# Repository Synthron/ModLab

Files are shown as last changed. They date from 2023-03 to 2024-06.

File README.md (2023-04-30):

# ModLab

## A modular station for your electronic workbench

The ModLab is designed to be housed in a 19" Rack with 3U.  
It is the improved version of the (failed) Arduino Workstation I built a long time ago.

But now It will be bigger, better and way too complicated.

---

[GitHub](https://github.com/Synthron/ModLab)
[Gitlab](https://gitlab.synthron.de/Synthron/ModLab)

---

**Work in Progress**

---

# To-Dos

## Repo

- [X] Rewrite documentation in english
  - [ ] Write better introduction
  - [ ] explain what exactly the ModLab is
  - [X] update changes for TFT
  - [X] Explain TFT Protocol
  - [ ] Attach Schematics
- [X] Cleanup Repo

---

## Hardware

- [X] Redesign modules with STM32
  - [x] Master Bus Controller with F767
    - [X] V1
      - [X] Review
      - [X] Ordered
      - [X] Assembled
    - [ ] V2
      - [ ] Change LCD connector
      - [ ] omit external SRAM
      - [ ] include header for Reset
  - [x] Diode/LED-Tester
    - [X] V1
    - [X] V2
  - [X] Variable Power Supply
    - [X] V1
    - [ ] V2
      - [X] Fix Relais Footprint
      - [X] Feedback Dividers for correct level
      - [ ] Review
      - [ ] Ordered
      - [ ] Assembled
  - [x] Symmetric Power Supply
    - [X] V1
    - [ ] V2
      - [X] fix negative channel
      - [X] fix CC LEDs
      - [ ] Review
      - [ ] Ordered
      - [ ] Assembled
  - [x] Waveform generator
  - [ ] DSO-138 clone?
  - [X] Electronic Load
  - [ ] Logic Tester
  - [ ] Continuity tester
  - [ ] Speaker Module
  - [x] Termination boards and Bus Extenders

---

## Software

- General
  - [X] Define CAN Protocol
    - [X] Define Command Structure
    - [X] Define Data Structure
- Master Bus Controller
  - [ ] STM32 code
    - [X] USB for Debug
    - [X] LCD
      - [X] Get Nextion Display working
        - [X] UI
        - [X] µC Interface
    - [ ] Busses
      - [X] CAN
      - [ ] SPI - No Usecase so far
      - [ ] I2C
      - [ ] DAC - No Usecase so far
      - [ ] RS485 - No Usecase so far
  - [ ] ESP32 code
    - [ ] comm with STM
    - [X] OTA
    - [ ] basic web interface
- Diode Tester code
  - [X] CAN
  - [X] Testing Sequence
  - [X] ADC
- SymPSU
  - [X] PWM Signals
  - [X] ADC
  - [X] CAN-Interface
- Power SMPS
  - [X] PWM Signals
  - [X] ADC
  - [X] CAN-Interface
- Waveform Generator
  - [X] PWM Signals
  - [X] AD9833
  - [X] CAN-Interface
- Power Monitor
  - [ ] Voltage Measurement
  - [ ] Current Measurement
  - [ ] I2C communication

---

ModLab Lib Tracker:

1. SymPSU
2. Diode-Tester
3. SMPS
4. Load
5. F-Gen

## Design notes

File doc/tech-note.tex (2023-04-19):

% --------------------------------------------------------------------
% Technical Documentation
% Marco Müller
% --------------------------------------------------------------------

\documentclass[11pt, a4paper, listof=numbered, captions=tableheading, headinclude, table, xcdraw]{scrreprt}
\usepackage[utf8]{inputenc}
\usepackage{babel}
\usepackage{tikz}
\usepackage{epigraph}
%\usepackage[T1]{fontenc}
\usepackage{xcolor}
\usepackage{amsmath}
\usepackage{textgreek}
\usepackage[LGRgreek]{mathastext}
\usepackage{array}
\usepackage{color}
\usepackage{graphicx}
\usepackage{float}
\usepackage{helvet}
\usepackage{scrhack}
\usepackage{makecell}
\renewcommand{\familydefault}{\sfdefault}

\setcounter{secnumdepth}{4} % give subsubsection numbers

\setlength{\emergencystretch}{\hsize}
\tolerance=9999

\newcounter{divide}

% für referenziertes Inhaltsverzeichnis
\usepackage[hidelinks, hypertexnames=false]{hyperref}

\usepackage{chngcntr}
\counterwithin*{chapter}{divide}

\renewcommand\epigraphflush{flushright}
\renewcommand\epigraphsize{\normalsize}
\setlength\epigraphwidth{0.7\textwidth}

\definecolor{titlepagecolor1}{cmyk}{.82,.24,0,.11}
\definecolor{titlepagecolor}{cmyk}{0,.33,.98,.2}

\DeclareFixedFont{\titlefont}{T1}{ppl}{b}{it}{0.5in}

\setlength{\parindent}{0pt}

% Seitenränder festlegen
\usepackage[top=1.5cm,bottom=1.5cm,right=2.5cm,left=2.5cm,includeheadfoot]{geometry}

% ---------------------------------------
% Titeldefinition
\newcommand{\Titel}{Documentation\\\vspace{.5mm}ModLab V3.0}
\newcommand{\Caption}{A modular electronics workstation}
\newcommand{\SignateAuthor}{\textit{Made with \LaTeX}}
\newcommand{\Stand}{\textit{Compiled: \today}}
% Sonstiges in titel.ltx und titel-meta.ltx
% ---------------------------------------

% Kopf- und Fußzeile
\usepackage[automark]{scrlayer-scrpage}

% --------------------------------------------------------------------
% Titelblatt
% --------------------------------------------------------------------

\input{titel/titel-meta.tex}
\begin{document}
\input{titel/titel.tex}

\KOMAoptions{parskip=half}
% --------------------------------------------------------------------
% Verzeichnisse
% --------------------------------------------------------------------

\pagenumbering{Roman}
\renewcommand{\thechapter}{\Roman{chapter}}

\setcounter{tocdepth}{1} %Ausblenden von Subsections etc..
\cohead[I Table Of Contents]{I Table Of Contents}
\pagestyle{scrheadings}
\tableofcontents 	\newpage
\cohead[II List of Tables]{II List of Tables}
\pagestyle{scrheadings}
\listoftables 		\newpage
\cohead[III List of Figures]{III List of Figures}
\pagestyle{scrheadings}
\listoffigures 		\newpage
\pagenumbering{arabic}

\stepcounter{divide}

\renewcommand{\thechapter}{\arabic{chapter}}

% Kopfzeilen erst nach den Verzeichnissen

\lohead[\today]{\today}
\cohead[ModLab V3.0]{ModLab V3.0}
\rohead[Synthron]{Synthron}
\pagestyle{scrheadings}

% --------------------------------------------------------------------
% Ab hier der Inhalt
% --------------------------------------------------------------------

\input{chapters/00-vorwort.tex} 			\newpage 	% Vorwort über die Entstehungsgeschichte
\input{chapters/01-rack.tex}				\newpage 	% Der Rackaufbau und Erläuterung
\input{chapters/02-fmas.tex}				\newpage 	% Kurze Ausführung zum FMAS
\input{chapters/03-modlab.tex}				\newpage 	% Systemüberblick und Einführung ModLab, 
\input{chapters/04-der_bus.tex} 			\newpage 	% Backplanebus
\input{chapters/10-modules.tex}				\newpage 	% Modules
\input{chapters/20-protocols.tex}			\newpage	% Protocol
\input{chapters/21-CAN.tex}\newpage
\input{chapters/22-TFT.tex}\newpage
\section{ESP SPI}
\textbf{\textcolor[HTML]{FF0000}{TBD}}

\section{Backplane SPI}
\textbf{\textcolor[HTML]{FF0000}{TBD}}
\subsection{5V SPI}
\textbf{\textcolor[HTML]{FF0000}{TBD}}
\subsection{3V3 SPI}
\textbf{\textcolor[HTML]{FF0000}{TBD}}

\section{I2C}
\textbf{\textcolor[HTML]{FF0000}{TBD}}
\subsection{Standard Mode}
\textbf{\textcolor[HTML]{FF0000}{TBD}}
\subsection{Fast Mode}
\textbf{\textcolor[HTML]{FF0000}{TBD}}

% --------------------------------------------------------------------
% abschließende Verzeichnisse
% --------------------------------------------------------------------
\newpage
\appendix
\pagestyle{empty}
\vspace*{\fill}
\begin{center}
\hrulefill\\
\vspace{4mm}
	\begin{HUGE}
		\textbf{Addenda}
	\end{HUGE}\\
\hrulefill\\
\end{center}
\vspace*{\fill}

\pagestyle{plain}

\chapter{Mainboard Schematic}
\newpage
\newpage
\newpage


\chapter{Bustermination Schematic}


\chapter{Diode Tester Schematic}
\newpage

\chapter{Symmetric Power Supply Schematic}
\newpage
\newpage
\newpage
\newpage
\newpage


\chapter{Switching Mode Power Supply Schematic}
\newpage
\newpage
\newpage


\chapter{Electronic Load Schematic}
\newpage
\newpage
\newpage
\newpage


\chapter{Waveform Generator Schematic}
\newpage
\newpage
\newpage


% --------------------------------------------------------------------
\end{document}

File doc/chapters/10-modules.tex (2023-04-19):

\chapter{ModLab Modules}
This chapter is \textbf{Work in Progress} and thus subject to change at any time!

Here I wanna give you a brief overview over the modules (no particular order). Each one will be discussed in more detail, so no worries. 

I will also mark everything that is currently just a concept or idea with a (c) behind its name. 

\begin{itemize}
	\item Bus Adapter
	\begin{itemize}
		\item 1:1 Extension of the backplane bus with connector at the front
		\item Termination resistors for differential pairs
		\item LED indicators for supply voltages
	\end{itemize}
%-------------------------
	\item Host-Bus-Controller / HBC
	\begin{itemize}
		\item Brain of the ModLab
		\item Master for all backplane interfaces
		\item 5'' TFT LCD with touch
		\item ESP32 Co-Processor
		\item SD card slot for logging and more
		\item USB interface
	\end{itemize}
%-------------------------
	\item Symmetric Linear Power Supply
	\begin{itemize}
		\item Symmetric regulated Voltage
		\item Both CC and CV modes
		\item Controlled via PWM
	\end{itemize}
%-------------------------
	\item Symmetric Switching Mode Power Supply (c)
	\begin{itemize}
		\item Single regilated Voltage
		\item Both CC and CV modes
		\item Controlled via PWM
	\end{itemize}
%-------------------------
%	\item Linear Power Supply (c)
%\begin{itemize}
%	\item Stromversorgung mit größerer Leistung
%	\item Spannungs- und Stromgeregelt
%	\item Co-Prozessor übernimmt Regelung
%\end{itemize}
%-------------------------
	\item Switching Mode Power Supply
	\begin{itemize}
		\item High-current power supply
		\item Both CC and CV modes
		\item Controlled via PWM
	\end{itemize}
%-------------------------
	\item Waveform Generator Analog (c)
	%\begin{itemize}
	%	\item MAX038 als Generatorbaustein
	%	\item Sinus, Rechteck und Dreieck
	%	\item Ansteuerung eventuell über Co-Prozessor
	%\end{itemize}
%-------------------------
	\item Waveform Generator DDS
	\begin{itemize}
		\item AD9833 Waveform Generator
		\item 0.1Hz to 12.5MHz
		\item Sine wave, triangle and square wave
		\item VCA and Output Driver
	\end{itemize}
%-------------------------
	\item Logic Probe Tester (c)
	%\begin{itemize}
	%	\item Kann Pegel registrieren und gibt Pegelhöhe an
	%	\item Kann Low-Power Rechteck generieren um Signalbahnen zu verfolgen
	%	\item Test-Probes mit Pogo-Pins
	%	\item Tastköpfe aus 3D-Drucker
	%\end{itemize}
%-------------------------
	\item Diode Tester
	\begin{itemize}
		\item 4 different constant current sources
		\item capable of creativ characteristic curves
		\item Co-Prozessor übernimmt Regelung
	\end{itemize}
%-------------------------
	\item Electronic Load
	\begin{itemize}
		\item Resistive Load for up to 15A
		\item Two Channels
		\item Load Limiter with thermocouple on Heatsink
	\end{itemize}
%-------------------------
	\item Speaker Module (c)
	%\begin{itemize}
	%	\item Signaltöne für verschiedene Angelegenheiten
	%	\item Hochgefahren, Störung, Durchgang etc...
	%	\item zwei Lautsprecher, einer für Melodie, einer für Signal
	%\end{itemize}
%-------------------------
	\item Oscilloscope
	%\begin{itemize}
	%	\item China Einkanal-Oszi auf Eurokarte portiert
	%	\item Für schnelle Tests von langsamen Signalen
	%\end{itemize}
%-------------------------
\end{itemize}

%------------------------------------------------------------------------------------------------------------------------

\section{Bus Adapter}
The Bus Adapter is one of the first modules. It's main function is to terminate the differential bus lanes. For this reason the Bus Adapter is made twice to terminate each end of the backplane. 

Also it serves as an extension to the backplane, since each module has a connector on its front panel serving as a 1:1 connection to the backplane. This way the slot doesn't get wasted for nearly no function.

In addition to that, each supply voltage has a dedicated LED to show if the voltage is available or if a fuse has blown. 

And that is all there is to it. 

%------------------------------------------------------------------------------------------------------------------------

\section{Host Bus Controller}
The Host Bus Controller (HBC) is the heart of the ModLab. It acts as master for the backplane busses as well as user interface. Since it is quite a busy module, I'll try my best to explain each function seperately

\begin{figure}[H]
	\centering
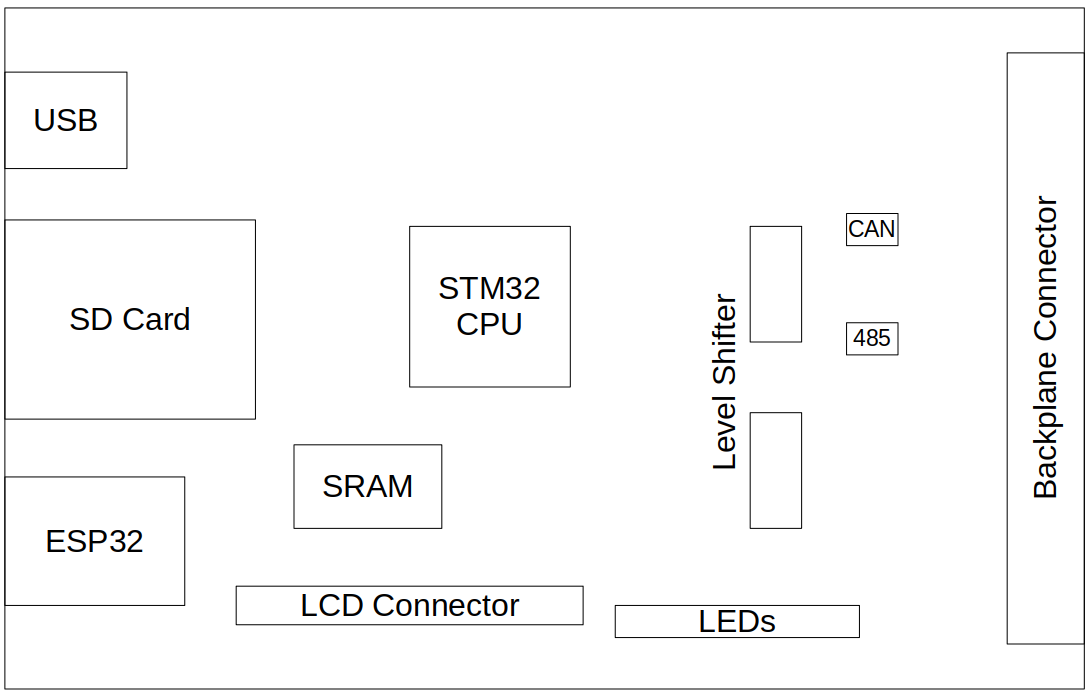
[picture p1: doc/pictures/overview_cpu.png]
		
	\caption{PCB Overview HBC}
	\label{img:HBC}
\end{figure}

\subsection{CPU}

The core of the HBC is the STM32F767 microcontroller. It controls everything in the entire system and provides the user interfaces. 

With 2MB of Flash and 512kB RAM it has more than plenty of storage both for the program code as well as process data and variables. Also at 216MHz max clock rate it is really fast and can process everything in a timely manner. At least that was the thought behind choosing this chip. 

\subsection{Additional Hardware}

Also it has a lot of interfaces which are used on the PCB. Additionally to the interfaces mentioned in chapter 5.4, internally the module has two SPI busses, one for the touch controller and one for the ESP32 coprocessor. A USB interface for debugging and monitoring is inlcuded as well. 

For logging and config storage I included an SD card slot. 

The FSMC (Flexible SRAM Memory Controller) interface of the microcontroller is connected to an external 512k x 16 SRAM chip. I thought about including an external flash memory for application software, but decided against it, since the internal flash seemed more than enough. The external SRAM might come in handy tho if I decide to build modules like logic analyzers which have a ton of data coming in at once. 

The ESP32 module will provide a webinterface for monitoring and diagnosis, but not for controlling the system. This decision was made from a security stand point. 

For Interfacing with the whole system, a 5" Nextion TFT LCD is connected via UART. 

How the protocols on the interfaces will look like, will be discussed in another chapter. 

%------------------------------------------------------------------------------------------------------------------------

\section{Diode Tester}
The Diode Tester is actually quite simple in design. It consists of 4 constant current sources which are tuned to about 2.2mA, 5mA, 10mA and 20mA respectively. Due to this I can enable up to 16 different currents through the Device Under Test (DUT) and even make a crude characteristic curve out of it. 
Following is a simplified schematic of the current sources.

\begin{figure}[H]
	\centering
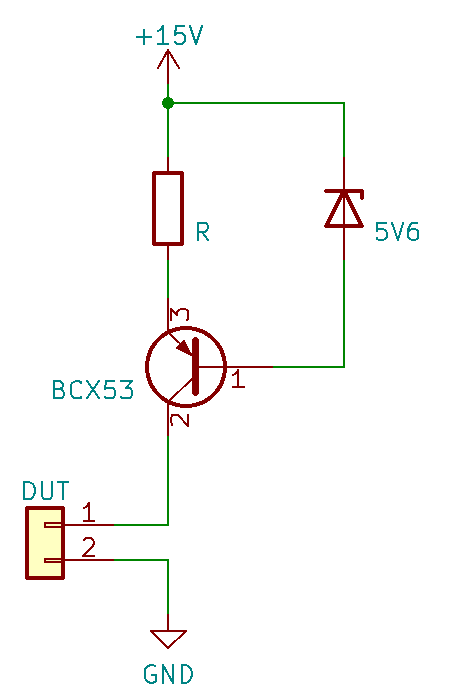
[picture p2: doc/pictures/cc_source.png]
		
	\caption{Current Source Schematic}
	\label{img:CC_Diode}
\end{figure}

The current is configured via the resistor according to Kirchhoff's loop rule. $U_{be}$ of the transistor is typically 0.7V, which means the voltage across the resistor is fixed at $5.6V - 0.7V = 4.9V$. With the values of 2.2k, 1k, 499 and two 499 in parallel respectively, the following currents are available:

\begin{align*}
	\frac{4.9V}{2.2 k\Omega} & = 2.22 mA\\
	\frac{4.9V}{1 k\Omega}  & = 4.9  mA\\
	\frac{4.9V}{499 \Omega} & = 9.81 mA\\
	\frac{4.9V}{249.5 \Omega} & = 19.63 mA\\
\end{align*}

In V1 I tried to enable the sources via a P-channel MOSFET, which for some strange reason didn't work. So I decided for V2 to use small reed relais I had in storage. 

\vspace{1cm}

The module also has an STM32F103 controller on board which is connected to the backplane via CAN and I2C. I did both since I hadn't yet decided which interface I am going to use for the module. 

\subsection{Parameters}
\begin{table}[H]
    \centering
    \begin{tabular}{|c|c|l|}
        \hline
        \textbf{No.}   &   \textbf{Size} & \multicolumn{1}{|c|}{\textbf{Description}}\\ \hline \hline
        10h   &  2 Byte & DUT Voltage at 2 mA \\ \hline
		11h   &  2 Byte & DUT Voltage at 5 mA \\ \hline
		12h   &  2 Byte & DUT Voltage at 7 mA \\ \hline
		13h   &  2 Byte & DUT Voltage at 10 mA \\ \hline
		14h   &  2 Byte & DUT Voltage at 12 mA \\ \hline
		15h   &  2 Byte & DUT Voltage at 15 mA \\ \hline
		16h   &  2 Byte & DUT Voltage at 17 mA \\ \hline
		17h   &  2 Byte & DUT Voltage at 20 mA \\ \hline
		18h   &  2 Byte & DUT Voltage at 22 mA \\ \hline
		19h   &  2 Byte & DUT Voltage at 25 mA \\ \hline
		1Ah   &  2 Byte & DUT Voltage at 27 mA \\ \hline
		1Bh   &  2 Byte & DUT Voltage at 30 mA \\ \hline
		1Ch   &  2 Byte & DUT Voltage at 32 mA \\ \hline
		1Dh   &  2 Byte & DUT Voltage at 35 mA \\ \hline
		1Eh   &  2 Byte & DUT Voltage at 37 mA \\ \hline
		20h   &  1 Byte & Starting Current	\\ \hline
		21h   &  1 Byte & Ending Current \\ \hline
    \end{tabular}
	\caption{Diode Tester Parameter List}
\label{tab:Par-Diode}
\end{table}
\subsection{Operation Modes}
Start Measurement with ``Enable Output'' Command.

\begin{table}[H]
    \centering
    \begin{tabular}{|c|c|l|}
        \hline
        \textbf{Mode}   &  \multicolumn{1}{|c|}{\textbf{Description}}\\ \hline \hline
        0   &  \makecell[l]{Single Value Measurement \\ Starting Current only}\\ \hline
		1   &  \makecell[l]{Coarse Characteristic Curve \\ Starting Current to Ending Current \\ Only Hardware Sources enabled}\\ \hline
		2   &  \makecell[l]{Medium Characteristic Curve \\ Starting Current to Ending Current \\ Every other possible current}\\ \hline
		3   &  \makecell[l]{Fine Characteristic Curve \\ Starting Current to Ending Current \\ Every possible current}\\ \hline
    \end{tabular}
	\caption{Diode Tester Parameter List}
\label{tab:Modes-Diode}
\end{table}
\section{Waveform Generator DDS}
For most of the design I have to thank ``Daumemo'' from \textcolor{blue}{\href{https://daumemo.com}{daumemo.com}}. I wanted to use the AD9833 waveform generator IC and his guide helped me design the circuit around it. 

The board mainly consists of the STM32F103 controller, the AD9833 signal generator, a VCA (voltage controlled amplifier) and an output amplifier. Gain and Offset are controlled via PWM, the Interface to the AD9833 is SPI. 

The Signal Generator is capable of generating Sine, Triangle and Square waves from 1Hz up to 12.5MHz with a 1Hz resolution. 

\subsection{Parameters}
\begin{table}[H]
    \centering
    \begin{tabular}{|c|c|l|}
        \hline
        \textbf{No.}   &   \textbf{Size} & \multicolumn{1}{|c|}{\textbf{Description}}\\ \hline \hline
        10h   &  4 Byte &  Set Frequency [1Hz]\\ \hline
		20h   &  2 Byte &  Set Vout Peak-Peak [0.1V]\\ \hline
		30h	  &  2 Byte &  Offset Voltage [0.1V] \\ \hline
    \end{tabular}
	\caption{AD9833 Parameter List}
\label{tab:Par-Waveform9833}
\end{table}
\subsection{Operation Modes}
\begin{table}[H]
    \centering
    \begin{tabular}{|c|c|l|}
        \hline
        \textbf{No.}   & \multicolumn{1}{|c|}{\textbf{Description}}\\ \hline \hline
        0h   &  Square Wave\\ \hline
		1h   &  Sine Wave\\ \hline
		2h	 &  Triangular Wave \\ \hline
    \end{tabular}
	\caption{AD9833 Waveforms List}
\label{tab:mode-Waveform9833}
\end{table}

\section{Symmetric Linear Power Supply (SymPSU)}
The design for the symmetric power supply is derived from the user ``The Big One'' over on \textcolor{blue}{\href{https://hackaday.io/project/4154-bench-power-supply}{Hackaday}}. I adopted it to my STM32 controller and to 3V3 supply voltage. Also I switched the control voltage generation from a dedicated DAC to the PWM-channels of the STM32. I am using the internal ADC on the STM32 as well. 

With these design changes, the SymPSU can provide the following voltages:
\begin{itemize}
	\item Positive voltage
	\begin{itemize}
		\item 0 to 12V @ 0 to 1.2A
	\end{itemize}
	\item Negative voltage
	\begin{itemize}
		\item 0 to -12V @ 0 to 1.2A
	\end{itemize}
\end{itemize}

After tweaking the code, I programmed the following resolutions:

\begin{itemize}
	\item Voltages
	\begin{itemize}
		\item 10 mV / step
	\end{itemize}
	\item Currents
	\begin{itemize}
		\item 10 mA / step
	\end{itemize}
\end{itemize}

I am quite happy with these specs, but will likely tweak the design in the future a bit. I still have some issues that are currently fixed in software, rather than in hardware. 

\subsection{Parameters}
\begin{table}[H]
    \centering
    \begin{tabular}{|c|c|l|}
        \hline
        \textbf{No.}   &   \textbf{Size} & \multicolumn{1}{|c|}{\textbf{Description}}\\ \hline \hline
        10h   &  2 Byte &  Set Positive Voltage [mV]\\ \hline
		11h   &  2 Byte &  Set Positive Current [mA]\\ \hline
		12h   &  2 Byte &  Set Negative Voltage [mV]\\ \hline
		13h   &  2 Byte &  Set Negative Current [mA]\\ \hline
		20h   &  2 Byte &  Measured Positive Voltage [mV]\\ \hline
		21h   &  2 Byte &  Measured Positive Current [mA]\\ \hline
		22h   &  2 Byte &  Measured Negative Voltage [mV]\\ \hline
		23h   &  2 Byte &  Measured Negative Current [mA]\\ \hline
    \end{tabular}
	\caption{SymPSU Parameter List}
\label{tab:Par-SymPSU}
\end{table}

\section{Switching Mode Power Supply}
This Power Supply is based on a TL494 PWM Control Circuit. The PWM Controller is getting the reference voltages for Output Voltage and Current from the STM32 via filtered PWM signals. This way a complicated and possibly slow and inaccurate software PID regulator is avoided while the circuit complexity is held at a minimum. A voltage divider is generating the feedback voltage, while a high-current shunt and differential amplifier is generating the feedback voltage for the current. 

The following specs were set for Rev 1. This module will need a redesign in order to fix some mistakes.

\begin{itemize}
	\item Voltage
	\begin{itemize}
		\item 2 .. 22 V Output
		\item 10 mV resolution
	\end{itemize}
	\item Current
	\begin{itemize}
		\item 0 .. 5 A Output
		\item 10 mA resolution
	\end{itemize}
\end{itemize}

\subsection{Parameters}
\begin{table}[H]
    \centering
    \begin{tabular}{|c|c|l|}
        \hline
        \textbf{No.}   &   \textbf{Size} & \multicolumn{1}{|c|}{\textbf{Description}}\\ \hline \hline
        10h   &  2 Byte &  Set Voltage [10mV]\\ \hline
		11h   &  2 Byte &  Set Current [10mA]\\ \hline
		20h   &  2 Byte &  Measured Voltage [10mV]\\ \hline
		21h   &  2 Byte &  Measured Current [10mA]\\ \hline
    \end{tabular}
	\caption{SMPS Parameter List}
\label{tab:Par-SMPS}
\end{table}

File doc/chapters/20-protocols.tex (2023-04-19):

\chapter{Interface Protocols}
As the system is quite big and has a lot of interfaces, here will be the place to discuss all these. 

Mainly the USB-Interface, SPI-Interface for the ESP32-Communication and CAN-Interface are of interest. But also the secondary I2C and general SPI interfaces will be defined here. 

\section{USB Monitor}
\textbf{\textcolor[HTML]{FF0000}{TBD}}

USB is currently only used to log the CAN traffic of the system, if the debug-option on the display is set. This will be expanded in the future by a complete USB monitor which will have many different capabilities such as sending CAN frames, setting variables inside the Mainboard and basically letting the ModLab be controlled via USB. 

More on this will be a subject for the future tho.

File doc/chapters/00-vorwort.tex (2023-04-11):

\chapter{Introduction}

This documentation is descibing the origins, design choices and inner workings of the ModLab. The ModLab is a modular electronics workstation designed from scratch and built with mostly readily available parts. 

It is the successor of my Arduino Workstation which was meant to be a better version of the FMAS (\textit{\textbf{F}lexibles \textbf{M}odulares \textbf{A}usbildungs-\textbf{S}ystem}, Flexible Modular Training System) I made during my apprenticeship at the Karlsruhe Institute of Technology. The backplane on the FMAS consisted entirely of AC voltages and one 9V DC voltage which is not really ideal. Also it was all pure logic with no programmable parts. This made it quite functional but stupid (not dumb, but no programmable parts), so I decided to improve on it. 

With the ModLab I wanted to finally build my dream system. With the motto ``absolutely over-engineered'' it is supposed to be powerful, better planned and more intelligent. Also the 19``-Rack houses the FMAS as well, to show the roots of it (and also I didn't want to scrap it because of nostalgia). 

The Arduino Workstation was my first attempt and (from my current perspective) served only as a proof of concept. My skills were quite low at that time and all I knew was Arduino, so I went with that. It kinda worked, but was not really useful and since I made some bad design choices, I had to scrap it. But it was a start and laid out a foundation. 

V2 isn't really documented, because a) it was utter crap and b) it didn't work. I used an Arduino DUE board as main controller which did the job, but not really well\dots

The current version is V3 and is under development. It uses primarily STM32 controllers, but still has the capability of using other controllers as well. 

Before I start talking about all the modules, I want to talk a bit about the FMAS and the Rack itself, so bear with my ramblings and enjoy reading.

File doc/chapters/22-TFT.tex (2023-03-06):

\section{TFT Display}
The Communication Interface with the TFT display is a 5V TTL UART with 250.000 baud of standard 8N1 protocol.

\subsection{HBC to TFT}
For sending commands or instructions to the TFT display, everything needs to be in ASCII followed by 3 Bytes of 0xFF. 

Nearly all commands directly set properties of the elements placed on screen. For example setting the value of a floating point number (here: Element name x1) with two decimal places to the value ``3.30'' would be as follows:

``\textcolor{orange}{x1.val=330}''

Note, that no decimal point is set. The display can only handle integer numbers. Decimal points are handled by the corresponding number box element on screen. 

Here is an overview of the most important commands for Interfacing. All examples are made with textbox t1 and float number x1.

\begin{table}[H]
    \centering
    \begin{tabular}{|c|l|}
        \hline
        \textbf{Command}  & \multicolumn{1}{|c|}{\textbf{Description}}\\ \hline \hline
        t1.txt=``foo'' & set text \\ \hline
        t1.aph=127 & set opacity to fully visible \\ \hline
        x1.val=330 & set numeric value \\ \hline
        vis t1,0 & set textbox invisible. a 1 at the end makes it visible again \\ \hline
    \end{tabular}
\label{tab:tft_overview}
\end{table}

\subsection{Change Device Page}
So far, every module class has its own page on the display. So only these modules need to be actively monitored. 

If the user changes the page, the following command will be sentby the TFT: 

``\textcolor{orange}{0x55 0x\#\#}''where \#\# is the following number:

\begin{table}[H]
    \centering
    \begin{tabular}{|c|l|}
        \hline
        \textbf{Number}  & \multicolumn{1}{|c|}{\textbf{Description}}\\ \hline \hline
        00h & Home Screen / General Settings\\ \hline
        01h & Diode Tester \\ \hline
        02h & Function Generator \\ \hline
        03h & Symmetrical Power Supply \\ \hline
        04h & Switching Mode Power Supply \\ \hline
    \end{tabular}
\label{tab:tft_pagecmd}
\end{table}

\subsection{Set Input Process Data}
Depending on the module, this command can have a variable length of data trailing it. The general instruction across all modules begins with ``\textcolor{orange}{0x5C}''.

\begin{table}[H]
    \centering
    \begin{tabular}{|c|l|}
        \hline
        \textbf{length}  & \multicolumn{1}{|c|}{\textbf{Description}}\\ \hline \hline
        1 byte & Module ID\\ \hline
        1 byte & Operation mode \\ \hline
        1 byte & Start Current Index \\ \hline
        1 Byte & Stop Current Index \\ \hline
    \end{tabular}
\caption[Data Structure Diode Tester]{Data Structure Diode Tester}
\label{tab:tft_diode_5C}

\end{table}
\begin{table}[H]
    \centering
    \begin{tabular}{|c|l|}
        \hline
        \textbf{length}  & \multicolumn{1}{|c|}{\textbf{Description}}\\ \hline \hline
        1 byte & Module ID\\ \hline
        4 byte & Frequency - LSB first \\ \hline
        2 byte & Amplitude - LSB first \\ \hline
        2 byte & Offset - LSB first \\ \hline
    \end{tabular}
\caption[Data Structure Function Generator]{Data Structure Function Generator}
\label{tab:tft_fgen_5C}
\end{table}

\begin{table}[H]
    \centering
    \begin{tabular}{|c|l|}
        \hline
        \textbf{length}  & \multicolumn{1}{|c|}{\textbf{Description}}\\ \hline \hline
        1 byte & Module ID\\ \hline
        2 byte & Positive Voltage - LSB first \\ \hline
        2 byte & Positive Current - LSB first \\ \hline
        2 byte & Negative Voltage - LSB first \\ \hline
        2 byte & Negative Current - LSB first \\ \hline
    \end{tabular}
\caption[Data Structure Symmetric Power Supply]{Data Structure Symmetric Power Supply}
\label{tab:tft_sympsu_5C}
\end{table}

\subsection{Set Output}
The Set Output instruction only exists for modules that actually have a disconnectable output. The command generally follows the format ``\textcolor{orange}{0x50 0xIS}'', where I is the module sub-ID (numbered 1-4) and S is the state of the output (0 = off, 1 = on). 

\subsection{General Settings (Home Screen)}
General settings are mostly for debug purposes, but can be activated and deactivated on the home screen. The instruction begins with ``\textcolor{orange}{0x5A}'' and is followed by the data below:

\begin{table}[H]
    \centering
    \begin{tabular}{|c|l|}
        \hline
        \textbf{Data}  & \multicolumn{1}{|c|}{\textbf{Description}}\\ \hline \hline
        10h & Disable CAN-Log over USB \\ \hline
        11h & Enable CAN-Log over USB \\ \hline
        20h & Disable TFT-Log over USB \\ \hline
        21h & Enable TFT-Log over USB \\ \hline
        30h & Don't simulate missing modules \\ \hline
        31h & Simulate all missing modules \\ \hline
    \end{tabular}
\label{tab:tft_5A}
\end{table}

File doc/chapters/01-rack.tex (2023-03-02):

\chapter{The Rack}
As I said in the introduction, the ModLab actually consists of two parts. To keep it simple, I will do the following: If I speak about the ModLab, I mean the ModLab itself in the upper 6U. The rack itself (which will be explained here) and the FMAS are talked about seperately. 

So now let's talk about the rack.

\section{The Idea}
When I sat down at the drawing board (ok, I admit, it was Excel...) and the first thoughts in mind had, I quickly decided to make everything just bigger. The reason was, that just one 3U rack was a bit too small (e.g. the FMAS rack only had 6 slots, but 12 available modules). Coincidentally I got my hands on a 20U 19``-rack which should be plenty for my use. But now there was a new issue: next to being big and heavy, I needed to include an electric installation for the subsystems. But this will be tackled a bit later.

\section{Planning it out}
Planning out the sections of the rack was done in Excel, so no big calculations for you here, but oh well\dots

So I had 20U to spend and I had a lot to put in there. Thankfully, the rack has a front and a back side. For convenience I decided the ``user side'' would be only on the front, the installation and support systems would be on the back. The first thought was that the whole front would consist of 3U subracks, but that would be a bit much and I still needed the control circuits as well as cable channels, power supplies etc. 

I decided to dedicate two 3U subracks to the ModLab and the FMAS respectively, this would reserve 5U for the control panel and cable management. This way, I can save up space on my workbench by storing the FMAS as well as having plenty of space for the ModLab modules.

After a bit of time, I came up with the following. I am quite happy how it turned out, so this will hopefully last until the end of it.

\begin{table}[H]
\centering
\begin{tabular}{|r|c|c|}
\hline
\textbf{U}	&	\textbf{Front}	&	\textbf{back}		\\ \hline \hline
20	&			&	Cover Plate		    \\ \cline{1-1}
19	&	ModLab	&	Power Supplies		    \\ \cline{1-1}
18	&			&	24V \& 5V		    \\ \hline
17	&			&	Cover Plate		    \\ \cline{1-1}
16	&	ModLab	&	Power Supplies	    \\ \cline{1-1}
15	&			&	15V \& -15V	        \\ \hline
14	&			&	Cover Plate         \\ \cline{1-1}
13	&	Control Panel	&	Filter		\\ \cline{1-1}
12	&			&	Fuses			        \\ \hline
11	&	    	&	            		\\ \cline{1-1}
10	&	DIN-Rail	&	DIN-Rail		\\ \cline{1-1}
9	&	        &                   	\\ \cline{1-1}
8   &           &                       \\ \cline{1-1}
7	&	Cable Channel	&	Cable Channel		\\ \hline
6	&			&	Cover Plate		    \\ \cline{1-1}
5	&	FMAS	&	Voltage Regulator   \\ \cline{1-1}
4	&			&	Fuses	        \\ \hline
3	&			&	Cover Plate		    \\ \cline{1-1}
2	&	FMAS	&	Mains Connector	    \\ \cline{1-1}
1	&			&	Transformer			    \\ \hline

\end{tabular}
\caption{Rack Overview}
\label{tab:Rack Overview}
\end{table}

\section{Construction}
So I ordered everything I needed and took some time to draw schematics, drill out the cover plates, assemble everything and soon I was done.

Well, if only it was that easy\dots

I took my time for every step just to avoid big errors. I made the electric schematic with the software ``QElectroTech'' and even of this schematic, there are many revisions. 

With the plan done, I finally knew what devices and how many terminal blocks I needed. With this in mind I was able to prepare the cover plates and assemble them. In the meantime I designed the backplane for the ModLab, so I could already order them and assemble the subracks. 

The control panel is used to enable power to the different parts of the rack as well as being home to the most important big red ``OH SHIT''-button. This way, only the parts that will be used are powered. The main control voltage is enabled by a seperate switch for a bit more extra safety. 

The switched power supplies for the ModLab made me some headaches. According to their datasheets they can use up to 40A at 230V in the moment of power-up. Since I got four of them in parallel, I was worried about the 160A current spike in the mains blowing the fuses in my fusebox. So I got a current limiter which is actively limiting the current during the first 70ms of power-up and then switching over to unlimited. This will definitely save my fusebox as well as the cables in the wall (and not to forget the contacts in the relais making the connections). 

The transformer for the FMAS is the original one used for it, so the old rack for it got completely disassembled. 

\vspace{1cm}

While the power lines for the FMAS are soldered directly to the backplanes of the subracks, I decided to use high-current DIN 41612 H15-connectors for the ModLab. This way I can partially disassemble the rack for transportation or make it easier to make changes or upgrades to the rack or subracks. Also the connectors are made for use in 3U subracks, so easy to implement and with the use of cable slugs really modular.

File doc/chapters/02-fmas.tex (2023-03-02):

\chapter{FMAS}
Now let's talk about the FMAS, what it is and why I keep in in my inventory.

\section{Background}
The FMAS, or \textit{\textbf{F}lexibles \textbf{M}odulares \textbf{A}usbildungs-\textbf{S}ystem} (Flexible Modular Training System), was part of my apprenticeship at the Karlsruhe Institute of Technology (KIT). It was used to teach how to design schematics, how to draw layouts and how to make PCBs (yes, we etched our own PCBs). Furthermore we were taught how to use measurement equipment, since once a PCB didn't work, the trainer basically just told us ``here are multimeter and oscilloscope, find your error''. As rude as that sounds, it made us think about the circuit, trace the signals around and see where we made the error. 

The FMAS itself was built in a 3U rack with full enclosure, including the transformer, fuses and a regulator. We trainees built them ourselves from the provided kits.

The further along we were with training, the more modules we had for it. During vacation when vocational school was closed or when we had nothing better to do (which happened to me a lot. I was a big nerd and quite fast compared to my fellow trainees) we made the modules for the FMAS, the documentation for it (after 4 or 5 modules, we had quite a good template for it, so that wasn't too much work) and then asked for the next project. 

\section{The System}
The FMAS itself was not up-to-date or highly integrated. The backplane bus consisted of 9V DC as well as 12V, 24V and 20V-0-20V AC voltages. All the other available lanes were unconnected and unused. So it got me thinking. 

The modules themselves were completely discrete, so no programmable ICs or microcontrollers. A big advantage in case of there were no software bugs and to be honest, the circuits just \textit{worked}. Also it was not necessary to contemplate life choices over forgotten semikolons in the code while debugging for days with not much knowledge about programming. It just made life to our trainers and for us way easier. 

The disadvantage I see on the concept itself. Nearly only AC voltages on the backplane means that we had to rectify, filter regulate the voltage on nearly every module. Also there was lots of space on the backplane to make something interesting. With relatively low effort one could connect the modules over serial interfaces with one another and make something interesting and a little bit more intelligent and up-to-date. 

But as the motto goes: ``never change a running system'', so my trainers were not willing to change it.

\section{Modules}
The modules themselves are nothing special, but I will give you a list of them here. 

\begin{itemize}
\item Power Supplies: simple power supplies with LM317 and LM337 as well as one with LM723
\item LED-Tester: Current Source and Voltmeter
\item Waveform Generators: Discrete (fixed frequency) in different designs as well as a X2206CP-function generator
\item Signal Tracer: a square wave generator with integrated speaker
\item Logic Probe Tester: shows the logic level on a trace, simple discrete circuit
\item LED-dice: your standard 1-6 dice...
\item Continuity Tester: basically the same as the Signal Tracer
\item other useless stuff like thermometers etc...
\end{itemize}

As you can see, some are useful, others are just for fun. 

In the end I decided to discard the more useless modules because they really are just your basic ``My First Electronics Project'' kind of type\dots

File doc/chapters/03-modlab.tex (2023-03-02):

\chapter{ModLab}
Okay. As I already said, I didn't like the idea of a completely discrete system. During my second year of training (it was 3 years total) I was already done with all the FMAS modules and my instructors didn't really know what to do with me. So I proposed to develop my own system and thus the ``Arduino Workstation'' was born. I made a LOT of bad design choices back then which resulted in it being labeled a proof of concept. After that I wanted to make a better one with the though of ``overengineered and thought out as much as possible'' in mind. Obviously I don't plan \textit{everything} in advance for years and then build everything at once in the end, but I definitely put more thought into designing it and keeping it as modular as possible. Also I try to avoid bottlenecks and major design errors by thinking not only about the module itself, but the I always have the whole system in mind. 

And because of this, I decided to make it bigger. Not only in dimensions, but also in effort. The ModLab is my long-term project which will grow and improve over time with no fixed deadlines and goals. 

And that is how this project came to be.

\section{Lessons Learned from the Arduino Workstation}
\subsection{No virtual Grounds!}
A huge error was my thought, that +12V and -12V can be used as 24V. With some effort this surely is possible, but it includes a whole lot of difficulties and things to consider. 

So why bothering with that? Just use a fixed 24V rail on the backplane and boom, done.

\subsection{No hand-wired backplanes!}
I don't think I have to talk a lot about that\dots

The backplane of the Arduino Workstation was handwired with all 32 pins across several connectors. Suffice to say that I had some connection issues and it was a work I don't want to do again. Making a PCB is definitely easier and well designed way more modular. 

\subsection{Planning, Planning, Planning}
The old system was just made up as I went. Nothing was considered, I just wanted to play around. 

Now everything is planned through, difficult circuits are simulated first and every design will get a review. This will help avoiding major errors and hopefully ensures the success.

\section{What will be different?}
First of all, the planning. This part will be a more elaborate and thorough, which is why this project will take some time. 
Also I want to digitalize a lot more. In the Arduino Workstation, I still used potentiometers and buttons as interfaces and regulators, so a lot of hands on manipulation. This will be changed with digi-pots as well as DACs or PWM. 

Also I went away form Arduino. Actually I scrapped AVRs as a whole. Most things will use a more powerful STM32 controller to help with timing and speed. 

\vspace{1cm}

Nonetheless maybe some AVRs or PIC microcontrollers will find there way into the system. Not for things that need a lot of processing power, but nostalgia can go a long way and if they fit the function, why not.

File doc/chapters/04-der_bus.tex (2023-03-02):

\chapter{The Bus}
The Bus, or more specifically the backplane bus, is connecting all the modules together. It has all necessary supply voltages as well as all traces for the IO. For this reason, this part took a while.

\section{Voltages}
In order to keep things simple but functional, I decided to plate 4 voltages on the bus. What they are and there uses are outlined below.

\subsection{5V}
I don't think this needs a lot of explanation. Even tho most modules will run on 3V3, I might want to use other controllers or peripherals which run on 5V. For the most part, I will use Low-Dropout regulators to go to 3V3, even tho there will be quite a few of them. 

The Power Supply for the 5V can provide up to 15A, but I will put a 10A fuse in line. I think this will be more than enough for my uses.

\subsection{24V}
What would be a big project without decent power? Correct: BORING. So, especially for bigger power supplies, I included 24V. This will have a 10A fuse as well, I don't think I will need much more for most projects. And if I will have some really power-hungry ideas in the future, they should have an integrated power supply anyways. 

\subsection{Symmetric 30V (-15V..+15V)}
Ok, some of you might ask ``what the hell is that even used for???''

Hear me out. Even tho I am way more comfortable with digital circuits, there exists something called analog circuits. And especially for these I might need these voltages a lot. Examples would be amplifier circuits, waveform generators as well as different IO interfaces. 

Also I want to explore more power supply designs for negative voltages, this can come in handy. 

\section{Interfaces}
The modules need to talk to each other, therefore there have to be some interfaces on the bus. To keep it modular, I decided to include several different ones. These are explained in a bit more detail here.

\subsection{I2C}
I2C (or $I^2C$, IIC, \textit{Inter Integrated Circuit} etc..) is one of my favourite interfaces, because it is simple, easy to implement and I worked with it a lot. It supports up to 128 different nodes which is more than plenty and doesn't need a whole lot of chip-select signals. 

Actually I implemented two I2C interfaces, one at 100kHz standard frequency and one at 400kHz. 

Even tho it is a widely used interface for tons of peripherals, it will be mainly used as backup or for small periodical data packets. This will keep the main interface more free for other uses. 

\subsection{RS485}
RS485 is included, because I want to explore a protocoll called ModBUS. This might come in handy for other projects. Maybe this will be used more later, for now it is just there to have it. 

\subsection{SPI}
SPI (Serial Peripheral Interface) is a really common bus for a lot of things. It can go to quite high data rates, but also needs a chip-select for every node. For this reason, some dedicated IO lines are used as Chip Selects. If they are used as-is or if I decode them is still subject to debate. 

Also I actually have two SPI interfaces on the bus. one at 5V and one at 3V3. This will help integrating different controllers or peripherals to the system without a lot of level-shifting and thus introducing delays and synchronization issues. 

\subsection{CAN}
The CAN (Controller Area Network) interface will be the main workhorse interface of the system. It can support a lot of nodes and due to it being a differential interface should work pretty reliably. 

The downside is, that it needs a transceiver for every node but oh well. 

My current plan is to use the ISO-TP protocol for it. This way I can send more than a maximum of 8 bytes per data transfer, but this might slow down the interface a bit. Because of this, I will operate the interface at 1Mbit/s datarate. 

\section{I/Os}
Of course I will need some general IOs on the bus to control different things. Here a small summary. 

\subsection{Digital}
There are 6 general IOs on the backplane. These can be used as status signals (error, interrupt) or to do some fun things I still have to come up with. 

Also there are 6 dedicated Chip-Selects for the SPI interfaces. This way I can selectively address them. 

All IOs are 5V compatible.

At first I wanted to include some form of slot address encoding, but yeah... that idea was scrapped pretty early because I would need quite a few pins for that. 

\subsection{DACs}
Two DAC-channels from the Host Bus Controller (more on that later) are also on the bus. My plan is to use them with a speaker module to make really annoying system notification, like startup-melodies, error-notifications, acoustic signals for different events from submodules etc. 

Let's see what will come out of that.

\section{Layout}
Ok, now that we have talked about what signals will be on the backplane, let's see how it is layed out. 

I settled with the DIN 41612 64pin A-C connectors. These will fit well with the Rack-design as well as provide enough pins for everything. 

I decided to give the supply voltages 4 pins each to maximize possible current draw. Also I placed some GND-pins in the middle as well. This left only a few pins for all the signals. 

here is what I came up with.

\begin{table}[H]
\centering
\begin{tabular}{|r|c|c|l|}
                              	& 	a  	& 	c 	&   										\\ \hline \hline
\cellcolor[HTML]{FE0000}5V    	& 	1  	& 	1  	& 	\cellcolor[HTML]{FE0000}5V       		\\ \hline
\cellcolor[HTML]{FE0000}5V    	& 	2  	& 	2  	& 	\cellcolor[HTML]{FE0000}5V       		\\ \hline
\cellcolor[HTML]{0066ff}GND   	& 	3  	& 	3  	& 	\cellcolor[HTML]{0066ff}GND     		\\ \hline
\cellcolor[HTML]{0066ff}GND   	& 	4  	& 	4  	& 	\cellcolor[HTML]{0066ff}GND     		\\ \hline
\cellcolor[HTML]{FE0000}24V   	& 	5  	& 	5  	& 	\cellcolor[HTML]{FE0000}24V     		\\ \hline
\cellcolor[HTML]{FE0000}24V   	& 	6  	& 	6  	& 	\cellcolor[HTML]{FE0000}24V     		\\ \hline
\cellcolor[HTML]{0066ff}GND   	& 	7  	& 	7  	& 	\cellcolor[HTML]{0066ff}GND     		\\ \hline
\cellcolor[HTML]{0066ff}GND   	& 	8  	& 	8  	& 	\cellcolor[HTML]{0066ff}GND     		\\ \hline
\cellcolor[HTML]{9B9B9B}CAN+   	& 	9  	& 	9  	& 	\cellcolor[HTML]{9B9B9B}CAN-       		\\ \hline
\cellcolor[HTML]{F8FF00}IO0   	& 	10 	& 	10 	& 	\cellcolor[HTML]{F8FF00}IO1          	\\ \hline
\cellcolor[HTML]{9B9B9B}SDA\_FM  	& 	11 	& 	11 	& 	\cellcolor[HTML]{9B9B9B}SCL\_FM            	\\ \hline
\cellcolor[HTML]{F8FF00}IO2  	& 	12 	& 	12 	& 	\cellcolor[HTML]{F8FF00}IO2            	\\ \hline
\cellcolor[HTML]{9B9B9B}SDA    	& 	13 	& 	13 	& 	\cellcolor[HTML]{9B9B9B}SCL             	\\ \hline
\cellcolor[HTML]{F8FF00}IO4    	& 	14 	& 	14 	& 	\cellcolor[HTML]{F8FF00}IO5            	\\ \hline
\cellcolor[HTML]{9B9B9B}RS485+    	& 	15 	& 	15 	& 	\cellcolor[HTML]{9B9B9B}RS485-           	\\ \hline
\cellcolor[HTML]{0066ff}GND   	& 	16 	& 	16 	& 	\cellcolor[HTML]{0066ff}GND            	\\ \hline
\cellcolor[HTML]{0066ff}GND   	& 	17 	& 	17 	& 	\cellcolor[HTML]{0066ff}GND         	\\ \hline
\cellcolor[HTML]{996633}DAC0  	& 	18 	& 	18 	& 	\cellcolor[HTML]{996633}DAC1         	\\ \hline
\cellcolor[HTML]{32CB00}CS0    	& 	19 	& 	19 	& 	\cellcolor[HTML]{32CB00}CS1             	\\ \hline
\cellcolor[HTML]{FFC702}MOSI1    	& 	20 	& 	20 	& 	\cellcolor[HTML]{FFC702}MISO1             	\\ \hline
\cellcolor[HTML]{32CB00}CS2    	& 	21 	& 	21 	& 	\cellcolor[HTML]{32CB00}CS3             	\\ \hline
\cellcolor[HTML]{FFC702}SCK1    	& 	22 	& 	22 	& 	\cellcolor[HTML]{FFC702}SCK2           	\\ \hline
\cellcolor[HTML]{32CB00}CS4 	& 	23 	& 	23 	& 	\cellcolor[HTML]{32CB00}CS5      		\\ \hline
\cellcolor[HTML]{FFC702}MOSI2 	& 	24 	& 	24 	& 	\cellcolor[HTML]{FFC702}MISO2           	\\ \hline
\cellcolor[HTML]{FE0000}+15V  	& 	25 	& 	25 	& 	\cellcolor[HTML]{FE0000}+15V           	\\ \hline
\cellcolor[HTML]{FE0000}+15V  	& 	26 	& 	26 	& 	\cellcolor[HTML]{FE0000}+15V       		\\ \hline
\cellcolor[HTML]{0066ff}GND   	& 	27 	& 	27 	& 	\cellcolor[HTML]{0066ff}GND         	\\ \hline
\cellcolor[HTML]{0066ff}GND   	& 	28 	& 	28 	& 	\cellcolor[HTML]{0066ff}GND          	\\ \hline
\cellcolor[HTML]{FE0000}-15V  	& 	29 	& 	29 	& 	\cellcolor[HTML]{FE0000}-15V         	\\ \hline
\cellcolor[HTML]{FE0000}-15V  	& 	30 	& 	30 	& 	\cellcolor[HTML]{FE0000}-15V          	\\ \hline
\cellcolor[HTML]{0066ff}GND   	& 	31 	& 	31 	& 	\cellcolor[HTML]{0066ff}GND         	\\ \hline
\cellcolor[HTML]{0066ff}GND   	& 	32 	& 	32 	& 	\cellcolor[HTML]{0066ff}GND 			\\ \hline
\end{tabular}
\caption{Bus-Layout}
\label{tab:Bus-Layout}
\end{table}

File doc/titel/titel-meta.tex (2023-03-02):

\makeatletter                       
\def\printauthor{         
    {\large \@author}}              
\makeatother
\author{
    Synthron \\ 
    \vspace*{12pt}
    \texttt{admin@synthron.de}
    }

\renewcommand\epigraphflush{flushright}
\renewcommand\epigraphsize{\normalsize}
\setlength\epigraphwidth{0.7\textwidth}

\definecolor{Green}{gray}{0.55}

\newcommand\anglei{-45}
\newcommand\angleii{-45}
\newcommand\angleiii{-225}
\newcommand\angleiv{135}

\newcommand\titlepagedecoration{%
\begin{tikzpicture}[remember picture,overlay,shorten >= -10pt]

\coordinate (aux1) at ([yshift=-15pt]current page.north east);
\coordinate (aux2) at ([yshift=-410pt]current page.north east);
\coordinate (aux3) at ([xshift=-4.5cm]current page.north east);
\coordinate (aux4) at ([yshift=-150pt]current page.north east);

\begin{scope}[titlepagecolor!40,line width=12pt,rounded corners=12pt]
\draw
  (aux1) -- coordinate (a)
  ++(225:5) --
  ++(-45:5.1) coordinate (b);
\draw[shorten <= -10pt]
  (aux3) --
  (a) --
  (aux1);
\draw[opacity=0.6,titlepagecolor,shorten <= -10pt]
  (b) --
  ++(225:2.2) --
  ++(-45:2.2);
\end{scope}
\draw[titlepagecolor,line width=8pt,rounded corners=8pt,shorten <= -10pt]
  (aux4) --
  ++(225:0.8) --
  ++(-45:0.8);
\begin{scope}[titlepagecolor!70,line width=6pt,rounded corners=8pt]
\draw[shorten <= -10pt]
  (aux2) --
  ++(225:3) coordinate[pos=0.45] (c) --
  ++(-45:3.1);
\draw
  (aux2) --
  (c) --
  ++(135:2.5) --
  ++(45:2.5) --
  ++(-45:2.5) coordinate[pos=0.3] (d);   
\draw 
  (d) -- +(45:1);
\end{scope}
\end{tikzpicture}%
}
\newcommand\chapterdecoration{%
\begin{tikzpicture}[remember picture,overlay,shorten >= -10pt]
\coordinate (aux1) at ([yshift=-15pt]current page.north west);
\coordinate (aux2) at ([yshift=-310pt]current page.north west);
\coordinate (aux3) at ([xshift=4.5cm]current page.north west);
\coordinate (aux4) at ([yshift=-150pt]current page.north west);
\coordinate (aux5) at ([yshift=-535pt]current page.north west);
\coordinate (aux6) at ([yshift=-660pt]current page.north west);
\coordinate (aux7) at ([yshift=-630pt]current page.north west);
\coordinate (aux8) at ([xshift=-16.5cm]current page.south east);
\renewcommand\anglei{-135}
\renewcommand\angleii{135}
\renewcommand\angleiii{-45}
\renewcommand\angleiv{45}

\begin{scope}[titlepagecolor1!70,line width=6pt,rounded corners=8pt]
\draw[shorten <= -10pt]
  (aux2) --
  ++(\angleiii:3) coordinate[pos=0.4] (d) --
  ++(\anglei:3.1);

\draw
  (d) --
  ++(\angleiii:.1) --
 ++(\angleiii:1.7) --
  ++(\anglei:1.5) --
++(\angleiii:2.5) --
++(\anglei:2.5) --
++(\angleii:2) --
++(\angleiii:1.3) --
++(\anglei:1.3) 
 
coordinate[pos=0.3] (c); 
\begin{scope}[titlepagecolor1!40,line width=12pt,rounded corners=12pt]
\draw
  (aux7) -- coordinate (a)
  ++(\angleiii:5) --
  ++(\anglei:5.1) coordinate (b);
\draw[shorten <= -10pt]
  
  (b) -- 
++(\angleiv:2.5) --
++(\angleiii:5) 
  (aux8);
\draw[opacity=0.6,titlepagecolor1,shorten <= -10pt]
  (aux5) --
  ++(\angleiii:2.2) --
  ++(\anglei:2.2);
\draw[titlepagecolor1,line width=8pt,rounded corners=8pt,shorten <= -10pt]
  (aux6) --
  ++(\angleiii:0.8) --
  ++(\anglei:0.8);
\end{scope}
  
\end{scope}
\end{tikzpicture}%
}

% Old Code for reference
%
%
%
%\newcommand\titlepagedecoration{
%\begin{tikzpicture}[remember picture,overlay,shorten >= -10pt]
%
%\coordinate (aux1) at ([yshift=-15pt]current page.north east);
%\coordinate (aux2) at ([yshift=-410pt]current page.north east);
%\coordinate (aux3) at ([xshift=-4.5cm]current page.north east);
%\coordinate (aux4) at ([yshift=-150pt]current page.north east);
%
%\begin{scope}[titlepagecolor!40,line width=12pt,rounded corners=12pt]
%\draw
%  (aux1) -- coordinate (a)
%  ++(225:5) --
%  ++(-45:5.1) coordinate (b);
%\draw[shorten <= -10pt]
%  (aux3) --
%  (a) --
%  (aux1);
%\draw[opacity=0.6,titlepagecolor,shorten <= -10pt]
%  (b) --
%  ++(225:2.2) --
%  ++(-45:2.2);
%\end{scope}
%\draw[titlepagecolor,line width=8pt,rounded corners=8pt,shorten <= -10pt]
%  (aux4) --
%  ++(225:0.8) --
%  ++(-45:0.8);
%\begin{scope}[titlepagecolor!70,line width=6pt,rounded corners=8pt]
%\draw[shorten <= -10pt]
%  (aux2) --
%  ++(225:3) coordinate[pos=0.45] (c) --
%  ++(-45:3.1);
%\draw
%  (aux2) --
%  (c) --
%  ++(135:2.5) --
%  ++(45:2.5) --
%  ++(-45:2.5) coordinate[pos=0.3] (d);   
%\draw 
%  (d) -- +(45:1);
%\end{scope}
%\end{tikzpicture}
%}

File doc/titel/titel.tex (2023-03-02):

\begin{titlepage}

\vspace*{2cm}
\noindent
\titlefont \Titel\par
\epigraph{\Caption}
{\SignateAuthor\\ \Stand}
\vspace*{2cm}
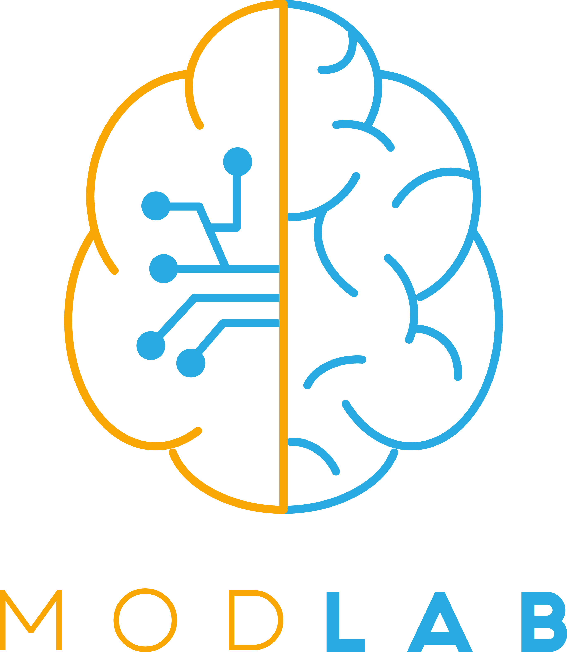
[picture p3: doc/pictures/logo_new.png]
\centering{}
\null\vfill
\vspace*{1cm}
\noindent
\hfill
\begin{minipage}{0.4\linewidth}
    \begin{flushright}
        \printauthor
    \end{flushright}
\end{minipage}
%
\begin{minipage}{0.02\linewidth}
    \rule{1pt}{80pt}
\end{minipage}
\titlepagedecoration
\chapterdecoration
\end{titlepage}

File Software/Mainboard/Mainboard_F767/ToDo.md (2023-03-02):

# ToDo

---

## Funktioniert

- USB
- I2C2
- RS485

---

## Funktioniert nicht

- CAN1
- I2C1

---

## Versuchen

- Cs an RTC kleiner
- ESP deaktivieren (RES auf Low)

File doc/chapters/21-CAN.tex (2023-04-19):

\section{CAN}
\subsection{Overview}
The CAN bus is the main communication bus for the ModLab. The HBC is sequentially talking to all the connected modules and sending commands to them if needed. This includes regular status updates as well as configurations. The CAN bus itself is divided into seperate layers, which will be discussed now. 

\begin{enumerate}
    \item \textbf{Physical Layer}\\
    The physical layer of the CAN interface consists of the CAN module on the STM32 controllers as well as a SN65VHD232 CAN Transceiver. CAN Rx and TX are sent on the same differential interface, making the bus half-duplex. 

    In order to get enough data around in a feasable time, the Interface will be clocked at 1MHz speed. 
    \item \textbf{Transport Layer}\\
    The transport layer descibes the way the data will be sent. Since standard CAN frames can only handle 8 bytes at once, I thought about implementing something here, to increase the data transfer. 
    
    After careful thinking tho, I decided agains a special transport protocol like ISO-TP, because the overhead creates more delays than I am comfortable with. I just have to be careful designing the command structure to not include commands with too many arguments.

    \item \textbf{Application Layer}\\
    Here is, where it gets interesting. After we can now send plenty of data, I need to define the actual transmission protocol of the payload for the modules. Since CAN is designed as such that every node reads the data at the same time, I have to implement a procedure to let the modules decide if the received message is of interest for them or not. 

    This can be achieved with two different methods. One is by encoding the module address in the ID section of the module, the other is sending the module in question as first byte in the payload. 

    I decided to implement the first option to save on transmission time. The ID field in the datagrams will be used both for encoding the module address, as well as indicaton for special cases like warnings and errors in my protocol. Also with this method I can selectively talk to each module without blocking processing time for checking if the message is really meant for them. 

    To clarify: if I talk about address, I mean the module address. I will refer to the ID as a whole (address + Message Type) as ID.
\end{enumerate}

\newpage

\subsection{General Structure}
The general structure of the protocol uses a ping---pong approach. The command value sent to the module will always be returned to the sender as well to clarify that this is the reply tho this command. Even tho I might sacrifice some bandwidth with this method, I think it will be worthwhile in future implementations. 

Because of this, the structure is always ``Command --- Value'' in both directions.

\subsection{ID Endcoding}
The ID structure will be used as specified in the following table. The ``xx'' in the ID will be placeholders for the module address. 

\begin{table}[H]
    \centering
    \begin{tabular}{|c|l|}
        \hline
        \textbf{ID}   &   \multicolumn{1}{|c|}{\textbf{Type}}\\ \hline \hline
        7xxh   &   Auto Message (informational) \\ \hline
        6xxh   &   Reply to Command (ACK)  \\  \hline
        5xxh   &   Standard Command    \\ \hline
        4xxh   &   Warnings / State Changes\\ \hline
        3xxh   &   Reply to Command (NACK) \\  \hline
        2xxh   &   Processing Error    \\ \hline
        1xxh   &   Critical Error      \\ \hline
        0xxh   &   reserved \\ \hline
    \end{tabular}
    \caption{CAN-Messages}
    \label{tab:CAN-Messages}
\end{table}

\subsection{Auto-Messages}
\textbf{\textcolor[HTML]{FF0000}{TBD}}
\begin{table}[H]
    \centering
    \begin{tabular}{|c|l|}
        \hline
        \textbf{Value Byte 1}   &   \multicolumn{1}{|c|}{\textbf{Description}}\\ \hline \hline
        10h    &   Conversion Done    \\ \hline
    \end{tabular}
    \caption{CAN Auto Messages}
    \label{tab:CAN-Auto}
\end{table}

\subsection{Base-Addresses}
\begin{table}[H]
    \centering
    \begin{tabular}{|c|l|}
        \hline
        \textbf{Base Address}   &   \multicolumn{1}{|c|}{\textbf{Module}}\\ \hline \hline
        10h    &   HBC    \\ \hline
        20h    &   Diode Tester \\ \hline
        30h    &   Symmetrical Linear Power supply \\ \hline
        34h    &   reserved \\ \hline
        38h    &   reserved \\ \hline
        3Ch    &   24V Switching Mode Power Supply \\\hline
        40h    &   DDS Waveform Generator \\ \hline
        50h    &   Electronic Load \\ \hline
    \end{tabular}
    \caption{CAN Addresses}
    \label{tab:CAN-ADD}
\end{table}

\subsection{Commands}
Overview:
\begin{table}[H]
    \centering
    \begin{tabular}{|c|l|}
        \hline
        \textbf{Value}   &   \multicolumn{1}{|c|}{\textbf{Command}}\\ \hline \hline \hline
        01h    &   Reset Module \\ \hline
        05h    &   Ping / Discovery \\ \hline
        \hline
        10h    &   Set 8bit Parameter    \\ \hline
        11h    &   Get 8bit Parameter     \\ \hline
        14h    &   Set 16bit Parameter   \\ \hline
        15h    &   Get 16bit Parameter    \\ \hline 
        18h    &   Set 32bit Parameter  \\ \hline
        19h    &   Get 32bit Parameter  \\ \hline
        \hline
        20h    &   Get Status Information \\ \hline 
        \hline
        40h    &   Enable Output       \\ \hline
        41h    &   Disable Output      \\ \hline 
        \hline
        60h    &   Set Operation Mode  \\ \hline
        61h    &   Get Operation Mode  \\ \hline 
    \end{tabular}
    \caption{CAN-Commands}
\label{tab:CAN-Commands}
\end{table}

%-------------------------------
\subsubsection{01h --- Reset Module}
Force Reset of Module. 

Command:
\begin{table}[H]
    \centering
    \begin{tabular}{|c|c|l|}
        \hline
        \textbf{Value}   &   \textbf{Length} & \multicolumn{1}{|c|}{\textbf{Description}}\\ \hline \hline
        01h   &  1 Byte & Reset Module Command \\ \hline
    \end{tabular}
\label{tab:CAN-01-C}
\end{table}
Reply:
\begin{table}[H]
    \centering
    \begin{tabular}{|c|c|l|}
        \hline
        \textbf{Value}   &   \textbf{Length} & \multicolumn{1}{|c|}{\textbf{Description}}\\ \hline \hline
        01h   &  1 Byte & Reset Module Command \\ \hline
        Status & 1 Byte & \makecell[l]{Error-Status in case of NACK \\ Otherwise set to 0\\see Error Descriptions}\\ \hline
    \end{tabular}
\label{tab:CAN-01-R}
\end{table}

%-------------------------------
\subsubsection{05h --- Ping / Discovery}
Ping Module to just get an answer. 

Command:
\begin{table}[H]
    \centering
    \begin{tabular}{|c|c|l|}
        \hline
        \textbf{Value}   &   \textbf{Length} & \multicolumn{1}{|c|}{\textbf{Description}}\\ \hline \hline
        05h   &  1 Byte & Ping Command \\ \hline
    \end{tabular}
\label{tab:CAN-05-C}
\end{table}
Reply:
\begin{table}[H]
    \centering
    \begin{tabular}{|c|c|l|}
        \hline
        \textbf{Value}   &   \textbf{Length} & \multicolumn{1}{|c|}{\textbf{Description}}\\ \hline \hline
        05h   &  1 Byte & Ping Command \\ \hline
        Status & 1 Byte & \makecell[l]{Error-Status in case of NACK \\ Otherwise set to 0\\see Error Descriptions}\\ \hline
    \end{tabular}
\label{tab:CAN-05-R}
\end{table}

%-------------------------------
\subsubsection{10h --- Set 8bit Parameter}
Write 8bit value to module parameter. 

Command:
\begin{table}[H]
    \centering
    \begin{tabular}{|c|c|l|}
        \hline
        \textbf{Value}   &   \textbf{Length} & \multicolumn{1}{|c|}{\textbf{Description}}\\ \hline \hline
        10h   &  1 Byte & Set 8bit Parameter Command \\ \hline
        Index & 1 Byte  & Parameter Index, see Module Description \\ \hline
        Value & 1 Byte & Value to be written\\ \hline
    \end{tabular}
\label{tab:CAN-10-C}
\end{table}
Reply:
\begin{table}[H]
    \centering
    \begin{tabular}{|c|c|l|}
        \hline
        \textbf{Value}   &   \textbf{Length} & \multicolumn{1}{|c|}{\textbf{Description}}\\ \hline \hline
        10h   &  1 Byte & Set 8bit Parameter Command \\ \hline
        Status & 1 Byte & \makecell[l]{Error-Status in case of NACK \\ Otherwise set to 0\\see Error Descriptions}\\ \hline
    \end{tabular}
\label{tab:CAN-10-R}
\end{table}

%-------------------------------
\subsubsection{11h --- Get 8bit Parameter}
Read 8bit value from module parameter.

Command:
\begin{table}[H]
    \centering
    \begin{tabular}{|c|c|l|}
        \hline
        \textbf{Value}   &   \textbf{Length} & \multicolumn{1}{|c|}{\textbf{Description}}\\ \hline \hline
        11h   &  1 Byte & Get 8bit Parameter Command \\ \hline
        Index & 1 Byte  & Parameter Index, see Module Description \\ \hline
    \end{tabular}
\label{tab:CAN-11-C}
\end{table}
Reply:
\begin{table}[H]
    \centering
    \begin{tabular}{|c|c|l|}
        \hline
        \textbf{Value}   &   \textbf{Length} & \multicolumn{1}{|c|}{\textbf{Description}}\\ \hline \hline
        11h   &  1 Byte & Get 8bit Parameter Command \\ \hline
        Status & 1 Byte & \makecell[l]{Error-Status in case of NACK \\ Otherwise set to 0\\see Error Descriptions}\\ \hline
        Value & 1 Byte & Value to be read; 0 if NACK \\ \hline
    \end{tabular}
\label{tab:CAN-11-R}
\end{table}

%-------------------------------
\subsubsection{14h --- Set 16bit Parameter}
Write 16bit value to module parameter.

Command:
\begin{table}[H]
    \centering
    \begin{tabular}{|c|c|l|}
        \hline
        \textbf{Value}   &   \textbf{Length} & \multicolumn{1}{|c|}{\textbf{Description}}\\ \hline \hline
        14h   &  1 Byte & Set 16bit Parameter Command \\ \hline
        Index & 1 Byte  & Parameter Index, see Module Description \\ \hline
        Value & 2 Byte & Value to be written\\ \hline
    \end{tabular}
\label{tab:CAN-14-C}
\end{table}
Reply:
\begin{table}[H]
    \centering
    \begin{tabular}{|c|c|l|}
        \hline
        \textbf{Value}   &   \textbf{Length} & \multicolumn{1}{|c|}{\textbf{Description}}\\ \hline \hline
        14h   &  1 Byte & Set 16bit Parameter Command \\ \hline
        Status & 1 Byte & \makecell[l]{Error-Status in case of NACK \\ Otherwise set to 0\\see Error Descriptions}\\ \hline
    \end{tabular}
\label{tab:CAN-14-R}
\end{table}
\subsubsection{15h --- Get 16bit Parameter}
Read 16bit value from module parameter.

Command:
\begin{table}[H]
    \centering
    \begin{tabular}{|c|c|l|}
        \hline
        \textbf{Value}   &   \textbf{Length} & \multicolumn{1}{|c|}{\textbf{Description}}\\ \hline \hline
        15h   &  1 Byte & Get 16bit Parameter Command \\ \hline
        Index & 1 Byte  & Parameter Index, see Module Description \\ \hline
    \end{tabular}
\label{tab:CAN-15-C}
\end{table}
Reply:
\begin{table}[H]
    \centering
    \begin{tabular}{|c|c|l|}
        \hline
        \textbf{Value}   &   \textbf{Length} & \multicolumn{1}{|c|}{\textbf{Description}}\\ \hline \hline
        15h   &  1 Byte & Get 16bit Parameter Command \\ \hline
        Status & 1 Byte & \makecell[l]{Error-Status in case of NACK \\ Otherwise set to 0\\see Error Descriptions}\\ \hline
        Value & 2 Byte & Value to be read; 0 if NACK \\ \hline
    \end{tabular}
\label{tab:CAN-15-R}
\end{table}

%-------------------------------
\subsubsection{14h --- Set 32bit Parameter}
Write 32bit value to module parameter.

Command:
\begin{table}[H]
    \centering
    \begin{tabular}{|c|c|l|}
        \hline
        \textbf{Value}   &   \textbf{Length} & \multicolumn{1}{|c|}{\textbf{Description}}\\ \hline \hline
        18h   &  1 Byte & Set 32bit Parameter Command \\ \hline
        Index & 1 Byte  & Parameter Index, see Module Description \\ \hline
        Value & 4 Byte & Value to be written\\ \hline
    \end{tabular}
\label{tab:CAN-18-C}
\end{table}
Reply:
\begin{table}[H]
    \centering
    \begin{tabular}{|c|c|l|}
        \hline
        \textbf{Value}   &   \textbf{Length} & \multicolumn{1}{|c|}{\textbf{Description}}\\ \hline \hline
        18h   &  1 Byte & Set 32bit Parameter Command \\ \hline
        Status & 1 Byte & \makecell[l]{Error-Status in case of NACK \\ Otherwise set to 0\\see Error Descriptions}\\ \hline
    \end{tabular}
\label{tab:CAN-18-R}
\end{table}
\subsubsection{19h --- Get 32bit Parameter}
Read 32bit value from module parameter.

Command:
\begin{table}[H]
    \centering
    \begin{tabular}{|c|c|l|}
        \hline
        \textbf{Value}   &   \textbf{Length} & \multicolumn{1}{|c|}{\textbf{Description}}\\ \hline \hline
        18h   &  1 Byte & Get 32bit Parameter Command \\ \hline
        Index & 1 Byte  & Parameter Index, see Module Description \\ \hline
    \end{tabular}
\label{tab:CAN-19-C}
\end{table}
Reply:
\begin{table}[H]
    \centering
    \begin{tabular}{|c|c|l|}
        \hline
        \textbf{Value}   &   \textbf{Length} & \multicolumn{1}{|c|}{\textbf{Description}}\\ \hline \hline
        19h   &  1 Byte & Get 32bit Parameter Command \\ \hline
        Status & 1 Byte & \makecell[l]{Error-Status in case of NACK \\ Otherwise set to 0\\see Error Descriptions}\\ \hline
        Value & 4 Byte & Value to be read; 0 if NACK \\ \hline
    \end{tabular}
\label{tab:CAN-19-R}
\end{table}

%-------------------------------
\subsubsection{20h --- Get Status Information}
Get status information from module.

Command:
\begin{table}[H]
    \centering
    \begin{tabular}{|c|c|l|}
        \hline
        \textbf{Value}   &   \textbf{Length} & \multicolumn{1}{|c|}{\textbf{Description}}\\ \hline \hline
        20h   &  1 Byte & Get Status Information Command \\ \hline
    \end{tabular}
\label{tab:CAN-20-C}
\end{table}
Reply:
\begin{table}[H]
    \centering
    \begin{tabular}{|c|c|l|}
        \hline
        \textbf{Value}   &   \textbf{Length} & \multicolumn{1}{|c|}{\textbf{Description}}\\ \hline \hline
        20h   &  1 Byte & Get 16bit Parameter Command \\ \hline
        Status & 1 Byte & \makecell[l]{Error-Status\\see Error Descriptions}\\ \hline
        Channel Info & 1 Byte & \makecell[l]{bit 0..3: PWM-Channel 0..3\\bit 4..5: ADC-Channel 0..3\\bits are 0 if channel not implemented} \\ \hline
    \end{tabular}
\label{tab:CAN-20-R}
\end{table}
%-------------------------------
\subsubsection{40h --- Enable Output}
Enable the Module Output.

Command:
\begin{table}[H]
    \centering
    \begin{tabular}{|c|c|l|}
        \hline
        \textbf{Value}   &   \textbf{Length} & \multicolumn{1}{|c|}{\textbf{Description}}\\ \hline \hline
        40h   &  1 Byte & Enable Output Command \\ \hline
    \end{tabular}
\label{tab:CAN-40-C}
\end{table}
Reply:
\begin{table}[H]
    \centering
    \begin{tabular}{|c|c|l|}
        \hline
        \textbf{Value}   &   \textbf{Length} & \multicolumn{1}{|c|}{\textbf{Description}}\\ \hline \hline
        40h   &  1 Byte & Enable Output Command \\ \hline
        Status & 1 Byte & \makecell[l]{Error-Status\\see Error Descriptions}\\ \hline
    \end{tabular}
\label{tab:CAN-40-R}
\end{table}
%-------------------------------
\subsubsection{41h --- Disable Output}
Disable the Module Output.

Command:
\begin{table}[H]
    \centering
    \begin{tabular}{|c|c|l|}
        \hline
        \textbf{Value}   &   \textbf{Length} & \multicolumn{1}{|c|}{\textbf{Description}}\\ \hline \hline
        41h   &  1 Byte & Disable Output Command \\ \hline
    \end{tabular}
\label{tab:CAN-41-C}
\end{table}
Reply:
\begin{table}[H]
    \centering
    \begin{tabular}{|c|c|l|}
        \hline
        \textbf{Value}   &   \textbf{Length} & \multicolumn{1}{|c|}{\textbf{Description}}\\ \hline \hline
        41h   &  1 Byte & Disable Output Command \\ \hline
        Status & 1 Byte & \makecell[l]{Error-Status\\see Error Descriptions}\\ \hline
    \end{tabular}
\label{tab:CAN-41-R}
\end{table}
%-------------------------------
\subsubsection{60h --- Set Operation Mode}
Set Module into Operation Mode x. 

Command:
\begin{table}[H]
    \centering
    \begin{tabular}{|c|c|l|}
        \hline
        \textbf{Value}   &   \textbf{Length} & \multicolumn{1}{|c|}{\textbf{Description}}\\ \hline \hline
        60h   &  1 Byte & Set Operation Mode Command \\ \hline
        Mode & 1 Byte & Operation Mode, see Module Description\\ \hline
    \end{tabular}
\label{tab:CAN-60-C}
\end{table}
Reply:
\begin{table}[H]
    \centering
    \begin{tabular}{|c|c|l|}
        \hline
        \textbf{Value}   &   \textbf{Length} & \multicolumn{1}{|c|}{\textbf{Description}}\\ \hline \hline
        60h   &  1 Byte & Set Operation Mode Command \\ \hline
        Status & 1 Byte & \makecell[l]{Error-Status in case of NACK \\ Otherwise set to 0\\see Error Descriptions}\\ \hline
    \end{tabular}
\label{tab:CAN-60-R}
\end{table}

\subsubsection{61h --- Get Operation Mode}
Get Module Operation Mode. 

Command:
\begin{table}[H]
    \centering
    \begin{tabular}{|c|c|l|}
        \hline
        \textbf{Value}   &   \textbf{Length} & \multicolumn{1}{|c|}{\textbf{Description}}\\ \hline \hline
        61h   &  1 Byte & Get Operation Mode Command \\ \hline
    \end{tabular}
\label{tab:CAN-61-C}
\end{table}
Reply:
\begin{table}[H]
    \centering
    \begin{tabular}{|c|c|l|}
        \hline
        \textbf{Value}   &   \textbf{Length} & \multicolumn{1}{|c|}{\textbf{Description}}\\ \hline \hline
        61h   &  1 Byte & Get Operation Mode Command \\ \hline
        Mode & 1 Byte & Operation Mode, see Module Description\\ \hline
        Status & 1 Byte & \makecell[l]{Error-Status in case of NACK \\ Otherwise set to 0\\see Error Descriptions}\\ \hline
    \end{tabular}
\label{tab:CAN-61-R}
\end{table}

%-------------------------------

\subsection{Error Descriptions}
\subsubsection{Status Byte}
Description of the Status Byte in Reply Messages. If a Bit is set to 0, it is inactive. A 1 indicates an active error.

The lower Nibble indicates protocol errors, a mismatch condition can mean both ``not available'' and ``wrong length''. 

The upper Nibble indicates internal errors of the module. 

\begin{table}[H]
    \centering
    \begin{tabular}{|c|l|}
        \hline
        \textbf{Bit}   & \multicolumn{1}{|c|}{\textbf{Description}}\\ \hline \hline
        0   &    Index Mismatch   \\ \hline
        1   &    Data Mismatch   \\ \hline
        2   &    Channel Mismatch   \\ \hline
        3   &    Operation Mode Mismatch  \\ \hline
        4   &    Processing Error   \\ \hline
        5   &    I/O Error   \\ \hline
        6   &    Unknown Command   \\ \hline
        7   &    reserved   \\ \hline
    \end{tabular}
\label{tab:CAN-status}
\end{table}

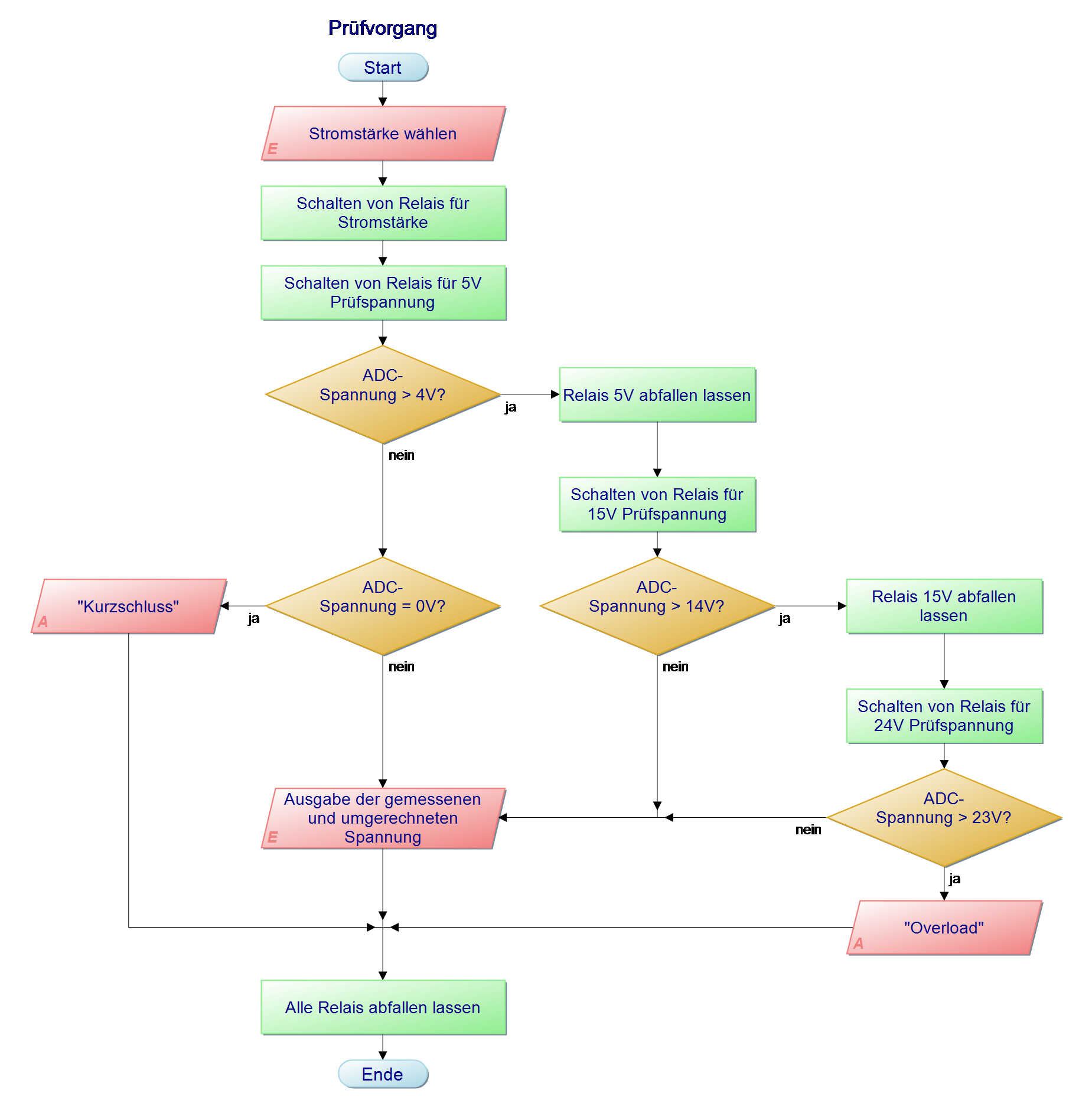
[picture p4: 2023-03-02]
doc/pictures/Pruefvorgang.png

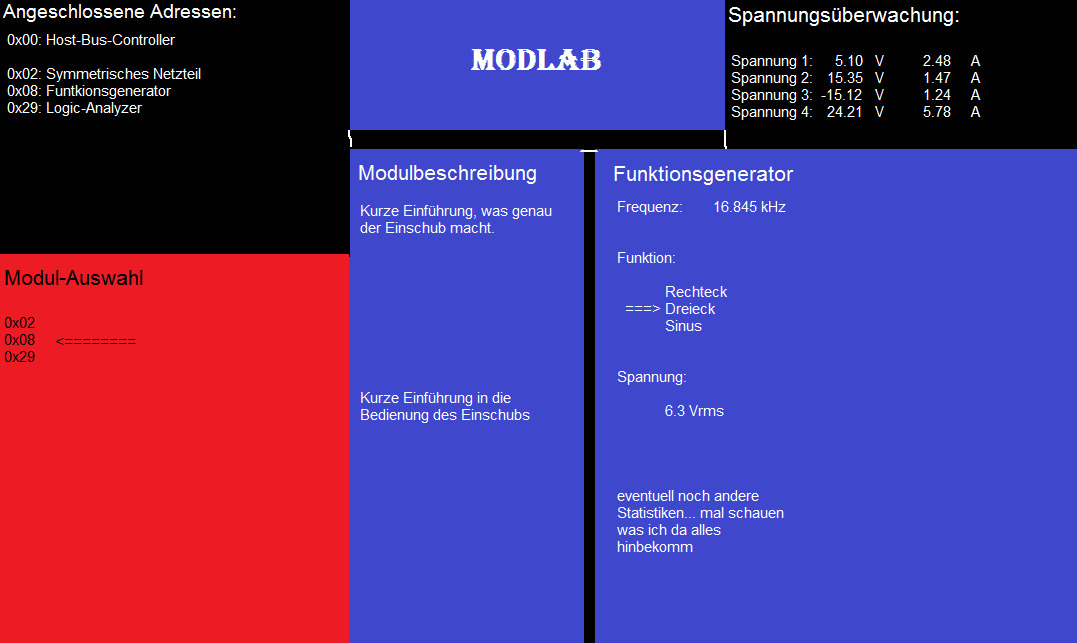
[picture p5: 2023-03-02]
doc/pictures/gui.jpg

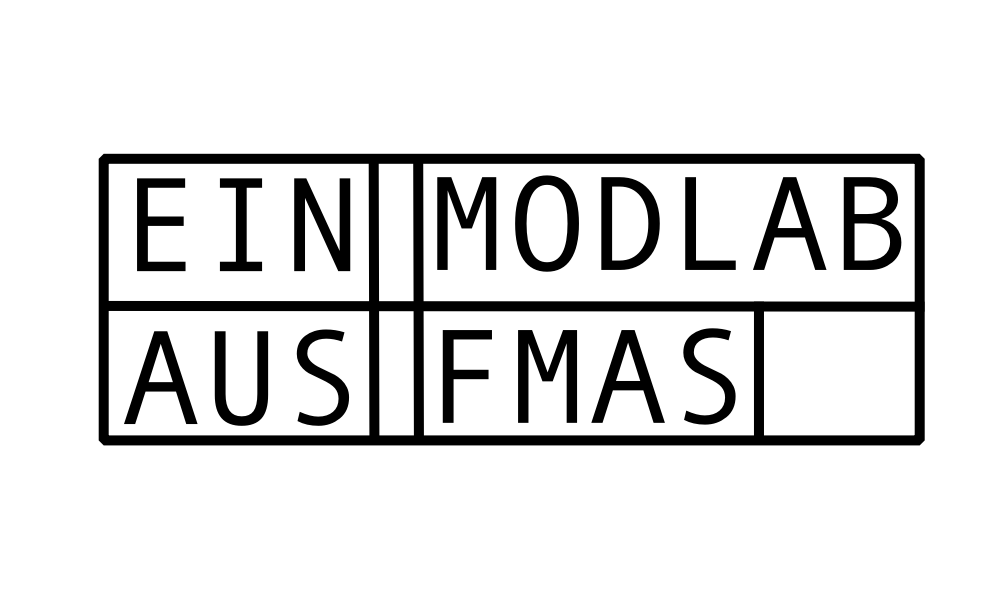
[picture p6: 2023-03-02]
Engravings/MODLAB_FRONT_ENGRAVE.bmp

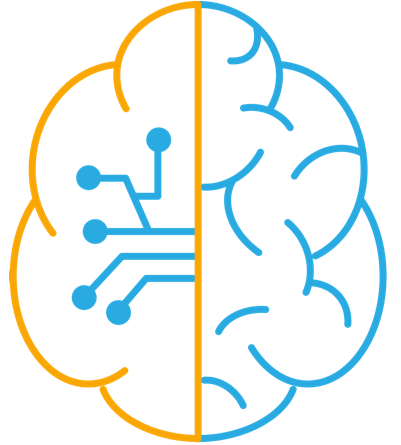
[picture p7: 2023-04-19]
Software/Mainboard/Nexion_TFT/MODLAB_TRANSPARENT.png

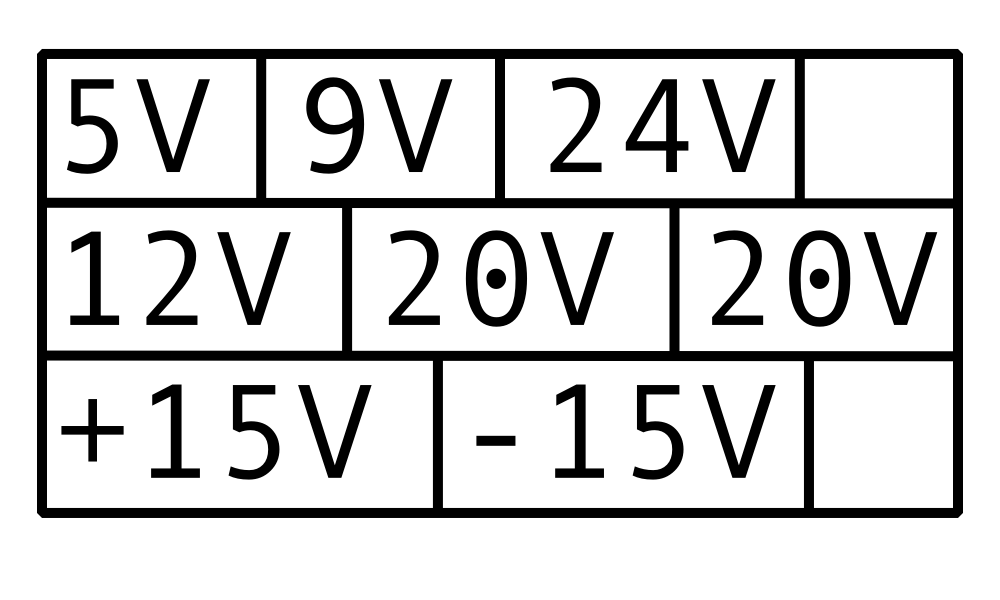
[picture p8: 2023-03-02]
Engravings/MODLAB_Fuse_ENGRAVE.bmp

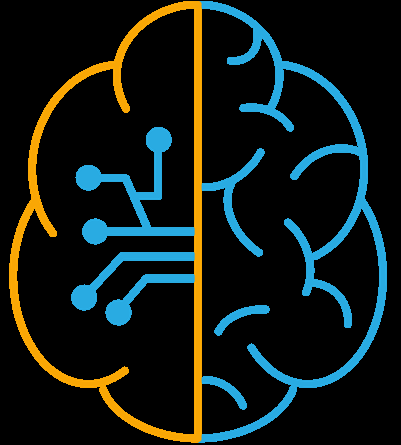
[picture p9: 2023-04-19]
Software/Mainboard/Nexion_TFT/MODLAB_TRANSPARENT.bmp

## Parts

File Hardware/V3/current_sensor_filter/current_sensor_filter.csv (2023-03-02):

Source: | /media/marco/Daten/Repositories/modlab/Hardware/V3/current_sensor_filter/current_sensor_filter.kicad_sch
Date: | Mi 30 Nov 2022 21:52:55 CET
Tool: | Eeschema 6.0.9-8da3e8f707~116~ubuntu20.04.1
Generator: | /usr/share/kicad/plugins/bom_csv_grouped_by_value_with_fp.py
Component Count: | 91
Ref | Qnty | Value | Cmp name | Footprint | Description | Vendor
C1, C2, C3, C8, C13, C14, C15, C20, C21, C23, C25, C30, C35, | 13 | 100n | C | Capacitor_SMD:C_0805_2012Metric | Unpolarized capacitor
C4, C5, C6, C7, | 4 | 2200µ | C_Polarized | Capacitor_THT:CP_Radial_D12.5mm_P5.00mm | Polarized capacitor
C9, C10, C11, C12, C16, C17, C18, C19, C24, C27, C31, C33, | 12 | 1n | C | Capacitor_SMD:C_0805_2012Metric | Unpolarized capacitor
C22, C32, C34, C36, C37, | 5 | 1µ | C | Capacitor_SMD:C_0805_2012Metric | Unpolarized capacitor
C26, | 1 | 4µ7 | C | Capacitor_SMD:C_0805_2012Metric | Unpolarized capacitor
C28, C29, | 2 | 20p | C | Capacitor_SMD:C_0805_2012Metric | Unpolarized capacitor
FB1, | 1 | SMB-001 | FerriteBead_Small | eigene:SMB-001 | Ferrite bead, small symbol
J1, | 1 | 5V IN | Screw_Terminal_01x02 | TerminalBlock:TerminalBlock_bornier-2_P5.08mm | Generic screw terminal, single row, 01x02, script generated (kicad-library-utils/schlib/autogen/connector/)
J2, | 1 | 24V IN | Screw_Terminal_01x02 | TerminalBlock:TerminalBlock_bornier-2_P5.08mm | Generic screw terminal, single row, 01x02, script generated (kicad-library-utils/schlib/autogen/connector/)
J3, | 1 | 15V IN | Screw_Terminal_01x02 | TerminalBlock:TerminalBlock_bornier-2_P5.08mm | Generic screw terminal, single row, 01x02, script generated (kicad-library-utils/schlib/autogen/connector/)
J4, | 1 | -15V IN | Screw_Terminal_01x02 | TerminalBlock:TerminalBlock_bornier-2_P5.08mm | Generic screw terminal, single row, 01x02, script generated (kicad-library-utils/schlib/autogen/connector/)
J5, | 1 | 5V OUT | Screw_Terminal_01x02 | TerminalBlock:TerminalBlock_bornier-2_P5.08mm | Generic screw terminal, single row, 01x02, script generated (kicad-library-utils/schlib/autogen/connector/)
J6, | 1 | 24V OUT | Screw_Terminal_01x02 | TerminalBlock:TerminalBlock_bornier-2_P5.08mm | Generic screw terminal, single row, 01x02, script generated (kicad-library-utils/schlib/autogen/connector/)
J7, | 1 | 15V OUT | Screw_Terminal_01x02 | TerminalBlock:TerminalBlock_bornier-2_P5.08mm | Generic screw terminal, single row, 01x02, script generated (kicad-library-utils/schlib/autogen/connector/)
J8, | 1 | -15V OUT | Screw_Terminal_01x02 | TerminalBlock:TerminalBlock_bornier-2_P5.08mm | Generic screw terminal, single row, 01x02, script generated (kicad-library-utils/schlib/autogen/connector/)
J9, | 1 | SWD | Conn_01x04 | Connector_JST:JST_XH_B4B-XH-A_1x04_P2.50mm_Vertical | Generic connector, single row, 01x04, script generated (kicad-library-utils/schlib/autogen/connector/)
J10, | 1 | I2C | Conn_01x04 | Connector_JST:JST_XH_B4B-XH-A_1x04_P2.50mm_Vertical | Generic connector, single row, 01x04, script generated (kicad-library-utils/schlib/autogen/connector/)
L1, L2, L3, L4, | 4 | 150µH | L | Inductor_THT:L_Toroid_Vertical_L25.4mm_W14.7mm_P12.20mm_Vishay_TJ5_BigPads | Inductor
Q1, Q2, | 2 | BSS138 | BSS138 | Package_TO_SOT_SMD:SOT-23 | 50V Vds, 0.22A Id, N-Channel MOSFET, SOT-23
R1, R2, R3, R4, R20, R24, | 6 | 100 | R | Resistor_SMD:R_0805_2012Metric | Resistor
R5, R6, R7, R8, R21, | 5 | 3k9 | R | Resistor_SMD:R_0805_2012Metric | Resistor
R9, R10, R11, R12, R22, R26, R27, R28, R29, | 9 | 12k | R | Resistor_SMD:R_0805_2012Metric | Resistor
R13, R14, R18, R25, | 4 | 10k | R | Resistor_SMD:R_0805_2012Metric | Resistor
R15, | 1 | 20k | R | Resistor_SMD:R_0805_2012Metric | Resistor
R16, | 1 | 100k | R | Resistor_SMD:R_0805_2012Metric | Resistor
R17, | 1 | 68k | R | Resistor_SMD:R_0805_2012Metric | Resistor
R19, | 1 | 18k | R | Resistor_SMD:R_0805_2012Metric | Resistor
R23, | 1 | 1M | R | Resistor_SMD:R_0805_2012Metric | Resistor
U1, U2, U3, U4, | 4 | ACS723xLCTR-05AB | ACS723xLCTR-05AB | Package_SO:SOIC-8_3.9x4.9mm_P1.27mm | ±5A Bidirectional Hall-Effect Current Sensor, +5.0V supply, 400mV/A, SOIC-8
U5, | 1 | LM2904 | LM2904 | Package_SO:SOIC-8_3.9x4.9mm_P1.27mm | Dual Operational Amplifiers, DIP-8/SOIC-8/TSSOP-8/VSSOP-8
U6, | 1 | AP1117-33 | AP1117-33 | Package_TO_SOT_SMD:SOT-223-3_TabPin2 | 1A Low Dropout regulator, positive, 3.3V fixed output, SOT-223
U7, | 1 | STM32F103C8Tx | STM32F103C8Tx | Package_QFP:LQFP-48_7x7mm_P0.5mm | ARM Cortex-M3 MCU, 64KB flash, 20KB RAM, 72MHz, 2-3.6V, 37 GPIO, LQFP-48
Y1, | 1 | 8MHz | Crystal_GND24 | Crystal:Crystal_SMD_5032-4Pin_5.0x3.2mm | Four pin crystal, GND on pins 2 and 4

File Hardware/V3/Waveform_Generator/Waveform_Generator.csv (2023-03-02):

Source: | /media/marco/Daten/Repositories/modlab/Hardware/V3/Waveform_Generator/Waveform_Generator.kicad_sch
Date: | Mi 30 Nov 2022 22:10:12 CET
Tool: | Eeschema 6.0.9-8da3e8f707~116~ubuntu20.04.1
Generator: | /usr/share/kicad/plugins/bom_csv_grouped_by_value_with_fp.py
Component Count: | 104
Ref | Qnty | Value | Cmp name | Footprint | Description | Vendor
C201, C205, C210, C212, C217, C218, C219, C223, C224, C306, C307, C310, C311, C403, C404, C405, C406, C407, C408, C409, | 20 | 100n | C | Capacitor_SMD:C_0805_2012Metric | Unpolarized capacitor
C202, C203, | 2 | 5n6 | C | Capacitor_SMD:C_0805_2012Metric | Unpolarized capacitor
C204, C410, | 2 | 4µ7 | C | Capacitor_SMD:C_0805_2012Metric | Unpolarized capacitor
C206, C207, C208, C209, | 4 | 470n | C | Capacitor_SMD:C_0805_2012Metric | Unpolarized capacitor
C211, | 1 | 10µ Tantal | C_Polarized | Capacitor_Tantalum_SMD:CP_EIA-3216-12_Kemet-S | Polarized capacitor
C213, | 1 | 22p | C | Capacitor_SMD:C_0805_2012Metric | Unpolarized capacitor
C214, C215, C221, C222, C305, C308, C309, C312, | 8 | 1µ | C | Capacitor_SMD:C_0805_2012Metric | Unpolarized capacitor
C216, | 1 | 10n | C | Capacitor_SMD:C_0805_2012Metric | Unpolarized capacitor
C220, | 1 | 22µ Tantal | C_Polarized | Capacitor_Tantalum_SMD:CP_EIA-3216-12_Kemet-S | Polarized capacitor
C225, C226, | 2 | 2µ2 Tantal | C_Polarized | Capacitor_Tantalum_SMD:CP_EIA-3216-12_Kemet-S | Polarized capacitor
C301, C302, C303, C304, | 4 | 100µ | C_Polarized | Capacitor_THT:CP_Radial_D8.0mm_P5.00mm | Polarized capacitor
C401, C402, | 2 | 20p | C | Capacitor_SMD:C_0805_2012Metric | Unpolarized capacitor
D201, | 1 | LL4148 | LL4148 | Diode_SMD:D_MiniMELF | 100V 0.15A standard switching diode, MiniMELF
D301, | 1 | SMAJ5,0A | D_TVS | Diode_SMD:D_SMA | Bidirectional transient-voltage-suppression diode
D302, | 1 | P6SMB26 | D_TVS | Diode_SMD:D_SMA | Bidirectional transient-voltage-suppression diode
D303, D304, | 2 | P6SMB16 | D_TVS | Diode_SMD:D_SMA | Bidirectional transient-voltage-suppression diode
D401, | 1 | CDSOT23-T24-Q | D_TVS_Dual_AAC | Package_TO_SOT_SMD:SOT-23 | Bidirectional dual transient-voltage-suppression diode, center on pin 3
J101, | 1 | DIN41612_02x32_AC | DIN41612_02x32_AC | eigene:VG64_Euro | DIN41612 connector, double row (AC), 02x32, script generated (kicad-library-utils/schlib/autogen/connector/)
J201, | 1 | Wave_Out | Conn_01x02 | Connector_PinSocket_2.54mm:PinSocket_1x02_P2.54mm_Vertical | Generic connector, single row, 01x02, script generated (kicad-library-utils/schlib/autogen/connector/)
J401, | 1 | SWD | Conn_01x04 | Connector_JST:JST_XH_B4B-XH-A_1x04_P2.50mm_Vertical | Generic connector, single row, 01x04, script generated (kicad-library-utils/schlib/autogen/connector/)
J402, | 1 | Address | Conn_02x02_Odd_Even | Connector_PinHeader_2.54mm:PinHeader_2x02_P2.54mm_Vertical | Generic connector, double row, 02x02, odd/even pin numbering scheme (row 1 odd numbers, row 2 even numbers), script generated (kicad-library-utils/schlib/autogen/connector/)
K201, | 1 | G6K-2 | G6K-2 | Relay_SMD:Relay_DPDT_Omron_G6K-2F | Miniature 2-pole relay, Single-side Stable
L401, | 1 | SRF3225TAC-101Y | L_Coupled_1243 | eigene:SRF3225TAC | Coupled inductor
Q201, Q401, Q402, | 3 | BSS138 | BSS138 | Package_TO_SOT_SMD:SOT-23 | 50V Vds, 0.22A Id, N-Channel MOSFET, SOT-23
R201, R203, | 2 | 1k3 | R | Resistor_SMD:R_0805_2012Metric | Resistor
R202, R204, | 2 | 3k9 | R | Resistor_SMD:R_0805_2012Metric | Resistor
R205, | 1 | 10 | R | Resistor_SMD:R_0805_2012Metric | Resistor
R206, R207, R208, R209, | 4 | 22k | R | Resistor_SMD:R_0805_2012Metric | Resistor
R210, R211, | 2 | 2k | R | Resistor_SMD:R_0805_2012Metric | Resistor
R212, R213, R222, | 3 | 240 | R | Resistor_SMD:R_0805_2012Metric | Resistor
R214, | 1 | 9k1 | R | Resistor_SMD:R_0805_2012Metric | Resistor
R215, | 1 | 910 | R | Resistor_SMD:R_0805_2012Metric | Resistor
R216, R217, R219, R220, | 4 | 1k | R | Resistor_SMD:R_0805_2012Metric | Resistor
R218, | 1 | 200 | R | Resistor_SMD:R_0805_2012Metric | Resistor
R221, | 1 | 100k | R | Resistor_SMD:R_0805_2012Metric | Resistor
R401, | 1 | 1M | R | Resistor_SMD:R_0805_2012Metric | Resistor
R402, R408, R409, | 3 | 10k | R | Resistor_SMD:R_0805_2012Metric | Resistor
R403, | 1 | 100 | R | Resistor_SMD:R_0805_2012Metric | Resistor
R404, R405, R406, R407, | 4 | 4k7 | R | Resistor_SMD:R_0805_2012Metric | Resistor
U201, | 1 | AD9833xRM | AD9833xRM | Package_SO:MSOP-10_3x3mm_P0.5mm | 10 bit 25 MHz Programmable Waveform Generator, 2.3V to 5.5V, 12.65mW, MSOP-10
U202, | 1 | OPA2196xD | OPA2196xD | Package_SO:SOIC-8_3.9x4.9mm_P1.27mm | Dual, Low-Power, Low Offset Voltage, Rail-to-Rail Operational Amplifier, SOIC-8
U203, | 1 | LM7171xIM | LM7171xIM | Package_SO:SOIC-8_3.9x4.9mm_P1.27mm | Single Very High Speed High Output Current Voltage Feedback Amplifier, SOIC-8
U204, | 1 | VCA822 | VCA822 | Package_SO:VSSOP-10_3x3mm_P0.5mm
U301, | 1 | AP1117-33 | AP1117-33 | Package_TO_SOT_SMD:SOT-223-3_TabPin2 | 1A Low Dropout regulator, positive, 3.3V fixed output, SOT-223
U302, | 1 | L7905 | L7905 | Package_TO_SOT_SMD:TO-252-2 | Negative 1.5A 35V Linear Regulator, Fixed Output -5V, TO-220/TO-263
U401, | 1 | STM32F103C8Tx | STM32F103C8Tx | Package_QFP:LQFP-48_7x7mm_P0.5mm | ARM Cortex-M3 MCU, 64KB flash, 20KB RAM, 72MHz, 2-3.6V, 37 GPIO, LQFP-48
U402, | 1 | SN65HVD232 | SN65HVD232 | Package_SO:SOIC-8_3.9x4.9mm_P1.27mm | CAN Bus Transceivers, 3.3V, 1Mbps, SOIC-8
X201, | 1 | 25MHz | ABLNO | Oscillator:Oscillator_SMD_EuroQuartz_XO91-4Pin_7.0x5.0mm | LVCMOS Ultra Low Phase Noise XO / VCXO, Abracon ABLNO
Y401, | 1 | 8MHz | Crystal_GND24 | Crystal:Crystal_SMD_5032-4Pin_5.0x3.2mm | Four pin crystal, GND on pins 2 and 4

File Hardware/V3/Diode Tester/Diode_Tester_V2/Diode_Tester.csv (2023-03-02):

Source: | /media/marco/Daten/Repositories/modlab/Hardware/V3/Diode_Tester_review/Diode_Tester.kicad_sch
Date: | Mi 30 Nov 2022 22:05:00 CET
Tool: | Eeschema 6.0.9-8da3e8f707~116~ubuntu20.04.1
Generator: | /usr/share/kicad/plugins/bom_csv_grouped_by_value_with_fp.py
Component Count: | 85
Ref | Qnty | Value | Cmp name | Footprint | Description | Vendor
C1, C2, C11, C12, C14, C15, C16, C17, C19, C20, C21, | 11 | 100n | C | Capacitor_SMD:C_0805_2012Metric | Unpolarized capacitor
C3, C18, | 2 | 4µ7 | C | Capacitor_SMD:C_0805_2012Metric | Unpolarized capacitor
C4, C5, | 2 | 20p | C | Capacitor_SMD:C_0805_2012Metric | Unpolarized capacitor
C6, C7, C8, C9, | 4 | 100µ | C_Polarized | Capacitor_THT:CP_Radial_D8.0mm_P5.00mm | Polarized capacitor
C10, C13, | 2 | 1µ | C | Capacitor_SMD:C_0805_2012Metric | Unpolarized capacitor
C101, | 1 | 1n | C | Capacitor_SMD:C_0805_2012Metric | Unpolarized capacitor
D1, D2, D3, D8, | 4 | 5V6 | D_Zener | Diode_SMD:D_MiniMELF | Zener diode
D4, | 1 | SMAJ5,0A | D_TVS | Diode_SMD:D_SMA | Bidirectional transient-voltage-suppression diode
D5, | 1 | P6SMB26 | D_TVS | Diode_SMD:D_SMA | Bidirectional transient-voltage-suppression diode
D6, D7, | 2 | P6SMB16 | D_TVS | Diode_SMD:D_SMA | Bidirectional transient-voltage-suppression diode
D9, | 1 | CDSOT23-T24-Q | D_TVS_Dual_AAC | Package_TO_SOT_SMD:SOT-23 | Bidirectional dual transient-voltage-suppression diode, center on pin 3
FB1, | 1 | SMB-001 | FerriteBead_Small | eigene:SMB-001 | Ferrite bead, small symbol
J1, | 1 | DIN41612_02x32_AC | DIN41612_02x32_AC | eigene:VG64_Euro | DIN41612 connector, double row (AC), 02x32, script generated (kicad-library-utils/schlib/autogen/connector/)
J2, | 1 | Diode | Conn_01x02 | Connector_PinHeader_2.54mm:PinHeader_1x02_P2.54mm_Vertical | Generic connector, single row, 01x02, script generated (kicad-library-utils/schlib/autogen/connector/)
J3, | 1 | SWD | Conn_01x04 | Connector_JST:JST_XH_B4B-XH-A_1x04_P2.50mm_Vertical | Generic connector, single row, 01x04, script generated (kicad-library-utils/schlib/autogen/connector/)
L1, | 1 | SRF3225TAC-101Y | L_Coupled_1243 | eigene:SRF3225TAC | Coupled inductor
Q1, Q4, Q7, Q10, | 4 | BSP170P | Q_PMOS_GDS | Package_TO_SOT_SMD:SOT-223-3_TabPin2 | P-MOSFET transistor, gate/drain/source
Q2, Q5, Q8, Q11, Q101, Q102, | 6 | BSS138 | BSS138 | Package_TO_SOT_SMD:SOT-23 | 50V Vds, 0.22A Id, N-Channel MOSFET, SOT-23
Q3, Q6, Q9, Q12, | 4 | BCX53 | BCX53 | Package_TO_SOT_SMD:SOT-89-3 | 1A Ic, 80V Vce, PNP Medium Power Transistor, SOT-89
R1, R6, R8, R12, R15, R19, R20, R25, | 8 | 100k | R | Resistor_SMD:R_0805_2012Metric | Resistor
R2, R3, R5, R9, R10, R16, R17, R21, R22, R26, | 10 | 10k | R | Resistor_SMD:R_0805_2012Metric | Resistor
R4, | 1 | 2k2 | R | Resistor_SMD:R_0805_2012Metric | Resistor
R7, | 1 | 4k99 | R | Resistor_SMD:R_0805_2012Metric | Resistor
R11, | 1 | 1k | R | Resistor_SMD:R_0805_2012Metric | Resistor
R13, | 1 | 100 | R | Resistor_SMD:R_0805_2012Metric | Resistor
R14, | 1 | 1M | R | Resistor_SMD:R_0805_2012Metric | Resistor
R18, R23, R24, | 3 | 499 | R | Resistor_SMD:R_0805_2012Metric | Resistor
R101, R102, R103, R104, | 4 | 4k7 | R | Resistor_SMD:R_0805_2012Metric | Resistor
U1, | 1 | LM2904 | LM2904 | Package_SO:SOIC-8_3.9x4.9mm_P1.27mm | Dual Operational Amplifiers, DIP-8/SOIC-8/TSSOP-8/VSSOP-8
U2, | 1 | STM32F103C8Tx | STM32F103C8Tx | Package_QFP:LQFP-48_7x7mm_P0.5mm | ARM Cortex-M3 MCU, 64KB flash, 20KB RAM, 72MHz, 2-3.6V, 37 GPIO, LQFP-48
U3, | 1 | AP1117-33 | AP1117-33 | Package_TO_SOT_SMD:SOT-223-3_TabPin2 | 1A Low Dropout regulator, positive, 3.3V fixed output, SOT-223
U4, | 1 | SN65HVD232 | SN65HVD232 | Package_SO:SOIC-8_3.9x4.9mm_P1.27mm | CAN Bus Transceivers, 3.3V, 1Mbps, SOIC-8
Y1, | 1 | 8MHz | Crystal_GND24 | Crystal:Crystal_SMD_5032-4Pin_5.0x3.2mm | Four pin crystal, GND on pins 2 and 4

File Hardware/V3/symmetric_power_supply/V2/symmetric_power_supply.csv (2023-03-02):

Source: | /media/marco/Daten/Repositories/modlab/Hardware/V3/symmetric_power_supply/symmetric_power_supply.kicad_sch
Date: | Mi 30 Nov 2022 21:16:26 CET
Tool: | Eeschema 6.0.9-8da3e8f707~116~ubuntu20.04.1
Generator: | /usr/share/kicad/plugins/bom_csv_grouped_by_value_with_fp.py
Component Count: | 197
Ref | Qnty | Value | Cmp name | Footprint | Description | Vendor
C201, C207, C208, C211, C301, C307, C308, C314, C403, C404, C505, C508, | 12 | 1µ | C | Capacitor_SMD:C_0805_2012Metric | Unpolarized capacitor
C202, C205, C302, C305, | 4 | 100µ | C_Polarized | Capacitor_SMD:CP_Elec_5x5.8 | Polarized capacitor
C203, C204, C206, C209, C210, C213, C214, C303, C304, C306, C309, C310, C311, C312, C401, C402, C407, C408, C409, C410, C411, C506, C507, C613, C614, | 25 | 100n | C | Capacitor_SMD:C_0805_2012Metric | Unpolarized capacitor
C212, C313, C413, C414, C415, | 5 | 1n | C | Capacitor_SMD:C_0805_2012Metric | Unpolarized capacitor
C405, C406, | 2 | 20p | C | Capacitor_SMD:C_0805_2012Metric | Unpolarized capacitor
C412, | 1 | 4µ7 | C | Capacitor_SMD:C_0805_2012Metric | Unpolarized capacitor
C501, C502, C503, C504, | 4 | 100µ | C_Polarized | Capacitor_THT:CP_Radial_D8.0mm_P5.00mm | Polarized capacitor
C601, C602, C604, C606, C607, C608, C610, C612, | 8 | 470n | C | Capacitor_SMD:C_0805_2012Metric | Unpolarized capacitor
C603, C605, C609, C611, | 4 | 5n6 | C | Capacitor_SMD:C_0805_2012Metric | Unpolarized capacitor
D101, | 1 | LL4148 | LL4148 | Diode_SMD:D_MiniMELF | 100V 0.15A standard switching diode, MiniMELF
D201, D202, D203, D301, D302, D303, | 6 | D_Schottky | D_Schottky | Diode_SMD:D_MiniMELF | Schottky diode
D204, D206, D207, D304, D306, D307, | 6 | 5V1 | D_Zener | Diode_SMD:D_MiniMELF | Zener diode
D205, D305, | 2 | CC+ | LED | LED_THT:LED_D3.0mm | Light emitting diode
D401, | 1 | CDSOT23-T24-Q | D_TVS_Dual_AAC | Package_TO_SOT_SMD:SOT-23 | Bidirectional dual transient-voltage-suppression diode, center on pin 3
D501, | 1 | SMAJ5,0A | D_TVS | Diode_SMD:D_SMA | Bidirectional transient-voltage-suppression diode
D502, | 1 | P6SMB26 | D_TVS | Diode_SMD:D_SMA | Bidirectional transient-voltage-suppression diode
D503, D504, | 2 | P6SMB16 | D_TVS | Diode_SMD:D_SMA | Bidirectional transient-voltage-suppression diode
FB401, | 1 | SMB-001 | FerriteBead_Small | eigene:SMB-001 | Ferrite bead, small symbol
HS201, HS301, | 2 | Heatsink | Heatsink | eigene:SK574-50 | Heatsink
J101, | 1 | DIN41612_02x32_AC | DIN41612_02x32_AC | eigene:VG64_Euro | DIN41612 connector, double row (AC), 02x32, script generated (kicad-library-utils/schlib/autogen/connector/)
J102, | 1 | V+ | Conn_01x02 | Connector_PinHeader_2.54mm:PinHeader_1x02_P2.54mm_Vertical | Generic connector, single row, 01x02, script generated (kicad-library-utils/schlib/autogen/connector/)
J103, | 1 | V- | Conn_01x02 | Connector_PinHeader_2.54mm:PinHeader_1x02_P2.54mm_Vertical | Generic connector, single row, 01x02, script generated (kicad-library-utils/schlib/autogen/connector/)
J401, | 1 | SWD | Conn_01x04 | Connector_JST:JST_XH_B4B-XH-A_1x04_P2.50mm_Vertical | Generic connector, single row, 01x04, script generated (kicad-library-utils/schlib/autogen/connector/)
J402, | 1 | Address | Conn_02x02_Odd_Even | Connector_PinHeader_2.54mm:PinHeader_2x02_P2.54mm_Vertical | Generic connector, double row, 02x02, odd/even pin numbering scheme (row 1 odd numbers, row 2 even numbers), script generated (kicad-library-utils/schlib/autogen/connector/)
K101, | 1 | G6K-2 | G6K-2 | Relay_SMD:Relay_DPDT_Omron_G6K-2F | Miniature 2-pole relay, Single-side Stable
L401, | 1 | SRF3225TAC-101Y | L_Coupled_1243 | eigene:SRF3225TAC | Coupled inductor
Q101, Q401, Q402, | 3 | BSS138 | BSS138 | Package_TO_SOT_SMD:SOT-23 | 50V Vds, 0.22A Id, N-Channel MOSFET, SOT-23
Q201, | 1 | TIP107 | TIP127 | Package_TO_SOT_THT:TO-220-3_Vertical | 5A Ic, 100V Vce, Silicon Darlington Power PNP Transistor, TO-220
Q301, | 1 | TIP102 | TIP122 | Package_TO_SOT_THT:TO-220-3_Vertical | 5A Ic, 100V Vce, Silicon Darlington Power NPN Transistor, TO-220
R101, R211, R309, R401, R408, R409, | 6 | 10k | R | Resistor_SMD:R_0805_2012Metric | Resistor
R102, | 1 | 100k | R | Resistor_SMD:R_0805_2012Metric | Resistor
R201, R301, | 2 | R500 | R | Resistor_SMD:R_2512_6332Metric | Resistor
R202, R205, R207, R209, R212, R214, R216, R302, R305, R306, R308, R310, R311, R313, R319, R320, R607, R608, R617, R618, | 20 | 1k | R | Resistor_SMD:R_0805_2012Metric | Resistor
R203, R303, | 2 | 200 | R | Resistor_SMD:R_0805_2012Metric | Resistor
R204, R213, R219, R221, R226, R304, R315, R317, R323, R328, | 10 | 5k1 | R | Resistor_SMD:R_0805_2012Metric | Resistor
R206, R210, R215, R312, R321, R322, R325, | 7 | 2k | R | Resistor_SMD:R_0805_2012Metric | Resistor
R208, R224, R307, R402, | 4 | 100 | R | Resistor_SMD:R_0805_2012Metric | Resistor
R217, R223, R314, R326, | 4 | 20k | R | Resistor_SMD:R_0805_2012Metric | Resistor
R218, R220, R316, R324, | 4 | 510 | R | Resistor_SMD:R_0805_2012Metric | Resistor
R222, R318, | 2 | 200k | R | Resistor_SMD:R_0805_2012Metric | Resistor
R225, | 1 | 3k9 | R | Resistor_SMD:R_0805_2012Metric | Resistor
R227, | 1 | 12k | R | Resistor_SMD:R_0805_2012Metric | Resistor
R327, | 1 | 3k | R | Resistor_SMD:R_0805_2012Metric | Resistor
R403, | 1 | 1M | R | Resistor_SMD:R_0805_2012Metric | Resistor
R404, R405, R406, R407, | 4 | 4k7 | R | Resistor_SMD:R_0805_2012Metric | Resistor
R601, R602, R611, R612, | 4 | 1k3 | R | Resistor_SMD:R_0805_2012Metric | Resistor
R603, R604, R605, R606, R613, R614, R615, R616, | 8 | 22k | R | Resistor_SMD:R_0805_2012Metric | Resistor
R609, R610, R619, R620, | 4 | 1k8 | R | Resistor_SMD:R_0805_2012Metric | Resistor
U201, | 1 | LM317_TO-220 | LM317_TO-220 | Package_TO_SOT_THT:TO-220-3_Vertical | 1.5A 35V Adjustable Linear Regulator, TO-220
U202, U203, U302, U303, U601, | 5 | LM2902 | LM2902 | Package_SO:TSSOP-14_4.4x5mm_P0.65mm | Low-Power, Quad-Operational Amplifiers, DIP-14/SOIC-14/SSOP-14
U301, | 1 | LM337_TO220 | LM337_TO220 | Package_TO_SOT_THT:TO-220-3_Vertical | Negative 1.5A 35V Adjustable Linear Regulator, TO-220
U401, | 1 | SN65HVD232 | SN65HVD232 | Package_SO:SOIC-8_3.9x4.9mm_P1.27mm | CAN Bus Transceivers, 3.3V, 1Mbps, SOIC-8
U402, | 1 | STM32F103C8Tx | STM32F103C8Tx | Package_QFP:LQFP-48_7x7mm_P0.5mm | ARM Cortex-M3 MCU, 64KB flash, 20KB RAM, 72MHz, 2-3.6V, 37 GPIO, LQFP-48
U501, | 1 | AP1117-33 | AP1117-33 | Package_TO_SOT_SMD:SOT-223-3_TabPin2 | 1A Low Dropout regulator, positive, 3.3V fixed output, SOT-223
Y401, | 1 | 8MHz | Crystal_GND24 | Crystal:Crystal_SMD_5032-4Pin_5.0x3.2mm | Four pin crystal, GND on pins 2 and 4

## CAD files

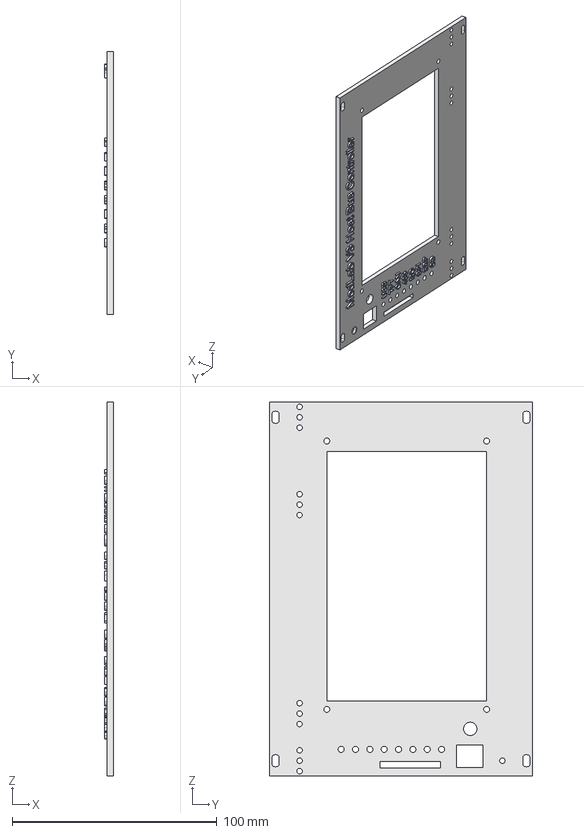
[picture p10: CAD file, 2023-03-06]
Hardware/frontpanels/finished/Mainboard.FCStd
4.20 x 128.4 x 182.5 mm

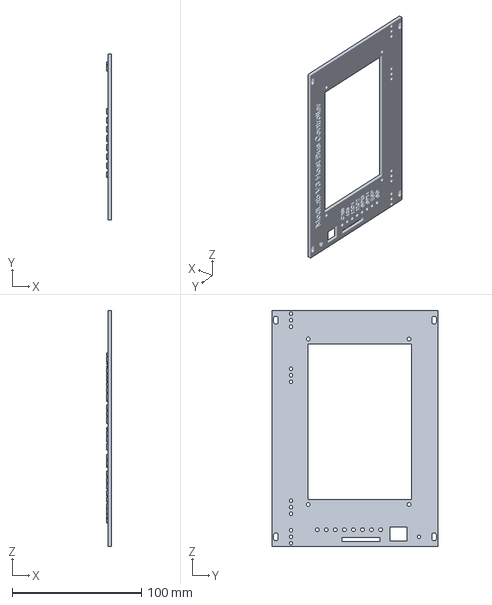
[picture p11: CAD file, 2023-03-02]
Hardware/frontpanels/finished/Mainboard-Fusion.3mf
4.20 x 128.4 x 182.5 mm

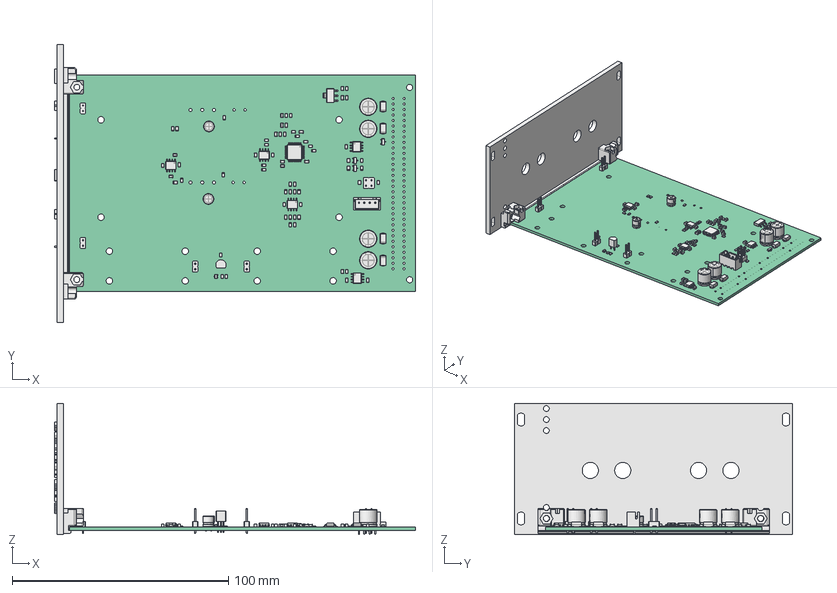
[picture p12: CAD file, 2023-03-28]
Hardware/frontpanels/finished/Load.FCStd
166.8 x 128.4 x 60.6 mm
Pcb_5dde
Q302_SOT_23_5aa36380b906 x 3
R406_R_0805_2012Metric_dbe696ebd58a x 28
C410_C_0805_2012Metric_39844dc6e4f0 x 37
C502_CP_Radial_D50mm_P250mm_9e7d7d4ebcc8 x 2
C201_CP_Radial_D80mm_P500mm_4f7a9125f3ea x 4
J401_PinHeader_1x02_P254mm_Vertical_9ab79631aaa3 x 4
U501_SOIC_8_39x49mm_P127mm_cbdf0bf1c484 x 5
Q401_SOT_323_SC_70_3df990fc4644
J301_PinHeader_2x02_P254mm_Vertical_6c767bdf64cd
J302_JST_B4B_XH_A_b57676c56ff9
U302_LQFP_48_7x7mm_P05mm_932f12d4d664
D201_D_SMA_8ed215d73d20 x 4
U201_SOT_223_ac06fcdf0345
U401_TO-92_Narrow_d3fd7e2a0b4e

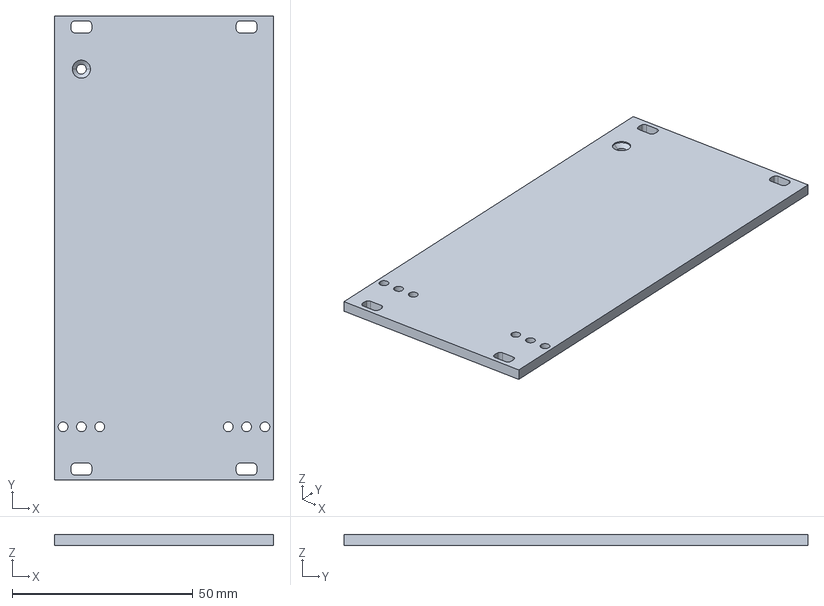
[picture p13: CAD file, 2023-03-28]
Hardware/frontpanels/Templates/12-TE.stp
60.6 x 128.4 x 3.00 mm

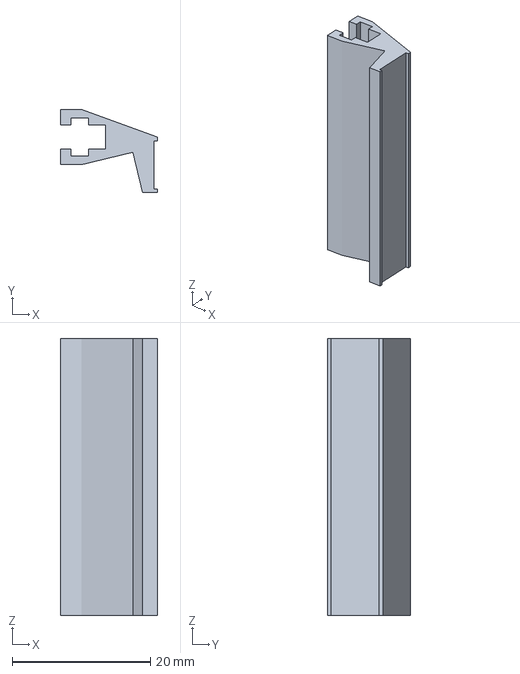
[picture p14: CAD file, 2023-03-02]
Hardware/frontpanels/Templates/Unnamed1-GLA_08.3mf
14.0 x 12.0 x 40.1 mm

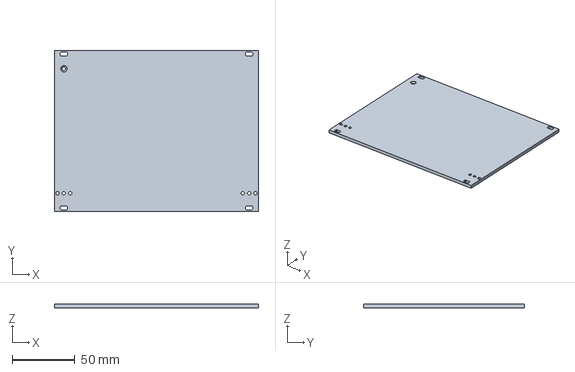
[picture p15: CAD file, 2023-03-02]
Hardware/frontpanels/Templates/4x.stp
162.2 x 128.4 x 3.00 mm

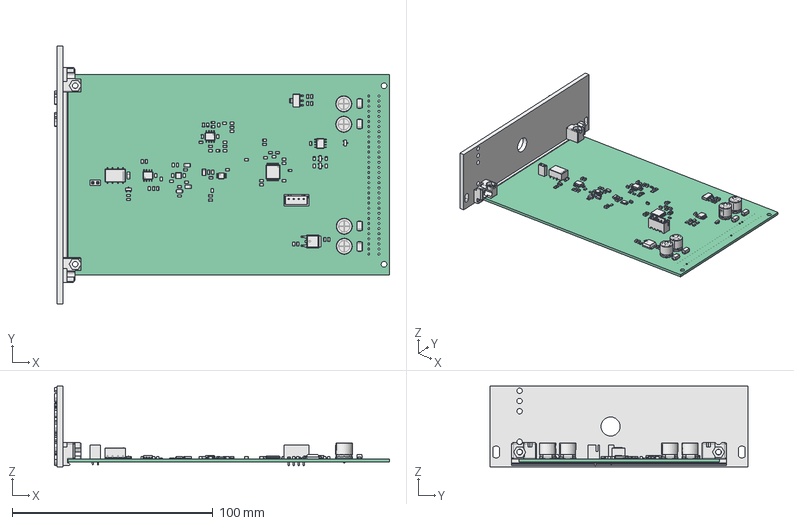
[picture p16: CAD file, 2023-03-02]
Hardware/frontpanels/finished/Function-Generator.FCStd
166.8 x 128.4 x 40.3 mm
Pcb_7baf
C403_C_0805_2012Metric_edeb690bf77f x 40
D302_D_SMA_2a030f57046a x 4
D401_SOT_23_fb0cf6e6d12a x 4
U203_SOIC_8_39x49mm_P127mm_45e52854935c x 3
C303_CP_Radial_D80mm_P500mm_457404f776d5 x 4
R209_R_0805_2012Metric_e5286bfec6ab x 29
J401_JST_B4B_XH_A_735f5a461ca8
U302_TO_252_2_8b0ed1c28309
J201_PinSocket_1x02_P254mm_Vertical_725b7ae7073a
K201_Relay_DPDT_Omron_G6K-2F_8b1289803d2b
U204_VSSOP_10_3x3mm_P05mm_2ff2bc5c2956
C226_CP_EIA_3216_12_Kemet_S_41a29565b7cd x 4
D201_D_MiniMELF_Standard_d14fcf1fa4a9
U301_SOT_223_32e5701cf2bd
U201_MSOP_10_3x3mm_P05mm_a6743a9209a3
U401_LQFP_48_7x7mm_P05mm_3fa97d5f2f33

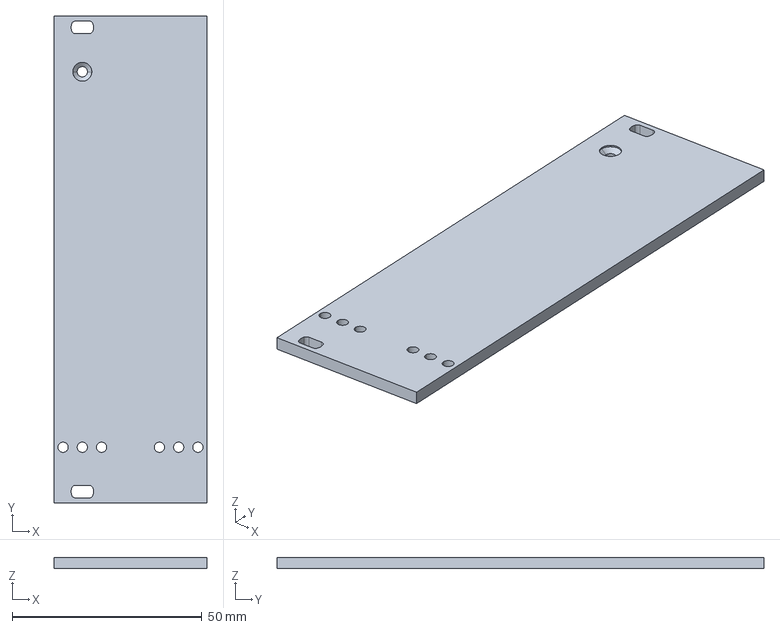
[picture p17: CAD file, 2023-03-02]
Hardware/frontpanels/Templates/1x.stp
40.3 x 128.4 x 3.00 mm

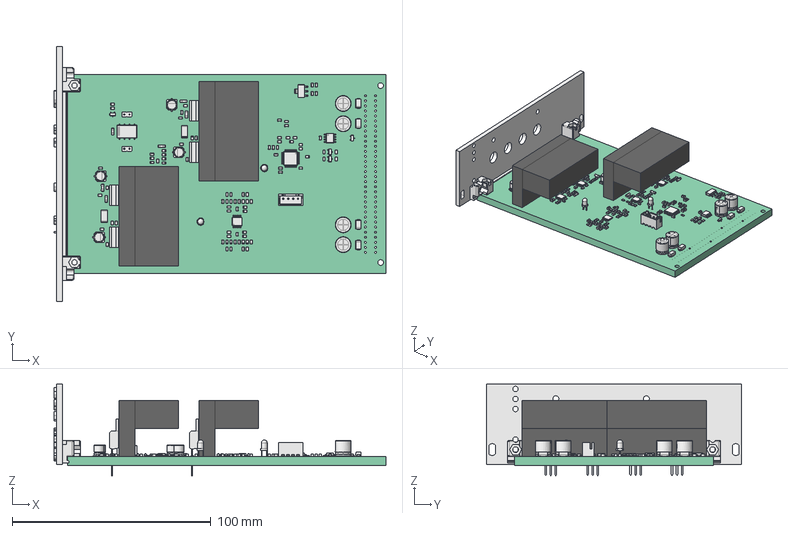
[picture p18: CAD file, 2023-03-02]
Hardware/frontpanels/finished/SymPSU.FCStd
166.8 x 128.4 x 46.0 mm
Pcb_eea0
R305_R_0805_2012Metric_d4390b8aedc9 x 82
C404_C_0805_2012Metric_4f9835c24dbc x 57
D401_SOT_23_885be460aa39 x 4
C305_CP_Elec_5x58_83f1d23d5c20 x 4
J103_PinHeader_1x02_P254mm_Vertical_a5a0741d93d4 x 2
Q301_TO-220-3_Vertical_84665c3eb96e x 4
D201_D_MiniMELF_Standard_9fa6f05ee30e x 13
C502_CP_Radial_D80mm_P500mm_f7bb1ab137ee x 4
HS301_Fusion_cec4f3be260f x 2
D504_D_SMA_77182e544d70 x 4
U303_TSSOP_14_44x5mm_P065mm_2e82b6f46665 x 5
R201_R_2512_6332Metric_c631018dffc0 x 2
U402_LQFP_48_7x7mm_P05mm_22699c8b8ca6
D205_LED_D3.0mm_53bd5569a155 x 2
J401_JST_B4B_XH_A_da695583f06e
U501_SOT_223_43830b2746e8
U401_SOIC_8_39x49mm_P127mm_fb4016ba978a
K101_Relay_DPDT_Omron_G6K-2F_c35e7c1a70be

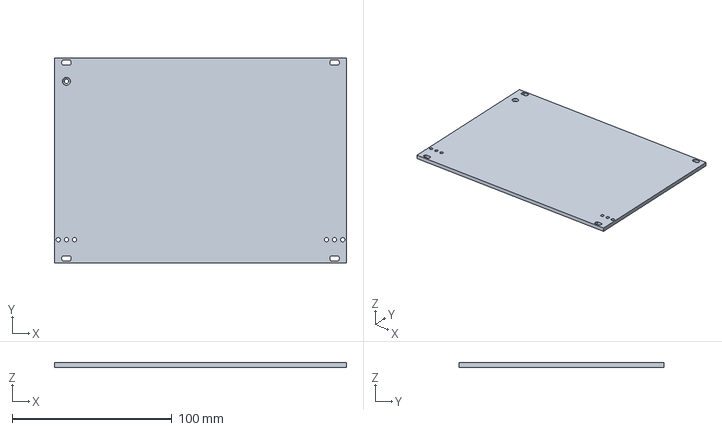
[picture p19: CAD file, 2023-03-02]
Hardware/frontpanels/Templates/36-TE.stp
182.5 x 128.4 x 3.00 mm

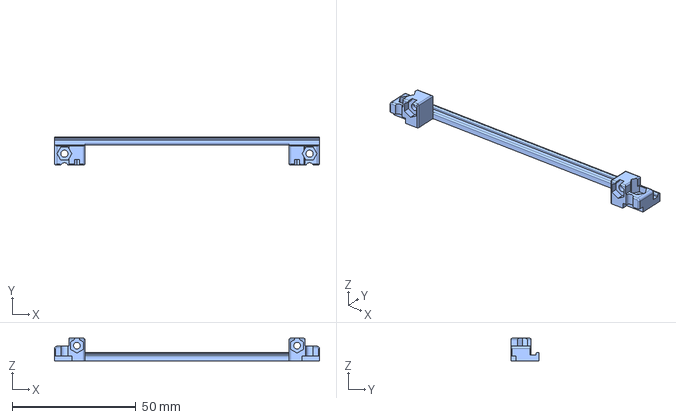
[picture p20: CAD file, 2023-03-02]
Hardware/frontpanels/Templates/vs1.stp
107.0 x 11.5 x 9.10 mm

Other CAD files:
Hardware/frontpanels/finished/Mainboard-NEXTION.3mf
Hardware/frontpanels/Templates/Unnamed1-Compound.stl
Hardware/frontpanels/Templates/gla_08.stp
Hardware/frontpanels/finished/Diode_Tester.FCStd
Hardware/frontpanels/finished/SMPS.FCStd
Hardware/frontpanels/finished/Diode_Tester.3mf
Hardware/frontpanels/finished/Load.3mf
Hardware/frontpanels/finished/SMPS.3mf
Hardware/frontpanels/finished/SymPSU.3mf
Hardware/frontpanels/finished/function_generator.3mf

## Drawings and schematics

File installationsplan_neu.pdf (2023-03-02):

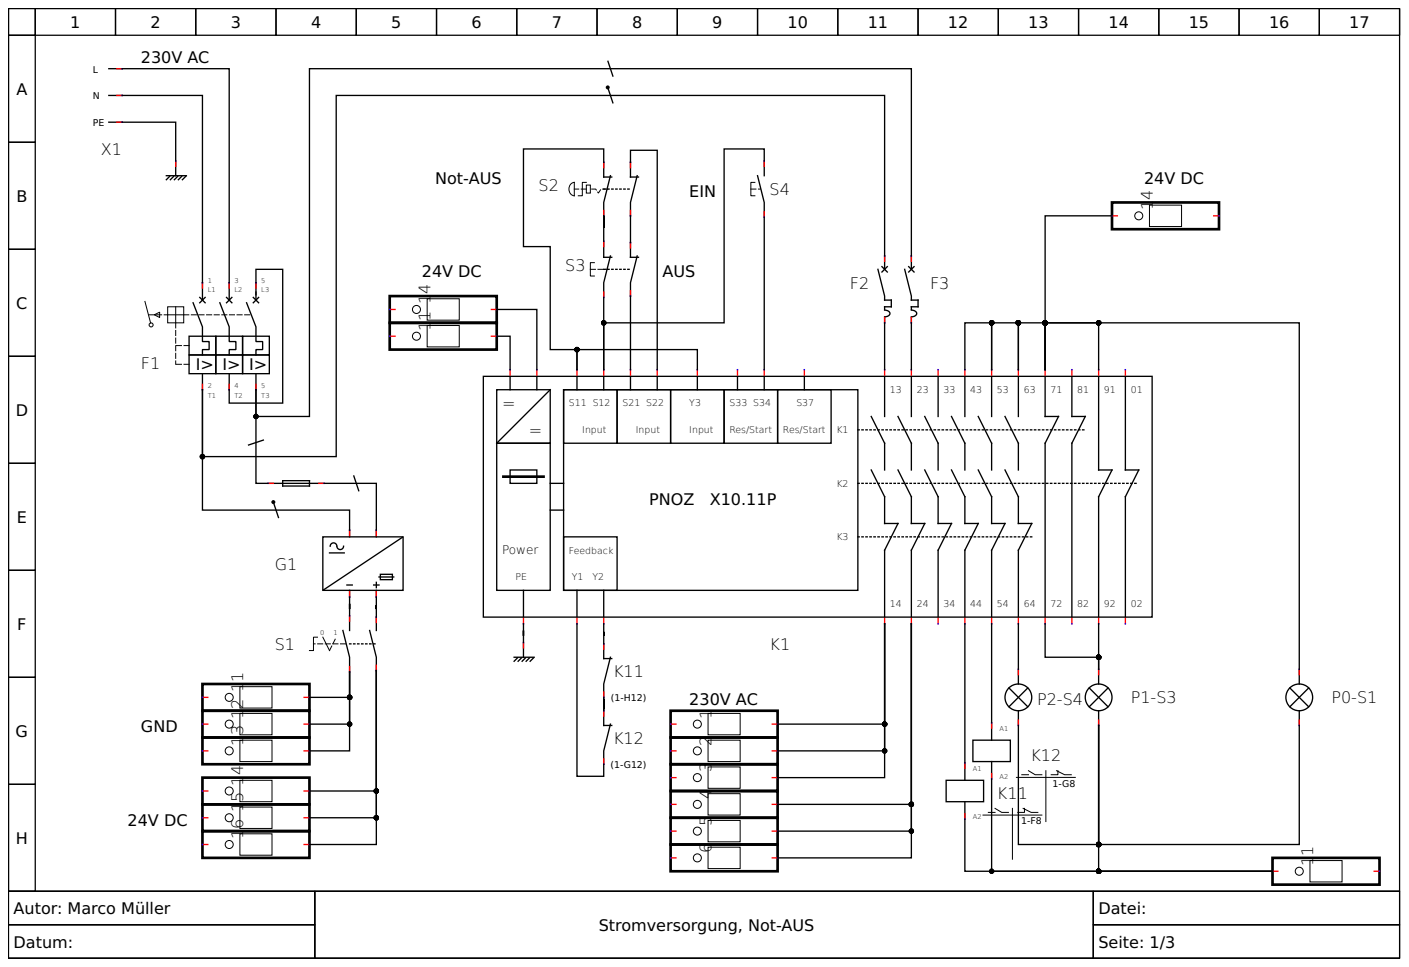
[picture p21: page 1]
Datei:; Datum:; Seite: 1/3; Input; Res/Start; Feedback; Power; Not-AUS; AUS; EIN; GND; PNOZ X10.11P

Autor: Marco Müller

Stromversorgung, Not-AUS

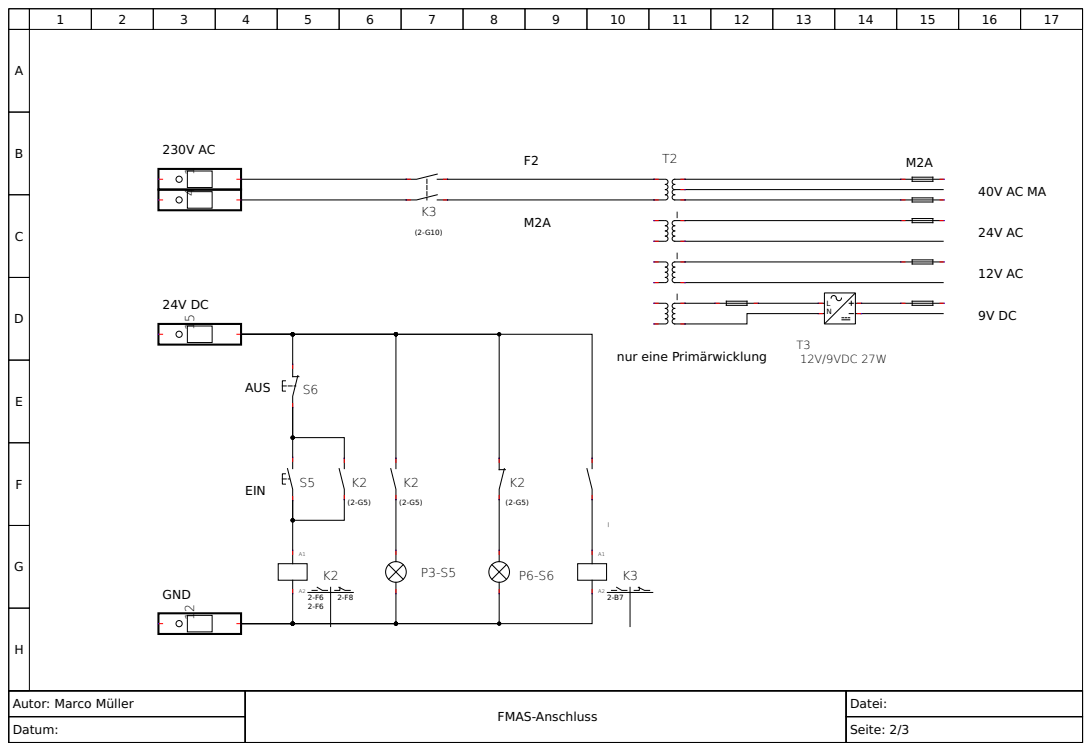
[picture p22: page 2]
FMAS-Anschluss; Datei:; T3 12V/9VDC 27W; GND; AUS; EIN

nur eine Primärwicklung

Autor: Marco Müller

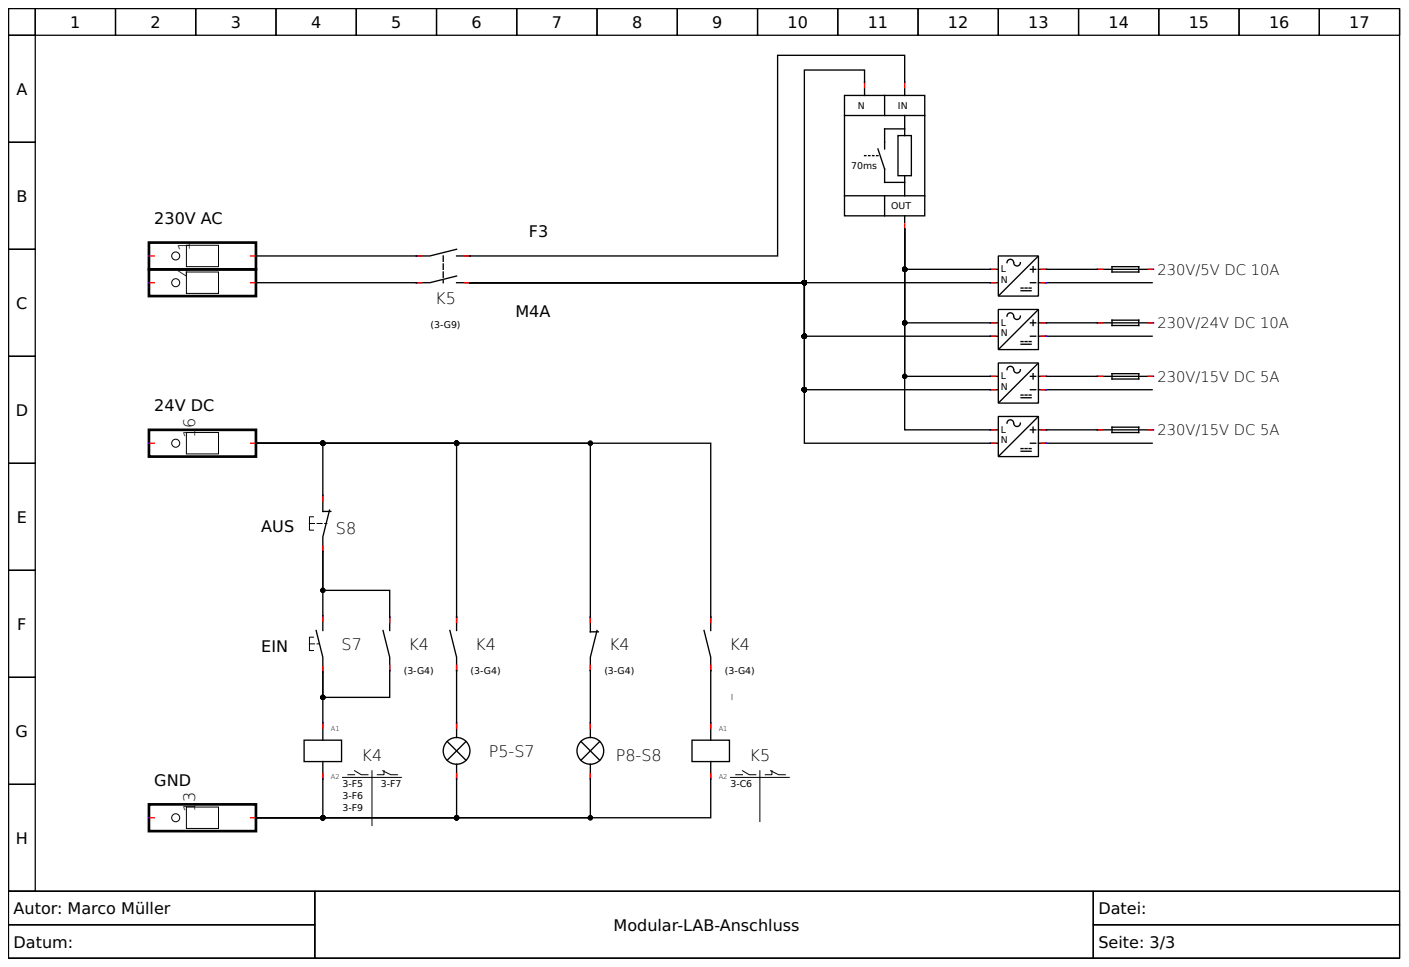
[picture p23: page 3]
Datei:; OUT; GND; AUS; EIN

Autor: Marco Müller

Modular-LAB-Anschluss

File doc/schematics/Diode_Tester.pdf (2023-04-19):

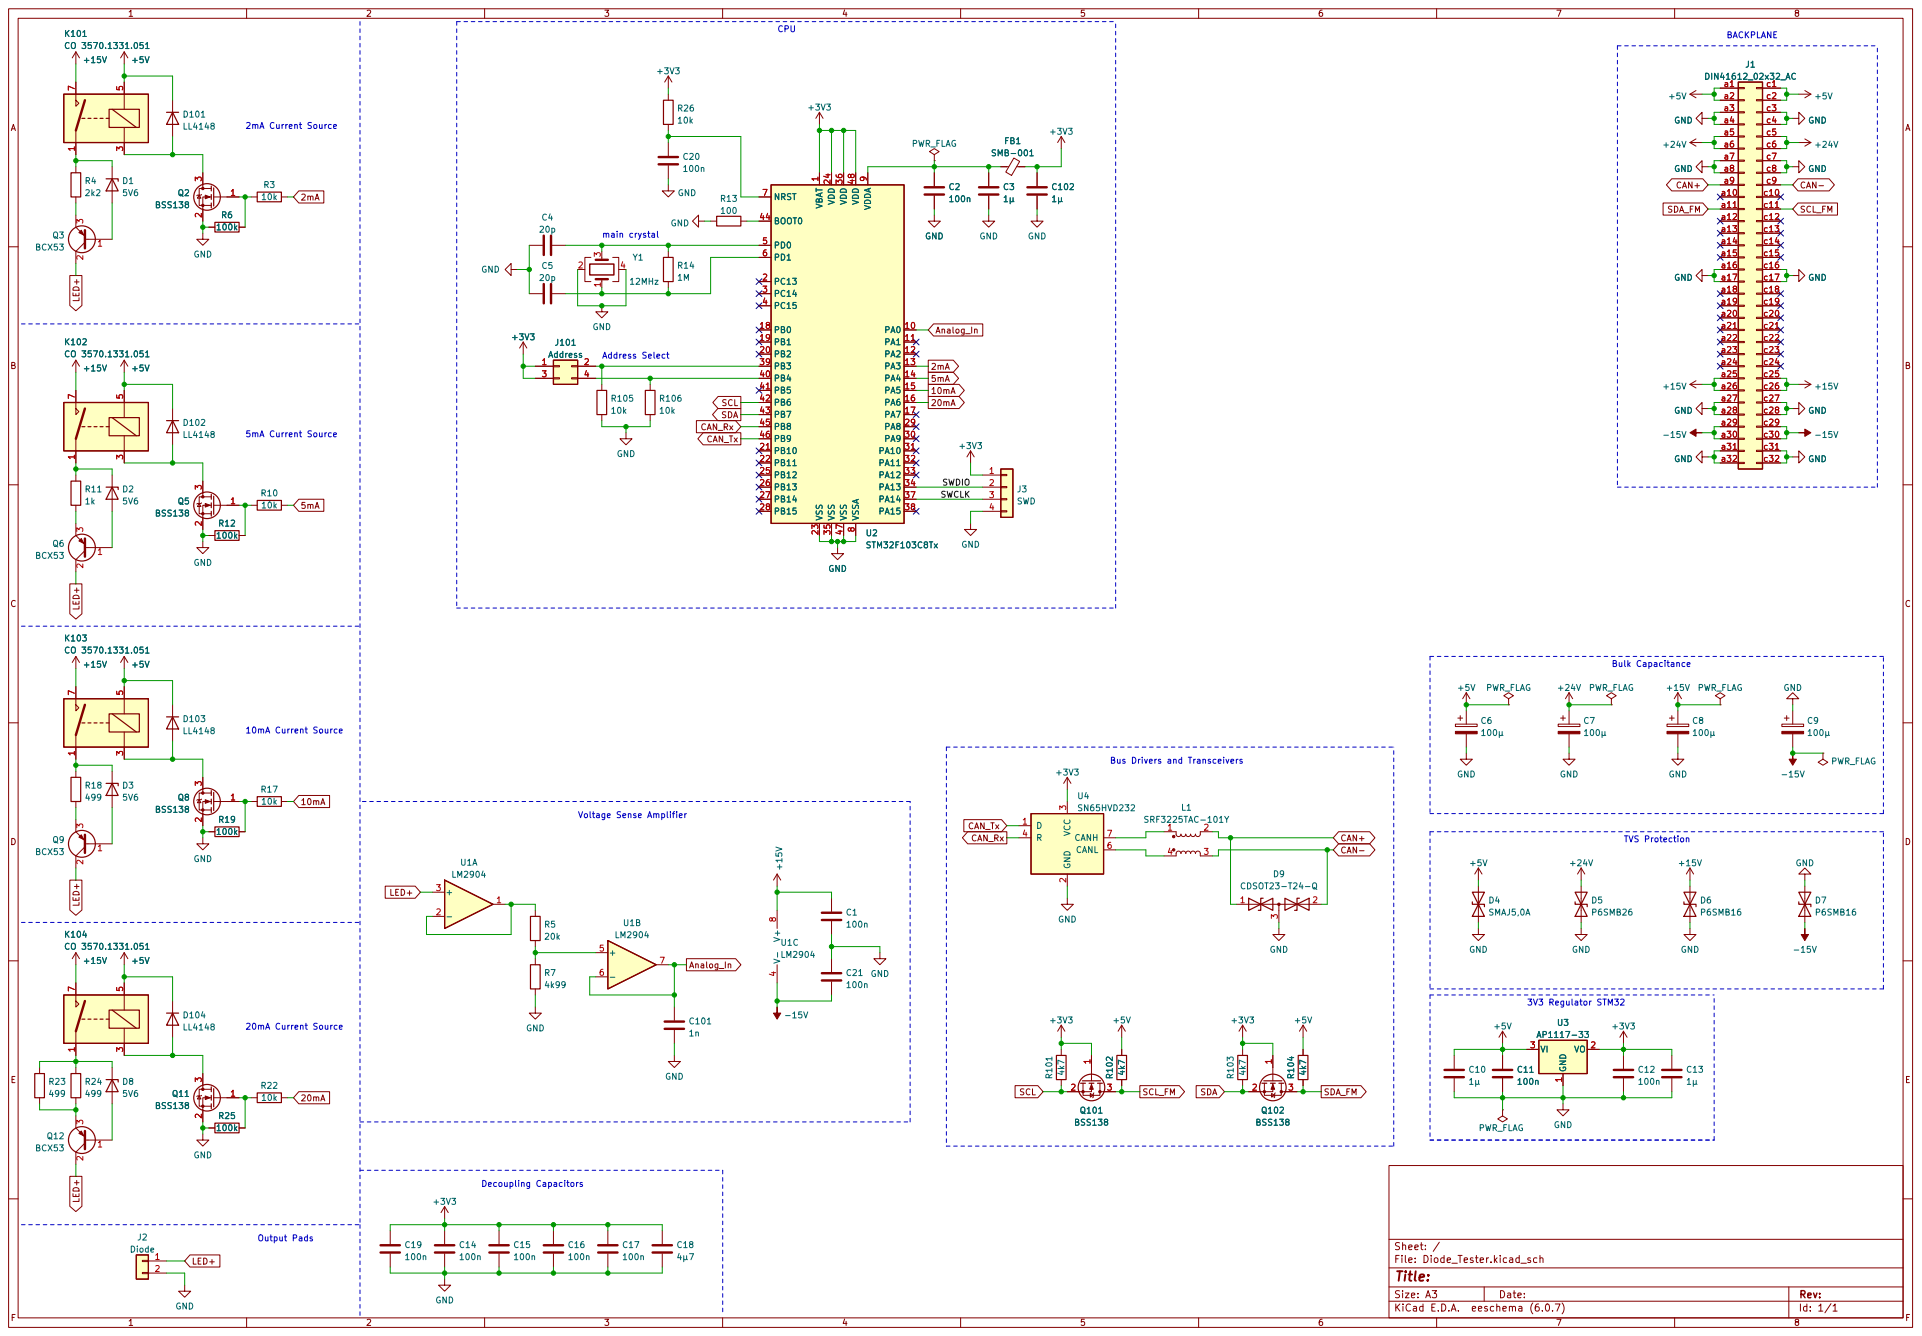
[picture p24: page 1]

1 PA0 10 PA1 11 PA2 12 PA3 13 PA4 14 PA5 15 PA6 16 PA7 17 PB0 18 PB1 19 PC13 2 PB2 20 PB10 21 PB11 22 VSS 23 VDD 24 PB12 25 PB13 26 PB14 27 PB15 28 PA8 29 PC14 3 PA9 30 PA10 31 PA11 32 PA12 33 PA13 34 VSS 35 VDD 36 PA14 37 PA15 38 PB3 39 PC15 4 PB4 40 PB5 41 PB6 42 PB7 43 BOOT0 44 PB8 45 PB9 46 VSS 47 VDD 48 PD0 5 PD1 6 NRST 7 VSSA

10mA Current Source Output Pads

TVS Protection Bus Drivers and Transceivers

Decoupling Capacitors 20mA Current Source

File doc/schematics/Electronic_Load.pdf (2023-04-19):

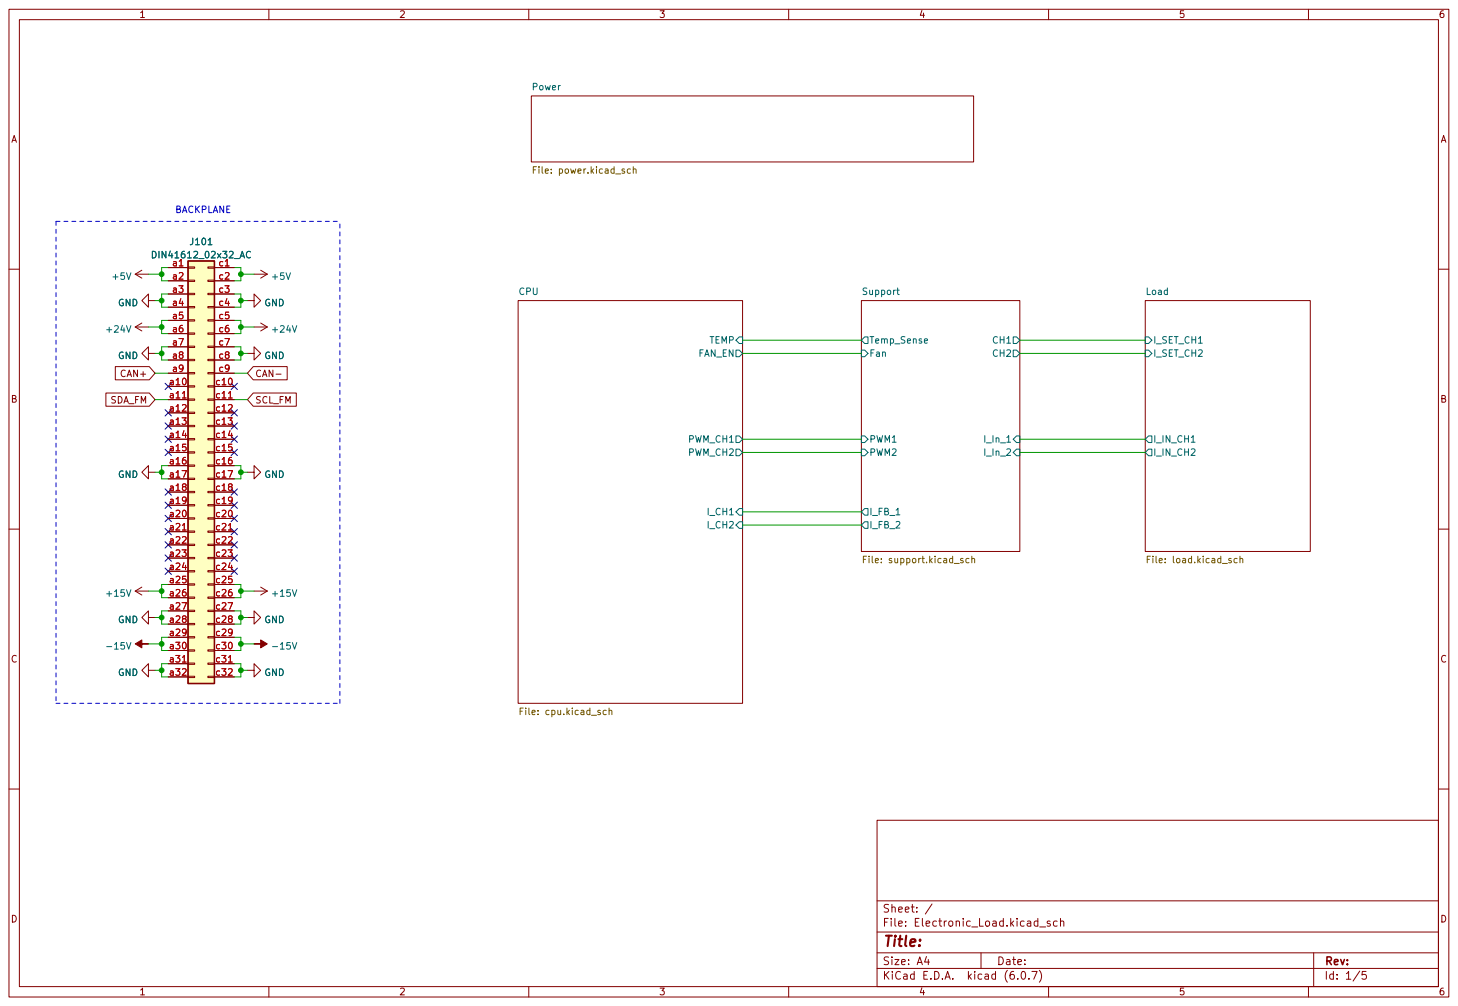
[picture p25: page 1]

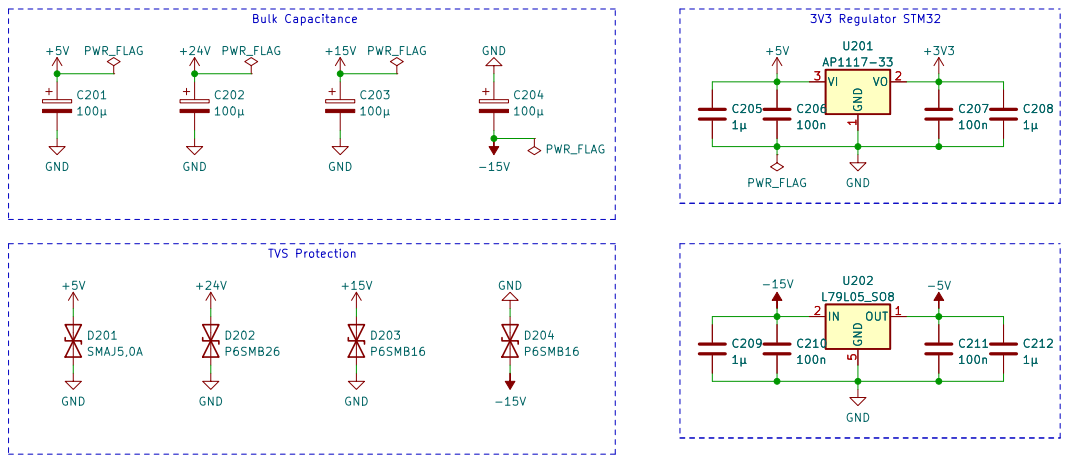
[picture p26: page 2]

100n Bulk Capacitance TVS Protection

File: power.kicad_sch Sheet: /Power/
Id: 2/5 Title:

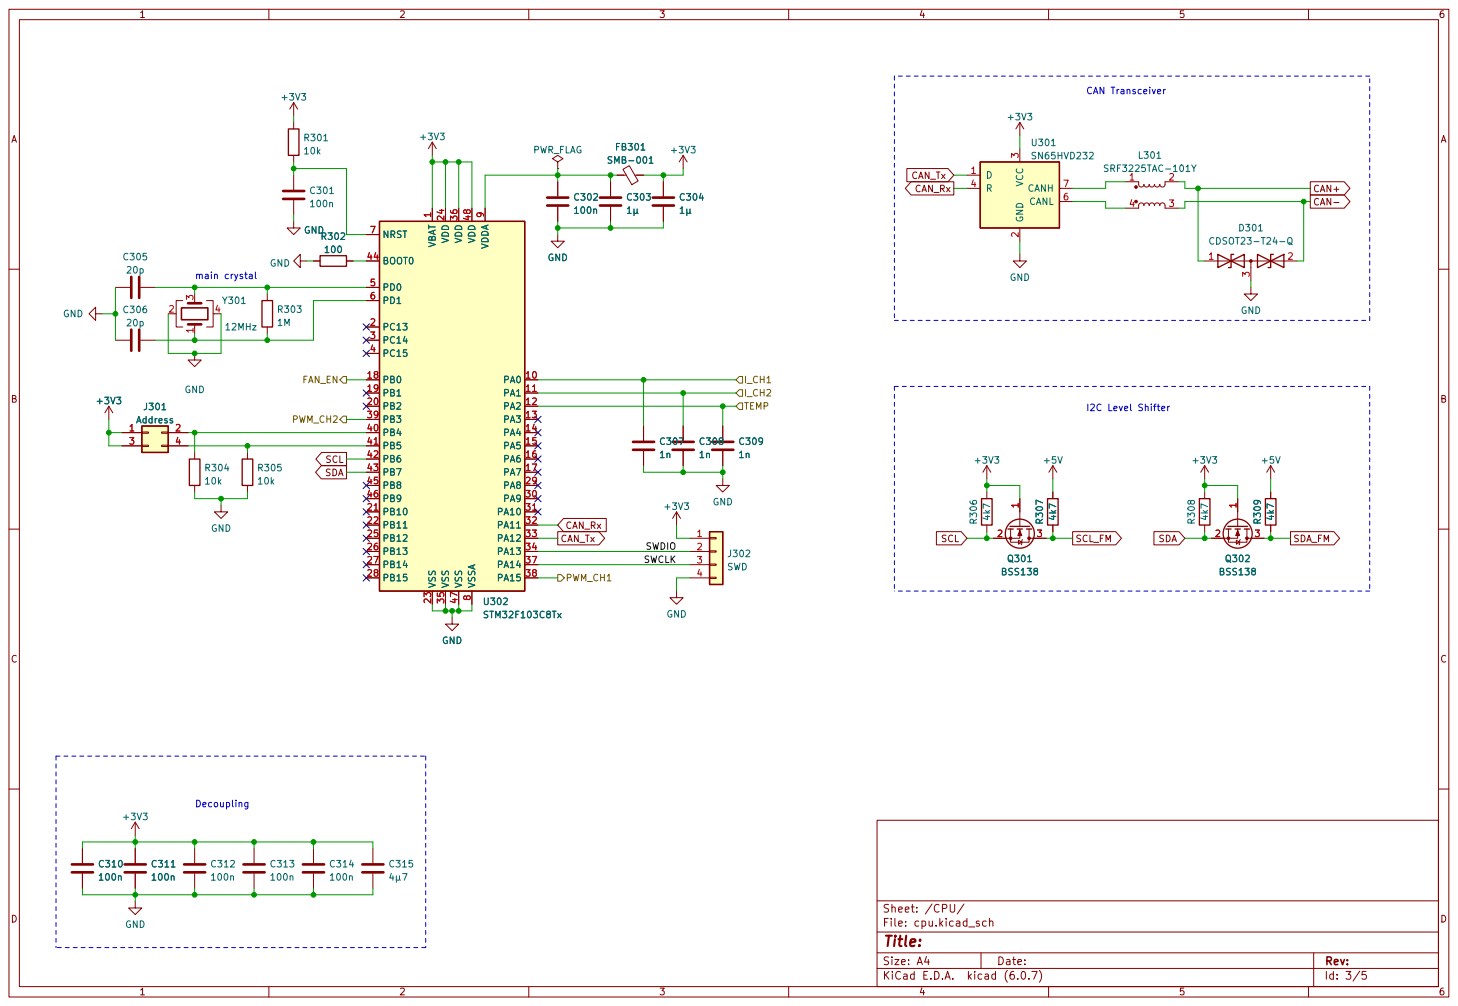
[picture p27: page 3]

1 PA0 10 PA1 11 PA2 12 PA3 13 PA4 14 PA5 15 PA6 16 PA7 17 PB0 18 PB1 19 PC13 2 PB2 20 PB10 21 PB11 22 VSS 23 VDD 24 PB12 25 PB13 26 PB14 27 PB15 28 PA8 29 PC14 3 PA9 30 PA10 31 PA11 32 PA12 33 PA13 34 VSS 35 VDD 36 PA14 37 PA15 38 PB3 39 PC15 4 PB4 40 PB5 41 PB6 42 PB7 43 BOOT0 44 PB8 45 PB9 46 VSS 47 VDD 48 PD0 5 PD1 6 NRST 7 VSSA

File: cpu.kicad_sch Sheet: /CPU/
Id: 3/5 Title:

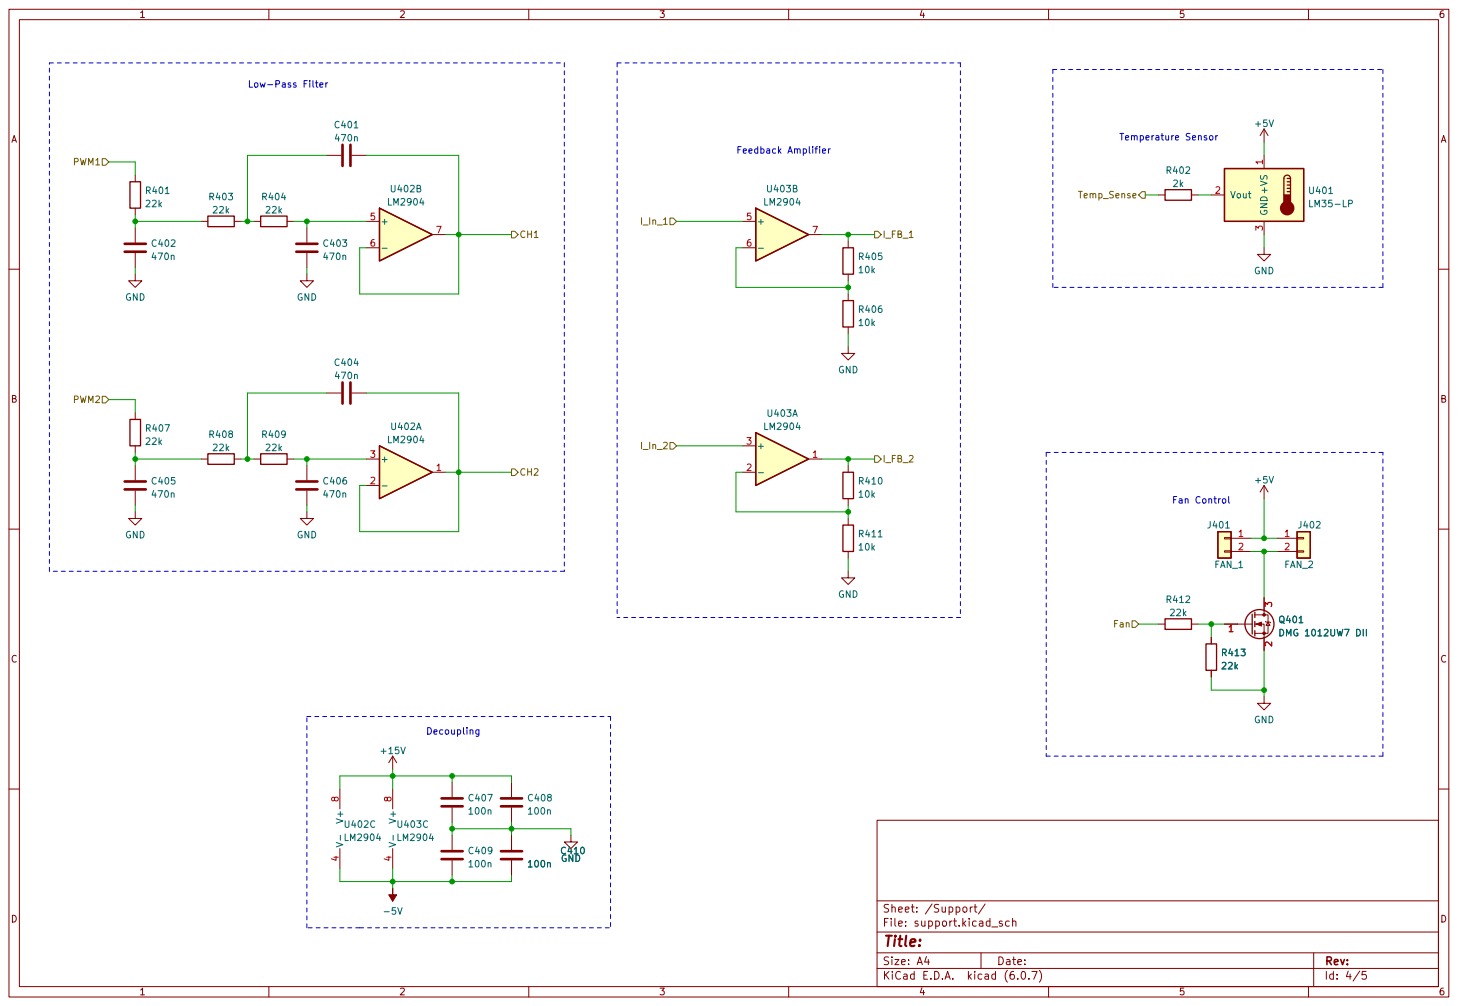
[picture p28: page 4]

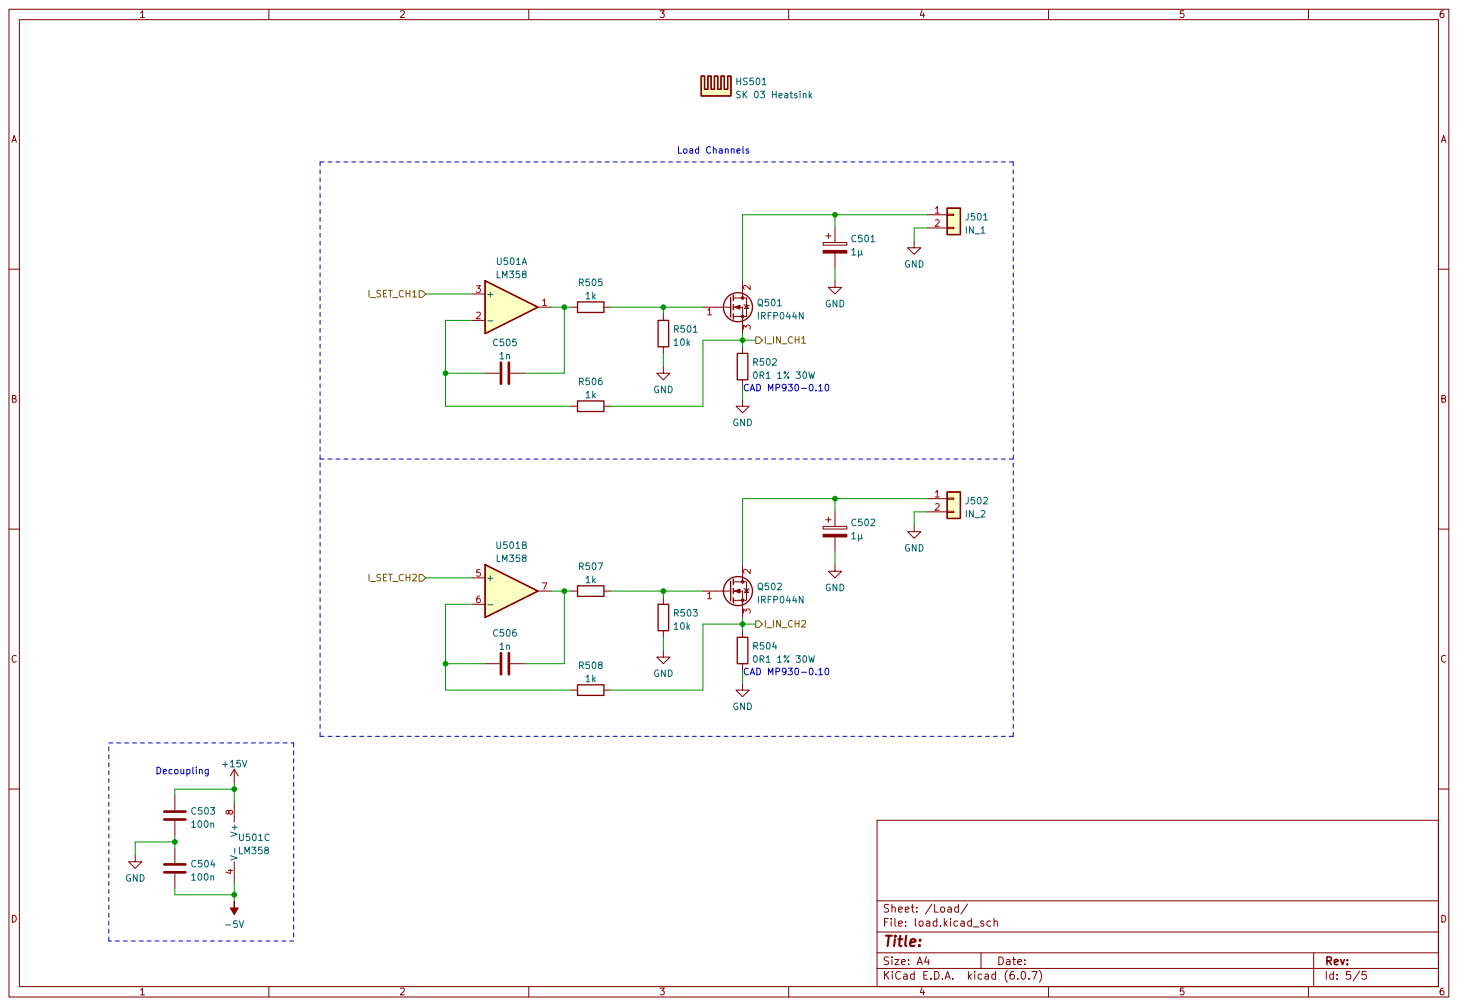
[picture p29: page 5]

File: load.kicad_sch Sheet: /Load/

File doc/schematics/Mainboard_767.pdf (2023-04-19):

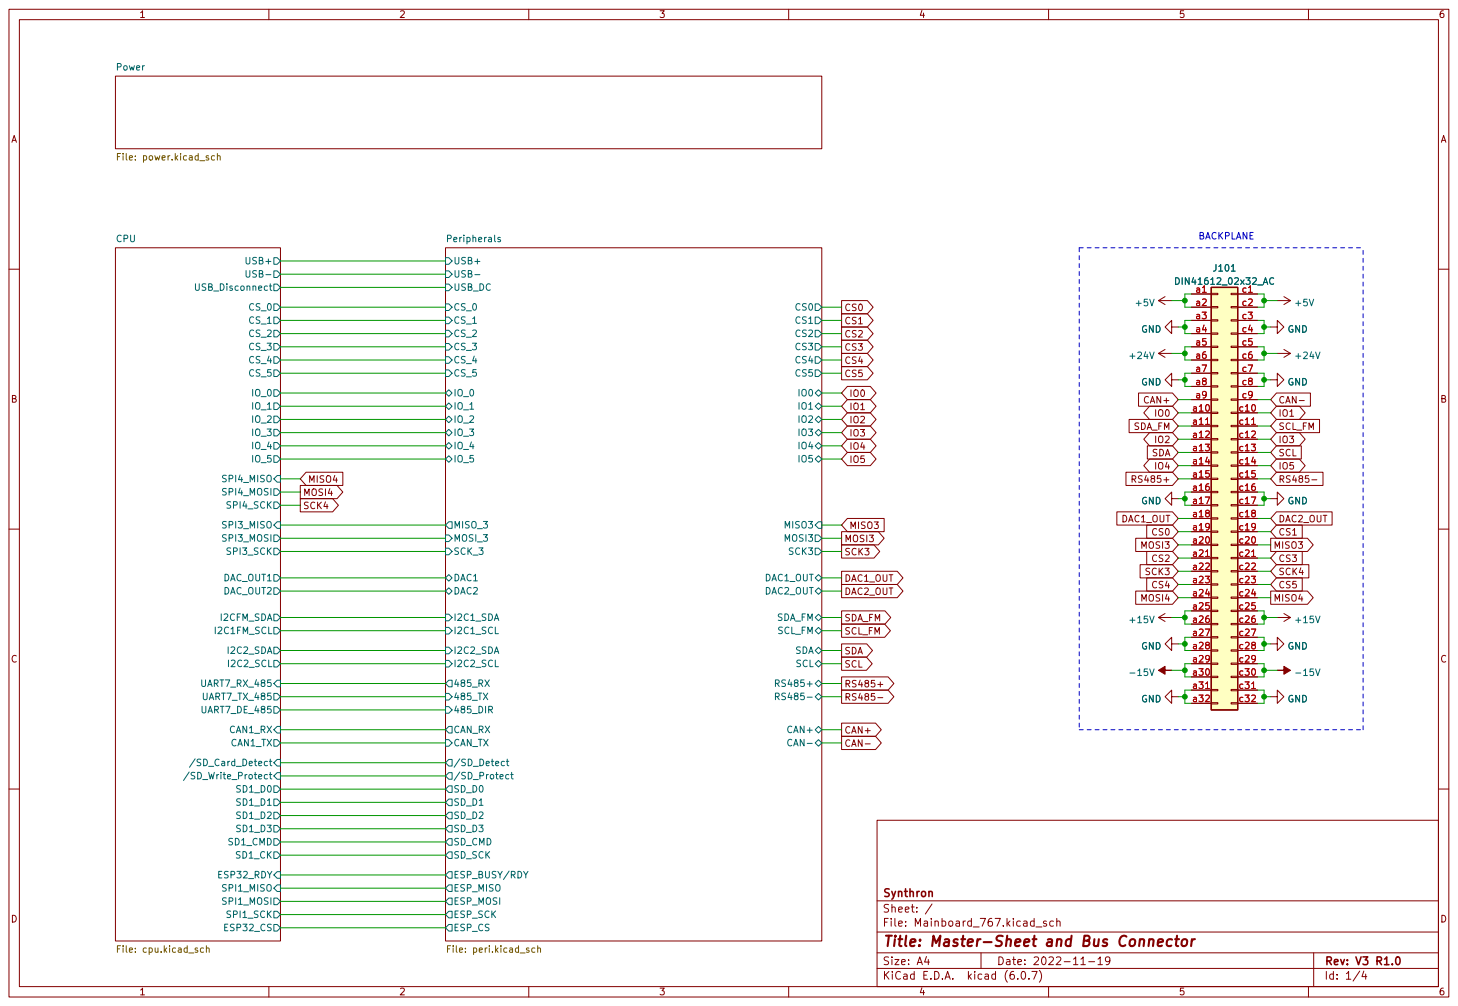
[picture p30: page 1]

Id: 1/4 Title: Master-Sheet and Bus Connector

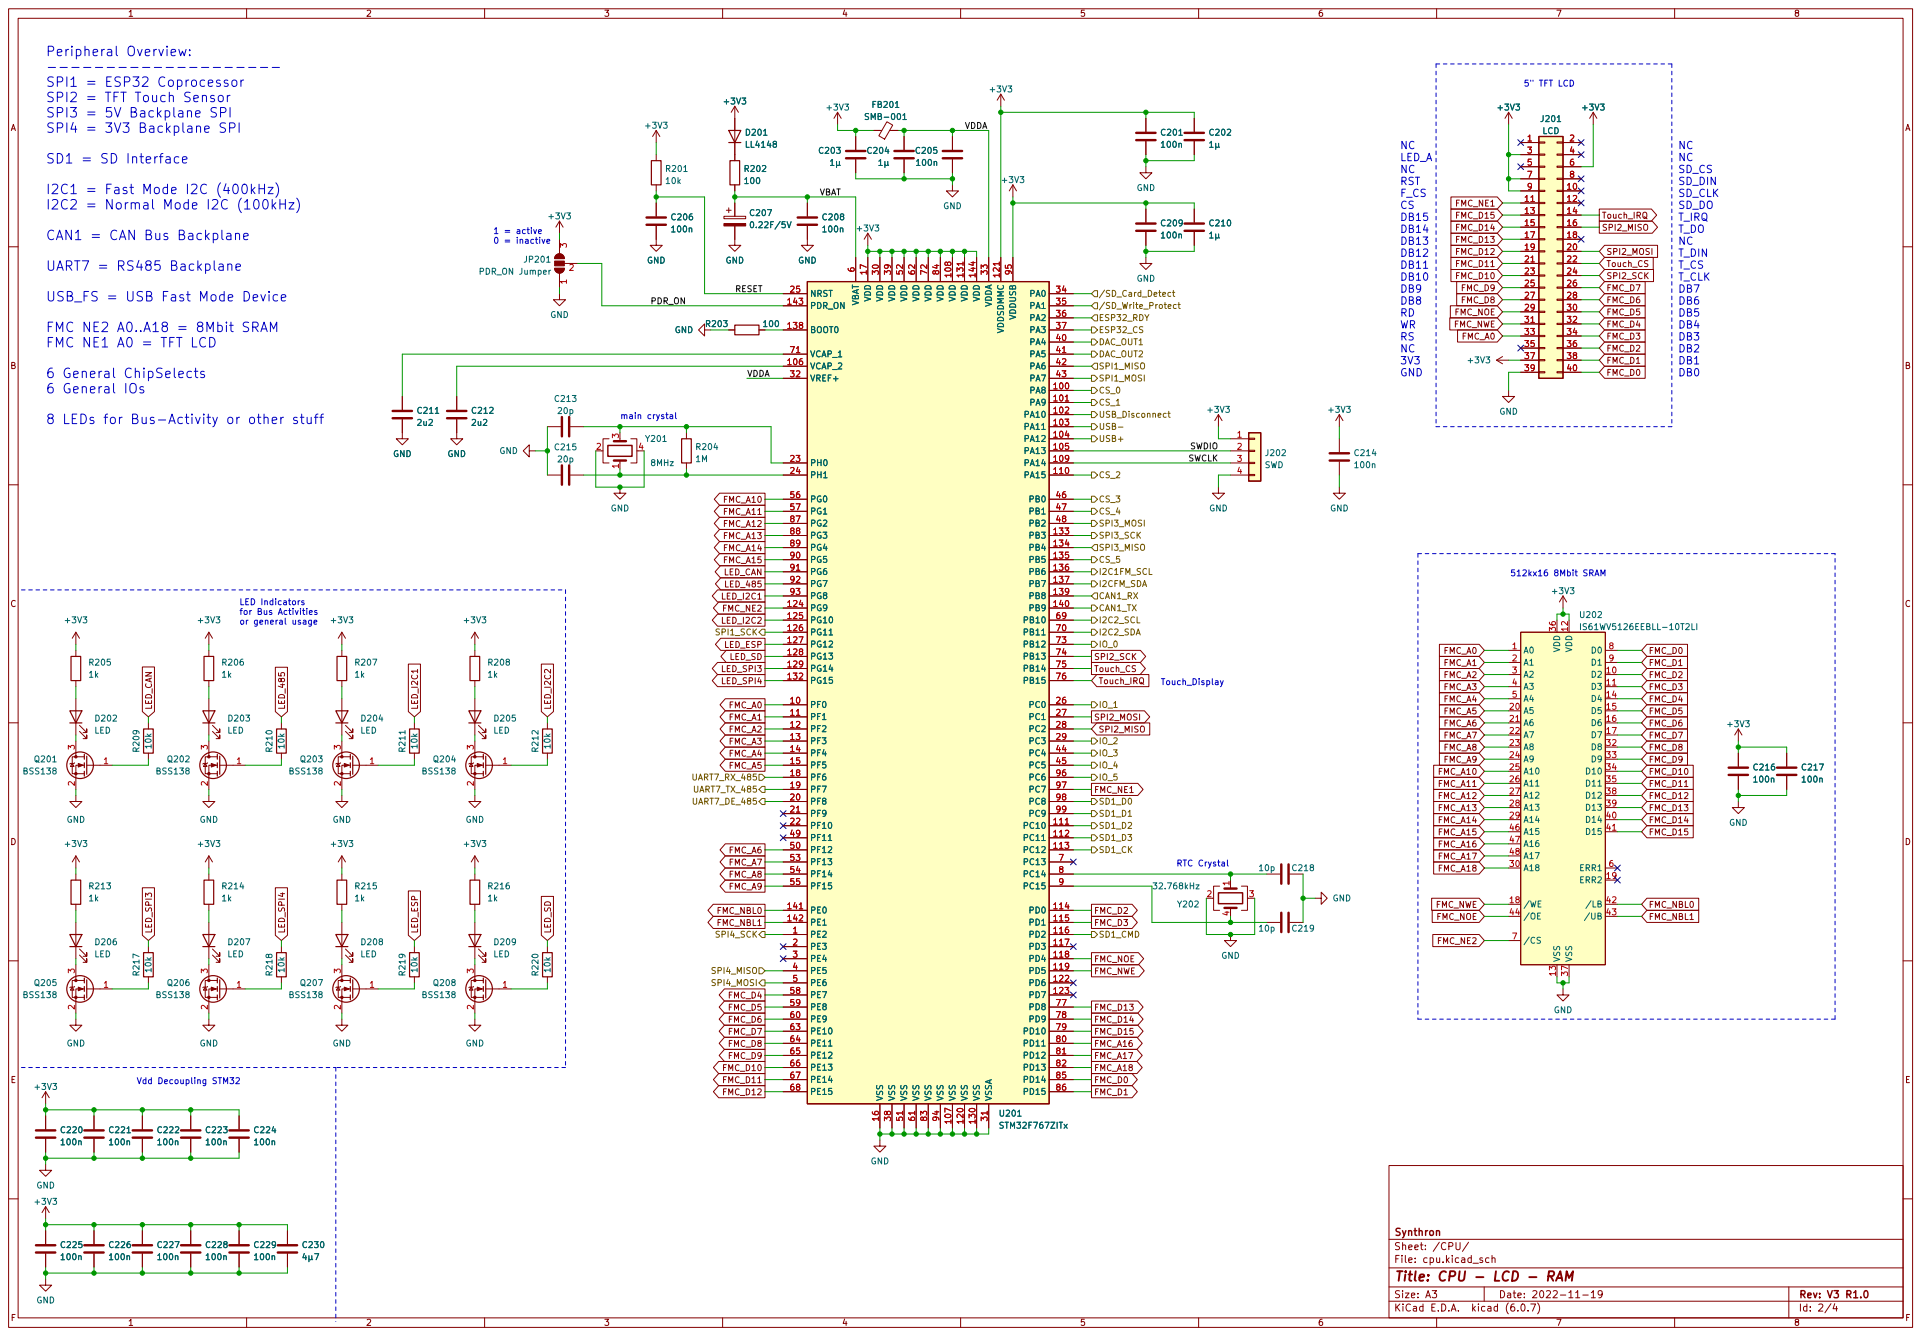
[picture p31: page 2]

USB_FS = USB Fast Mode Device

LED Indicators
for Bus Activities or general usage

File: cpu.kicad_sch Sheet: /CPU/ Synthron

Id: 2/4 Title: CPU - LCD - RAM

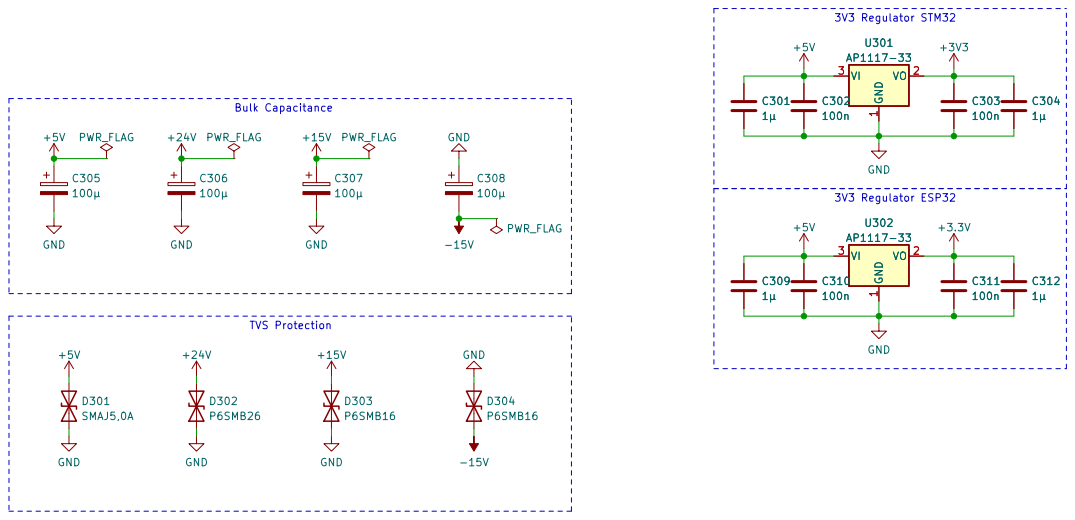
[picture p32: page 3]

1 VO 2 VI 3 U302 AP1117-33 GND GND

Id: 3/4 Title: Power Section


SPI3 Level Shifters DAC Buffering

IO Level Shifters CAN Transceiver and Filter RS485 Transceiver and Filter USB Protection Circuit with Disconnect

Chip Select Level Shifters

2 SCK/CLK 20 SDO/SD0 21 SDI/SD1 22

Synthron
Sheet: /Peripherals/
File: peri.kicad_sch
Id: 4/4 Title: ESP32 - SD - Shifters and Drivers

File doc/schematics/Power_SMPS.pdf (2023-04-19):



File: smps.kicad_sch Sheet: /SMPS/
Id: 2/4 Title:


1 PA0 10 PA1 11 PA2 12 PA3 13 PA4 14 PA5 15 PA6 16 PA7 17 PB0 18 PB1 19 PC13 2 PB2 20 PB10 21 PB11 22 VSS 23 VDD 24 PB12 25 PB13 26 PB14 27 PB15 28 PA8 29 PC14 3 PA9 30 PA10 31 PA11 32 PA12 33 PA13 34 VSS 35 VDD 36 PA14 37 PA15 38 PB3 39 PC15 4 PB4 40 PB5 41 PB6 42 PB7 43 BOOT0 44 PB8 45 PB9 46 VSS 47 VDD 48 PD0 5 PD1 6 NRST 7 VSSA

File: cpu.kicad_sch Sheet: /CPU/ GND


1 VO 2 VI 3 U401 AP1117-33 +5V D402 P6SMB26 +24V D401 SMAJ5,0A GND GND
þÿ1µ PWR_FLAG

File: power.kicad_sch Sheet: /Power/
Id: 4/4 Title:

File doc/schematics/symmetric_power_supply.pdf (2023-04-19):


I_Set+ V_Get+ Positive Channel File: positive.kicad_sch Power File: power.kicad_sch GND


File: positive.kicad_sch Sheet: /Positive Channel/ Synthron C211

Id: 2/6 Title: Positive Voltage Regulation


Synthron
Sheet: /Negative Channel/
File: negative.kicad_sch
Id: 3/6 Title: Negative Voltage Regulation

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

File: cpu.kicad_sch Sheet: /CPU/ Synthron C409

Id: 4/6 Title: CPU and Bus


Bulk Capacitance TVS Protection

File: power.kicad_sch Sheet: /Power/ Synthron

Id: 5/6 Title: Supply Rails


File: filters.kicad_sch Sheet: /Filters/ Synthron

Id: 6/6 Title: PWM Filters


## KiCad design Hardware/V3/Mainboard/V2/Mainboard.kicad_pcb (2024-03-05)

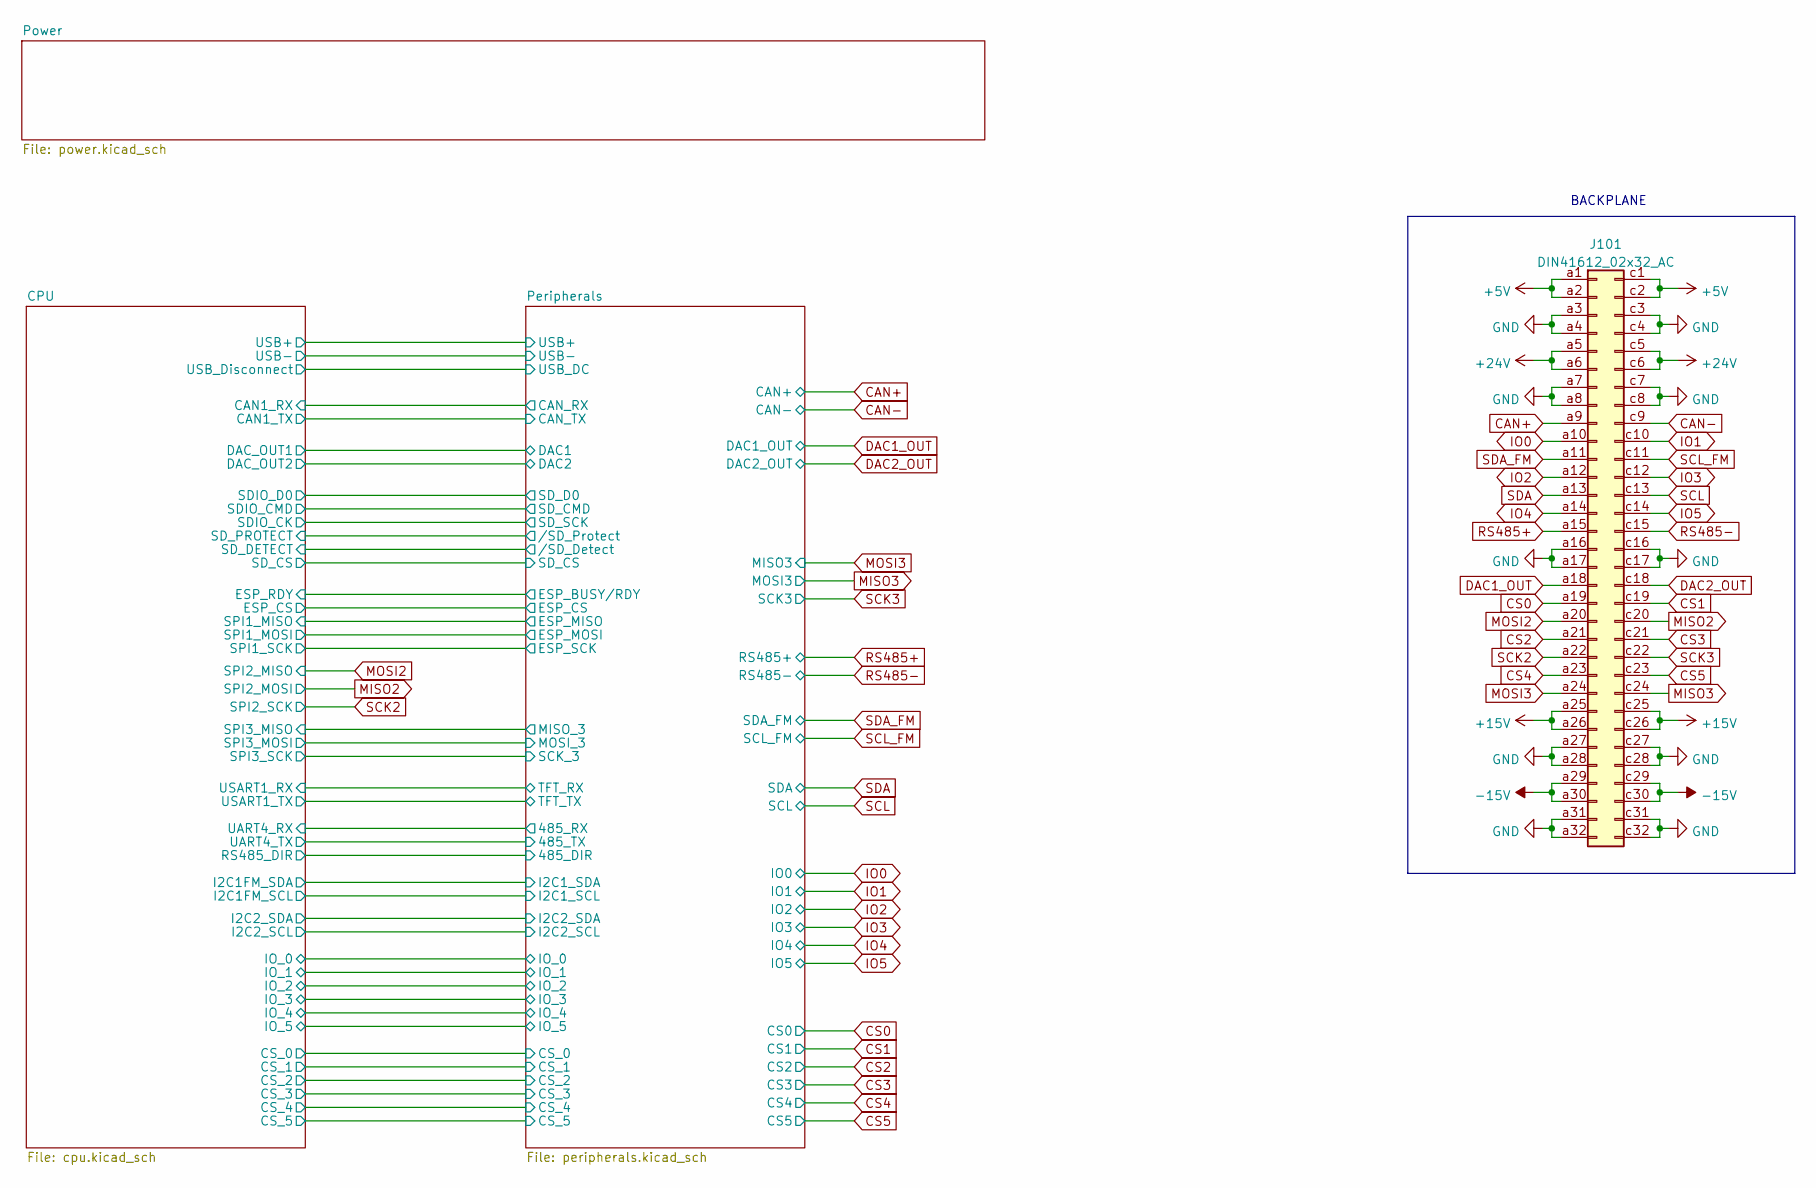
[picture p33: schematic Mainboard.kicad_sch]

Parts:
J101: DIN41612_02x32_AC; VG64_Euro

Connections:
+5V: J101.a1, J101.a2, J101.c1, J101.c2; also elsewhere on the board
+15V: J101.a25, J101.a26, J101.c25, J101.c26; also elsewhere on the board
+24V: J101.a5, J101.a6, J101.c5, J101.c6; also elsewhere on the board
-15V: J101.a29, J101.a30, J101.c29, J101.c30; also elsewhere on the board
CAN+: J101.a9; also elsewhere on the board
CAN-: J101.c9; also elsewhere on the board
CS0: J101.a19; also elsewhere on the board
CS1: J101.c19; also elsewhere on the board
CS2: J101.a21; also elsewhere on the board
CS3: J101.c21; also elsewhere on the board
CS4: J101.a23; also elsewhere on the board
CS5: J101.c23; also elsewhere on the board
DAC1_OUT: J101.a18; also elsewhere on the board
DAC2_OUT: J101.c18; also elsewhere on the board
GND: J101.a3, J101.a4, J101.a7, J101.a8, J101.a16, J101.a17, J101.a27, J101.a28, J101.a31, J101.a32, J101.c3, J101.c4, J101.c7, J101.c8, J101.c16, J101.c17, J101.c27, J101.c28, J101.c31, J101.c32; also elsewhere on the board
IO0: J101.a10; also elsewhere on the board
IO1: J101.c10; also elsewhere on the board
IO2: J101.a12; also elsewhere on the board
IO3: J101.c12; also elsewhere on the board
IO4: J101.a14; also elsewhere on the board
IO5: J101.c14; also elsewhere on the board
MISO2: J101.c20; also elsewhere on the board
MISO3: J101.c24; also elsewhere on the board
MOSI2: J101.a20; also elsewhere on the board
MOSI3: J101.a24; also elsewhere on the board
RS485+: J101.a15; also elsewhere on the board
RS485-: J101.c15; also elsewhere on the board
SCK2: J101.a22; also elsewhere on the board
SCK3: J101.c22; also elsewhere on the board
SCL: J101.c13; also elsewhere on the board
SCL_FM: J101.c11; also elsewhere on the board
SDA: J101.a13; also elsewhere on the board
SDA_FM: J101.a11; also elsewhere on the board

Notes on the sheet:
BACKPLANE

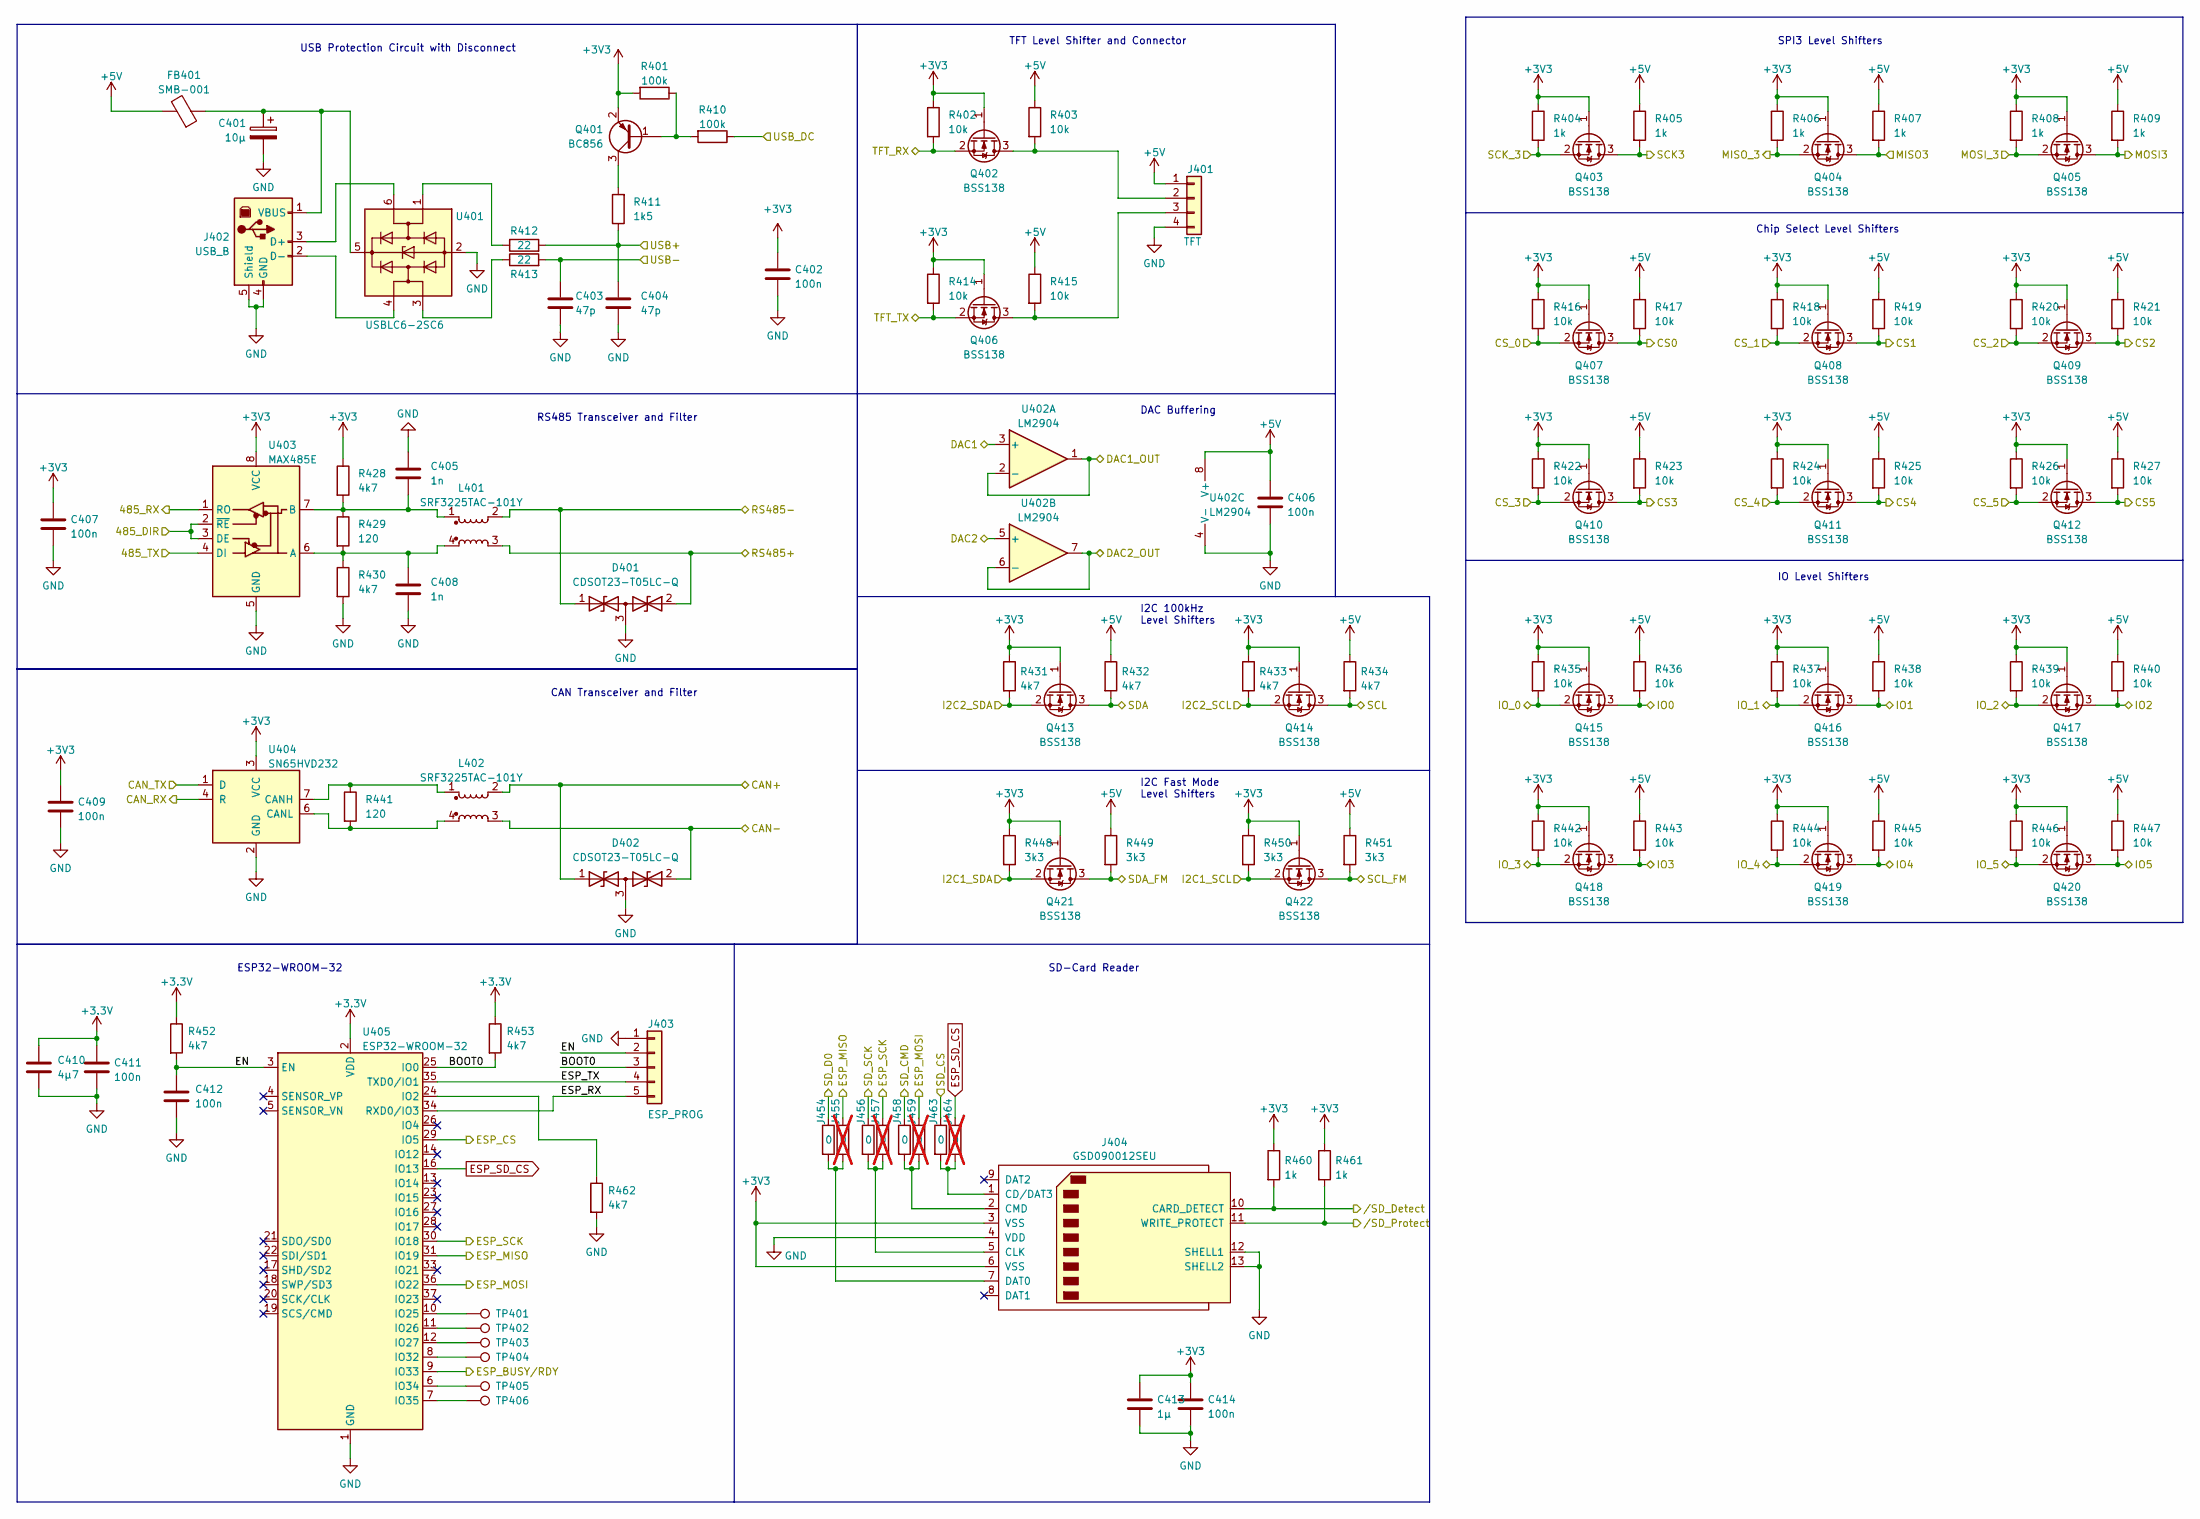
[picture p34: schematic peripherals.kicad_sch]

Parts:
C401: 10µ; CP_Elec_5x5.8
C402, C406, C407, C409, C411, C412, C414: 100n; C_0805_2012Metric
C403, C404: 47p; C_0805_2012Metric
C405, C408: 1n; C_0805_2012Metric
C410: 4µ7; C_0805_2012Metric
C413: 1µ; C_0805_2012Metric
D401, D402: CDSOT23-T05LC-Q; SOT-23
FB401: SMB-001
J401: TFT; JST_XH_B4B-XH-A_1x04_P2.50mm_Vertical
J402: USB_B; USB_B_OST_USB-B1HSxx_Horizontal
J403: ESP_PROG; JST_XH_B5B-XH-A_1x05_P2.50mm_Vertical
J404: GSD090012SEU
J454, J456, J458, J463: 0; SolderJumper-2_P1.3mm_Open_TrianglePad1.0x1.5mm
J455, J457, J459, J464: 0; SolderJumper-2_P1.3mm_Open_TrianglePad1.0x1.5mm; not fitted
L401, L402: SRF3225TAC-101Y; SRF3225TAC
Q401: BC856; SOT-23
Q402, Q403, Q404, Q405, Q406, Q407, Q408, Q409, Q410, Q411, Q412, Q413, Q414, Q415, Q416, Q417, Q418, Q419, Q420, Q421, Q422: BSS138; SOT-23
R401, R410: 100k; R_0805_2012Metric
R402, R403, R414, R415, R416, R417, R418, R419, R420, R421, R422, R423, R424, R425, R426, R427, R435, R436, R437, R438, R439, R440, R442, R443, R444, R445, R446, R447: 10k; R_0805_2012Metric
R404, R405, R406, R407, R408, R409, R460, R461: 1k; R_0805_2012Metric
R411: 1k5; R_0805_2012Metric
R412, R413: 22; R_0805_2012Metric
R428, R430, R431, R432, R433, R434, R452, R453, R462: 4k7; R_0805_2012Metric
R429, R441: 120; R_0805_2012Metric
R448, R449, R450, R451: 3k3; R_0805_2012Metric
TP401, TP402, TP403, TP404, TP405, TP406: TestPoint; TestPoint_Keystone_5000-5004_Miniature
U401: USBLC6-2SC6; SOT-23-6
U402: LM2904; SOIC-8_3.9x4.9mm_P1.27mm
U403: MAX485E; SOIC-8_3.9x4.9mm_P1.27mm
U404: SN65HVD232; SOIC-8_3.9x4.9mm_P1.27mm
U405: ESP32-WROOM-32

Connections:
+3.3V: C410.1, C411.1, R452.1, R453.1, U405.2 (VDD); also elsewhere on the board
+3V3: C402.1, C407.1, C409.1, C413.1, C414.1, J404.3 (VSS), J404.6 (VSS), Q401.2 (E), Q402.1 (G), Q403.1 (G), Q404.1 (G), Q405.1 (G), Q406.1 (G), Q407.1 (G), Q408.1 (G), Q409.1 (G), Q410.1 (G), Q411.1 (G), Q412.1 (G), Q413.1 (G), Q414.1 (G), Q415.1 (G), Q416.1 (G), Q417.1 (G), Q418.1 (G), Q419.1 (G), Q420.1 (G), Q421.1 (G), Q422.1 (G), R401.2, R402.1, R404.1, R406.1, R408.1, R414.1, R416.1, R418.1, R420.1, R422.1, R424.1, R426.1, R428.1, R431.1, R433.1, R435.1, R437.1, R439.1, R442.1, R444.1, R446.1, R448.1, R450.1, R460.1, R461.1, U403.8 (VCC), U404.3 (VCC); also elsewhere on the board
+5V: C406.1, FB401.2, J401.1, R403.1, R405.1, R407.1, R409.1, R415.1, R417.1, R419.1, R421.1, R423.1, R425.1, R427.1, R432.1, R434.1, R436.1, R438.1, R440.1, R443.1, R445.1, R447.1, R449.1, R451.1, U402.8 (V+); also elsewhere on the board
/CPU/CAN1_RX: U404.4 (R); also elsewhere on the board
/CPU/CAN1_TX: U404.1 (D); also elsewhere on the board
/CPU/CS_0: Q407.2 (S), R416.2; also elsewhere on the board
/CPU/CS_1: Q408.2 (S), R418.2; also elsewhere on the board
/CPU/CS_2: Q409.2 (S), R420.2; also elsewhere on the board
/CPU/CS_3: Q410.2 (S), R422.2; also elsewhere on the board
/CPU/CS_4: Q411.2 (S), R424.2; also elsewhere on the board
/CPU/CS_5: Q412.2 (S), R426.2; also elsewhere on the board
/CPU/DAC_OUT1: U402.3 (+); also elsewhere on the board
/CPU/DAC_OUT2: U402.5 (+); also elsewhere on the board
/CPU/ESP_CS: U405.29 (IO5); also elsewhere on the board
/CPU/ESP_RDY: U405.9 (IO33); also elsewhere on the board
/CPU/I2C1FM_SCL: Q422.2 (S), R450.2; also elsewhere on the board
/CPU/I2C1FM_SDA: Q421.2 (S), R448.2; also elsewhere on the board
/CPU/I2C2_SCL: Q414.2 (S), R433.2; also elsewhere on the board
/CPU/I2C2_SDA: Q413.2 (S), R431.2; also elsewhere on the board
/CPU/IO_0: Q415.2 (S), R435.2; also elsewhere on the board
/CPU/IO_1: Q416.2 (S), R437.2; also elsewhere on the board
/CPU/IO_2: Q417.2 (S), R439.2; also elsewhere on the board
/CPU/IO_3: Q418.2 (S), R442.2; also elsewhere on the board
/CPU/IO_4: Q419.2 (S), R444.2; also elsewhere on the board
/CPU/IO_5: Q420.2 (S), R446.2; also elsewhere on the board
/CPU/RS485_DIR: U403.2 (~RE), U403.3 (DE); also elsewhere on the board
/CPU/SDIO_CK: J456.1; also elsewhere on the board
/CPU/SDIO_CMD: J458.1; also elsewhere on the board
/CPU/SDIO_D0: J454.1; also elsewhere on the board
/CPU/SD_CS: J463.1; also elsewhere on the board
/CPU/SD_DETECT: J404.10 (CARD_DETECT), R460.2; also elsewhere on the board
/CPU/SD_PROTECT: J404.11 (WRITE_PROTECT), R461.2; also elsewhere on the board
/CPU/SPI1_MISO: J455.1, U405.31 (IO19); also elsewhere on the board
/CPU/SPI1_MOSI: J459.1, U405.36 (IO22); also elsewhere on the board
/CPU/SPI1_SCK: J457.1, U405.30 (IO18); also elsewhere on the board
/CPU/SPI3_MISO: Q404.2 (S), R406.2; also elsewhere on the board
/CPU/SPI3_MOSI: Q405.2 (S), R408.2; also elsewhere on the board
/CPU/SPI3_SCK: Q403.2 (S), R404.2; also elsewhere on the board
/CPU/UART4_RX: U403.1 (RO); also elsewhere on the board
/CPU/UART4_TX: U403.4 (DI); also elsewhere on the board
/CPU/USART1_RX: Q402.2 (S), R402.2; also elsewhere on the board
/CPU/USART1_TX: Q406.2 (S), R414.2; also elsewhere on the board
/CPU/USB+: C404.1, R411.1, R412.2; also elsewhere on the board
/CPU/USB-: C403.1, R413.2; also elsewhere on the board
/CPU/USB_Disconnect: R410.1; also elsewhere on the board
/Peripherals/BOOT0: J403.3, R453.2, U405.25 (IO0)
/Peripherals/EN: C412.1, J403.2, R452.2, U405.3 (EN)
/Peripherals/ESP_RX: J403.5, U405.34 (RXD0/IO3)
/Peripherals/ESP_TX: J403.4, U405.35 (TXD0/IO1)
CAN+: D402.1 (A1), L402.2; also elsewhere on the board
CAN-: D402.2 (A2), L402.3; also elsewhere on the board
CS0: Q407.3 (D), R417.2; also elsewhere on the board
CS1: Q408.3 (D), R419.2; also elsewhere on the board
CS2: Q409.3 (D), R421.2; also elsewhere on the board
CS3: Q410.3 (D), R423.2; also elsewhere on the board
CS4: Q411.3 (D), R425.2; also elsewhere on the board
CS5: Q412.3 (D), R427.2; also elsewhere on the board
DAC1_OUT: U402.1, U402.2 (-); also elsewhere on the board
DAC2_OUT: U402.6 (-), U402.7; also elsewhere on the board
ESP_SD_CS: J464.1, U405.16 (IO13)
GND: C401.2, C402.2, C403.2, C404.2, C405.1, C406.2, C407.2, C408.2, C409.2, C410.2, C411.2, C412.2, C413.2, C414.2, D401.3 (common), D402.3 (common), J401.4, J402.4 (GND), J402.5 (Shield), J403.1, J404.4 (VDD), J404.12 (SHELL1), J404.13 (SHELL2), R430.2, R462.2, U401.2 (GND), U402.4 (V-), U403.5 (GND), U404.2 (GND), U405.1 (GND), U405.15 (GND), U405.38 (GND), U405.39 (GND); also elsewhere on the board
IO0: Q415.3 (D), R436.2; also elsewhere on the board
IO1: Q416.3 (D), R438.2; also elsewhere on the board
IO2: Q417.3 (D), R440.2; also elsewhere on the board
IO3: Q418.3 (D), R443.2; also elsewhere on the board
IO4: Q419.3 (D), R445.2; also elsewhere on the board
IO5: Q420.3 (D), R447.2; also elsewhere on the board
MISO3: Q405.3 (D), R409.2; also elsewhere on the board
MOSI3: Q404.3 (D), R407.2; also elsewhere on the board
unnamed: J401.2, Q402.3 (D), R403.2
unnamed: J401.3, Q406.3 (D), R415.2
unnamed: J402.3 (D+), U401.6 (I/O1)
unnamed: J402.2 (D-), U401.4 (I/O2)
unnamed: C401.1, FB401.1, J402.1 (VBUS), U401.5 (VBUS)
unnamed: J404.1 (CD/DAT3), J463.2, J464.2
unnamed: J404.5 (CLK), J456.2, J457.2
unnamed: J404.2 (CMD), J458.2, J459.2
unnamed: J404.7 (DAT0), J454.2, J455.2
unnamed: Q401.1 (B), R401.1, R410.2
unnamed: Q401.3 (C), R411.2
unnamed: R412.1, U401.1 (I/O1)
unnamed: R413.1, U401.3 (I/O2)
unnamed: C408.1, L401.4, R429.2, R430.1, U403.6 (A)
unnamed: C405.2, L401.1, R428.2, R429.1, U403.7 (B)
unnamed: L402.1, R441.1, U404.7 (CANH)
unnamed: L402.4, R441.2, U404.6 (CANL)
unnamed: R462.1, U405.24 (IO2)
unnamed: TP401.1, U405.10 (IO25)
unnamed: TP402.1, U405.11 (IO26)
unnamed: TP403.1, U405.12 (IO27)
unnamed: TP404.1, U405.8 (IO32)
unnamed: TP405.1, U405.6 (IO34)
unnamed: TP406.1, U405.7 (IO35)
RS485+: D401.2 (A2), L401.3; also elsewhere on the board
RS485-: D401.1 (A1), L401.2; also elsewhere on the board
SCK3: Q403.3 (D), R405.2; also elsewhere on the board
SCL: Q414.3 (D), R434.2; also elsewhere on the board
SCL_FM: Q422.3 (D), R451.2; also elsewhere on the board
SDA: Q413.3 (D), R432.2; also elsewhere on the board
SDA_FM: Q421.3 (D), R449.2; also elsewhere on the board

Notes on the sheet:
DAC Buffering
ESP32-WROOM-32
SPI3 Level Shifters
USB Protection Circuit with Disconnect
I2C Fast Mode Level Shifters
I2C 100kHz Level Shifters
RS485 Transceiver and Filter
SD-Card Reader
CAN Transceiver and Filter
IO Level Shifters
Chip Select Level Shifters
TFT Level Shifter and Connector

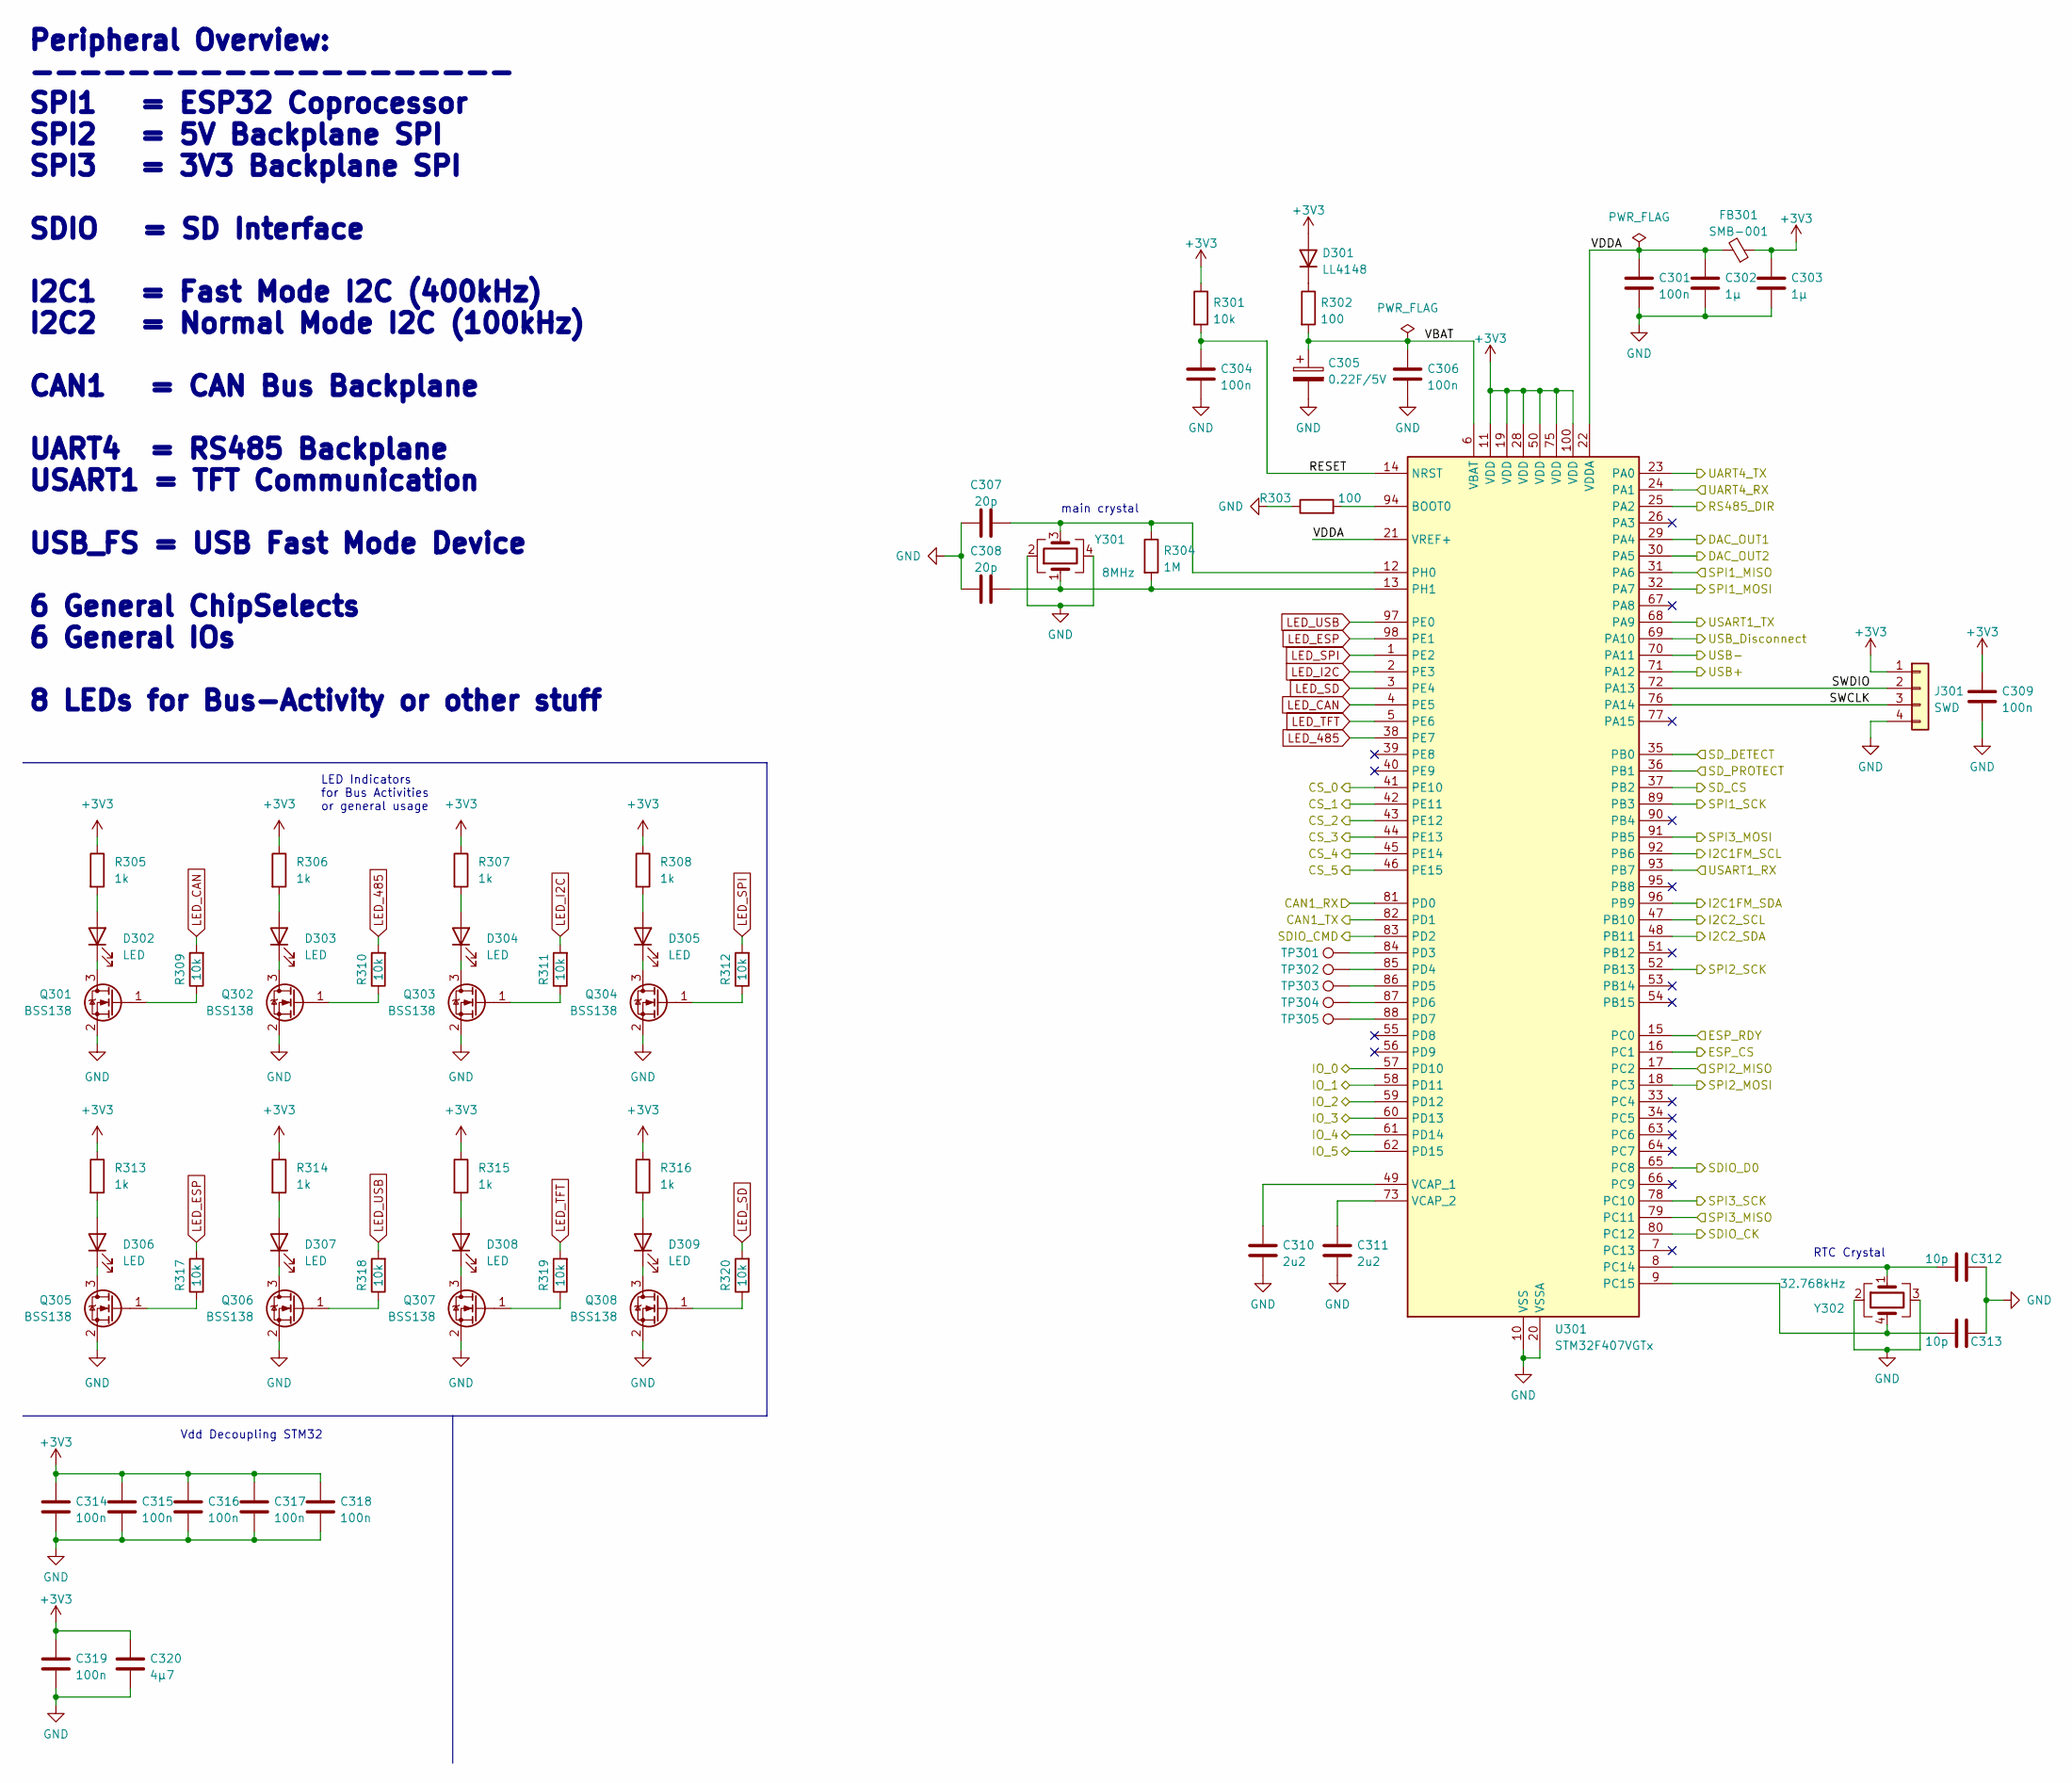
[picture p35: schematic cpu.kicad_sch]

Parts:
C301, C304, C306, C309, C314, C315, C316, C317, C318, C319: 100n; C_0805_2012Metric
C302, C303: 1µ; C_0805_2012Metric
C305: 0.22F/5V; CP_Elec_10x10.5
C307, C308: 20p; C_0805_2012Metric
C310, C311: 2u2; C_0805_2012Metric
C312, C313: 10p; C_0805_2012Metric
C320: 4µ7; C_0805_2012Metric
D301: LL4148; D_MiniMELF
D302, D303, D304, D305, D306, D307, D308, D309: LED; LED_D3.0mm
FB301: SMB-001
J301: SWD; JST_XH_B4B-XH-A_1x04_P2.50mm_Vertical
Q301, Q302, Q303, Q304, Q305, Q306, Q307, Q308: BSS138; SOT-23
R301, R309, R310, R311, R312, R317, R318, R319, R320: 10k; R_0805_2012Metric
R302, R303: 100; R_0805_2012Metric
R304: 1M; R_0805_2012Metric
R305, R306, R307, R308, R313, R314, R315, R316: 1k; R_0805_2012Metric
TP301, TP302, TP303, TP304, TP305: TestPoint; TestPoint_Keystone_5000-5004_Miniature
U301: STM32F407VGTx; LQFP-100_14x14mm_P0.5mm
Y301: 8MHz; Crystal_SMD_5032-4Pin_5.0x3.2mm
Y302: 32.768kHz; Crystal_SMD_SeikoEpson_MC306-4Pin_8.0x3.2mm

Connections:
+3V3: C303.1, C309.1, C314.1, C315.1, C316.1, C317.1, C318.1, C319.1, C320.1, D301.2 (A), FB301.1, J301.1, R301.1, R305.1, R306.1, R307.1, R308.1, R313.1, R314.1, R315.1, R316.1, U301.11 (VDD), U301.19 (VDD), U301.28 (VDD), U301.50 (VDD), U301.75 (VDD), U301.100 (VDD); also elsewhere on the board
/CPU/CAN1_RX: U301.81 (PD0); also elsewhere on the board
/CPU/CAN1_TX: U301.82 (PD1); also elsewhere on the board
/CPU/CS_0: U301.41 (PE10); also elsewhere on the board
/CPU/CS_1: U301.42 (PE11); also elsewhere on the board
/CPU/CS_2: U301.43 (PE12); also elsewhere on the board
/CPU/CS_3: U301.44 (PE13); also elsewhere on the board
/CPU/CS_4: U301.45 (PE14); also elsewhere on the board
/CPU/CS_5: U301.46 (PE15); also elsewhere on the board
/CPU/DAC_OUT1: U301.29 (PA4); also elsewhere on the board
/CPU/DAC_OUT2: U301.30 (PA5); also elsewhere on the board
/CPU/ESP_CS: U301.16 (PC1); also elsewhere on the board
/CPU/ESP_RDY: U301.15 (PC0); also elsewhere on the board
/CPU/I2C1FM_SCL: U301.92 (PB6); also elsewhere on the board
/CPU/I2C1FM_SDA: U301.96 (PB9); also elsewhere on the board
/CPU/I2C2_SCL: U301.47 (PB10); also elsewhere on the board
/CPU/I2C2_SDA: U301.48 (PB11); also elsewhere on the board
/CPU/IO_0: U301.57 (PD10); also elsewhere on the board
/CPU/IO_1: U301.58 (PD11); also elsewhere on the board
/CPU/IO_2: U301.59 (PD12); also elsewhere on the board
/CPU/IO_3: U301.60 (PD13); also elsewhere on the board
/CPU/IO_4: U301.61 (PD14); also elsewhere on the board
/CPU/IO_5: U301.62 (PD15); also elsewhere on the board
/CPU/RESET: C304.1, R301.2, U301.14 (NRST)
/CPU/RS485_DIR: U301.25 (PA2); also elsewhere on the board
/CPU/SDIO_CK: U301.80 (PC12); also elsewhere on the board
/CPU/SDIO_CMD: U301.83 (PD2); also elsewhere on the board
/CPU/SDIO_D0: U301.65 (PC8); also elsewhere on the board
/CPU/SD_CS: U301.37 (PB2); also elsewhere on the board
/CPU/SD_DETECT: U301.35 (PB0); also elsewhere on the board
/CPU/SD_PROTECT: U301.36 (PB1); also elsewhere on the board
/CPU/SPI1_MISO: U301.31 (PA6); also elsewhere on the board
/CPU/SPI1_MOSI: U301.32 (PA7); also elsewhere on the board
/CPU/SPI1_SCK: U301.89 (PB3); also elsewhere on the board
/CPU/SPI3_MISO: U301.79 (PC11); also elsewhere on the board
/CPU/SPI3_MOSI: U301.91 (PB5); also elsewhere on the board
/CPU/SPI3_SCK: U301.78 (PC10); also elsewhere on the board
/CPU/SWCLK: J301.3, U301.76 (PA14)
/CPU/SWDIO: J301.2, U301.72 (PA13)
/CPU/UART4_RX: U301.24 (PA1); also elsewhere on the board
/CPU/UART4_TX: U301.23 (PA0); also elsewhere on the board
/CPU/USART1_RX: U301.93 (PB7); also elsewhere on the board
/CPU/USART1_TX: U301.68 (PA9); also elsewhere on the board
/CPU/USB+: U301.71 (PA12); also elsewhere on the board
/CPU/USB-: U301.70 (PA11); also elsewhere on the board
/CPU/USB_Disconnect: U301.69 (PA10); also elsewhere on the board
/CPU/VBAT: C305.1, C306.1, R302.2, U301.6 (VBAT)
/CPU/VDDA: C301.1, C302.1, FB301.2, U301.21 (VREF+), U301.22 (VDDA)
GND: C301.2, C302.2, C303.2, C304.2, C305.2, C306.2, C307.1, C308.1, C309.2, C310.2, C311.2, C312.1, C313.1, C314.2, C315.2, C316.2, C317.2, C318.2, C319.2, C320.2, J301.4, Q301.2 (S), Q302.2 (S), Q303.2 (S), Q304.2 (S), Q305.2 (S), Q306.2 (S), Q307.2 (S), Q308.2 (S), R303.1, U301.10 (VSS), U301.20 (VSSA), U301.27 (VSS), U301.74 (VSS), U301.99 (VSS), Y301.2, Y301.4, Y302.2, Y302.3; also elsewhere on the board
LED_485: R310.2, U301.38 (PE7)
LED_CAN: R309.2, U301.4 (PE5)
LED_ESP: R317.2, U301.98 (PE1)
LED_I2C: R311.2, U301.2 (PE3)
LED_SD: R320.2, U301.3 (PE4)
LED_SPI: R312.2, U301.1 (PE2)
LED_TFT: R319.2, U301.5 (PE6)
LED_USB: R318.2, U301.97 (PE0)
MISO2: U301.18 (PC3); also elsewhere on the board
MOSI2: U301.17 (PC2); also elsewhere on the board
unnamed: D301.1 (K), R302.1
unnamed: D302.2 (A), R305.2
unnamed: D302.1 (K), Q301.3 (D)
unnamed: D303.2 (A), R306.2
unnamed: D303.1 (K), Q302.3 (D)
unnamed: D304.2 (A), R307.2
unnamed: D304.1 (K), Q303.3 (D)
unnamed: D305.2 (A), R308.2
unnamed: D305.1 (K), Q304.3 (D)
unnamed: D306.2 (A), R313.2
unnamed: D306.1 (K), Q305.3 (D)
unnamed: D307.2 (A), R314.2
unnamed: D307.1 (K), Q306.3 (D)
unnamed: D308.2 (A), R315.2
unnamed: D308.1 (K), Q307.3 (D)
unnamed: D309.2 (A), R316.2
unnamed: D309.1 (K), Q308.3 (D)
unnamed: Q301.1 (G), R309.1
unnamed: Q302.1 (G), R310.1
unnamed: Q303.1 (G), R311.1
unnamed: Q304.1 (G), R312.1
unnamed: Q305.1 (G), R317.1
unnamed: Q306.1 (G), R318.1
unnamed: Q307.1 (G), R319.1
unnamed: Q308.1 (G), R320.1
unnamed: R303.2, U301.94 (BOOT0)
unnamed: C312.2, U301.8 (PC14), Y302.1
unnamed: C313.2, U301.9 (PC15), Y302.4
unnamed: TP301.1, U301.84 (PD3)
unnamed: TP302.1, U301.85 (PD4)
unnamed: TP303.1, U301.86 (PD5)
unnamed: TP304.1, U301.87 (PD6)
unnamed: TP305.1, U301.88 (PD7)
unnamed: C307.2, R304.1, U301.12 (PH0), Y301.3
unnamed: C308.2, R304.2, U301.13 (PH1), Y301.1
unnamed: C310.1, U301.49 (VCAP_1)
unnamed: C311.1, U301.73 (VCAP_2)
SCK2: U301.52 (PB13); also elsewhere on the board

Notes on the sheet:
LED Indicators for Bus Activities or general usage
main crystal
Peripheral Overview: -------------------- SPI1 = ESP32 Coprocessor SPI2 = 5V Backplane SPI SPI3 = 3V3 Backplane SPI SDIO = SD Interface I2C1 = Fast Mode I2C (400kHz) I2C2 = Normal Mode I2C (100kHz) CAN1 = CAN Bus Backplane UART4 = RS485 Backplane USART1 = TFT Communication USB_FS = USB Fast Mode De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
RTC Crystal
Vdd Decoupling STM32

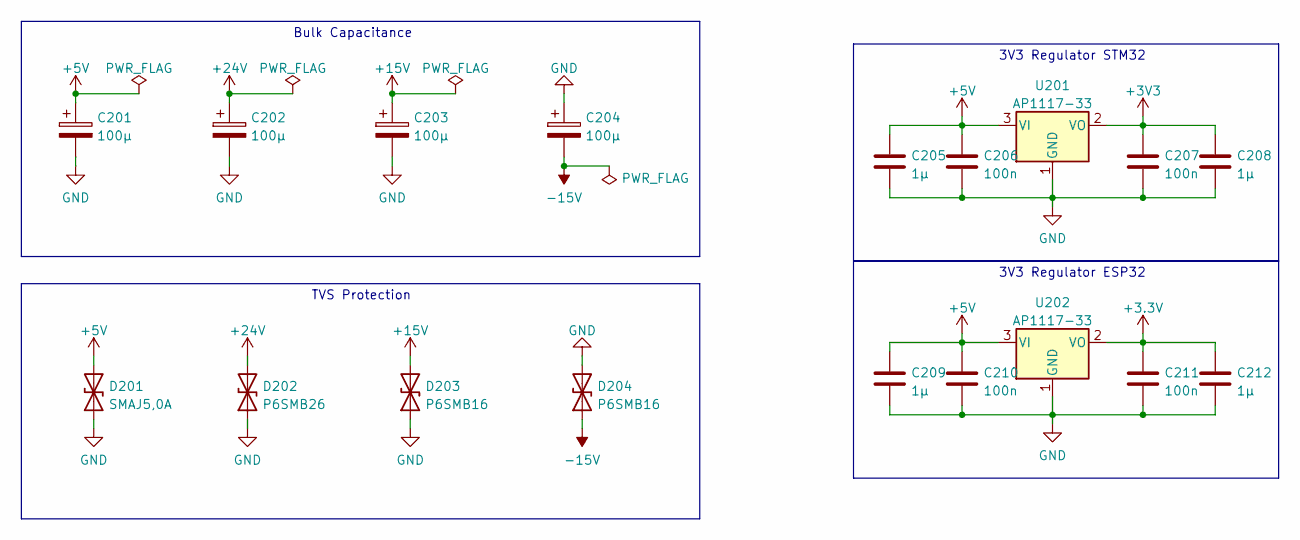
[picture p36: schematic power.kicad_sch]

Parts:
C201, C202, C203, C204: 100µ; CP_Radial_D8.0mm_P5.00mm
C205, C208, C209, C212: 1µ; C_0805_2012Metric
C206, C207, C210, C211: 100n; C_0805_2012Metric
D201: SMAJ5,0A; D_SMA
D202: P6SMB26; D_SMA
D203, D204: P6SMB16; D_SMA
U201, U202: AP1117-33; SOT-223-3_TabPin2

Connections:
+3.3V: C211.1, C212.1, U202.2 (VO); also elsewhere on the board
+3V3: C207.1, C208.1, U201.2 (VO); also elsewhere on the board
+5V: C201.1, C205.1, C206.1, C209.1, C210.1, D201.2 (A2), U201.3 (VI), U202.3 (VI); also elsewhere on the board
+15V: C203.1, D203.2 (A2); also elsewhere on the board
+24V: C202.1, D202.2 (A2); also elsewhere on the board
-15V: C204.2, D204.1 (A1); also elsewhere on the board
GND: C201.2, C202.2, C203.2, C204.1, C205.2, C206.2, C207.2, C208.2, C209.2, C210.2, C211.2, C212.2, D201.1 (A1), D202.1 (A1), D203.1 (A1), D204.2 (A2), U201.1 (GND), U202.1 (GND); also elsewhere on the board

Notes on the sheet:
3V3 Regulator STM32
3V3 Regulator ESP32
Bulk Capacitance
TVS Protection

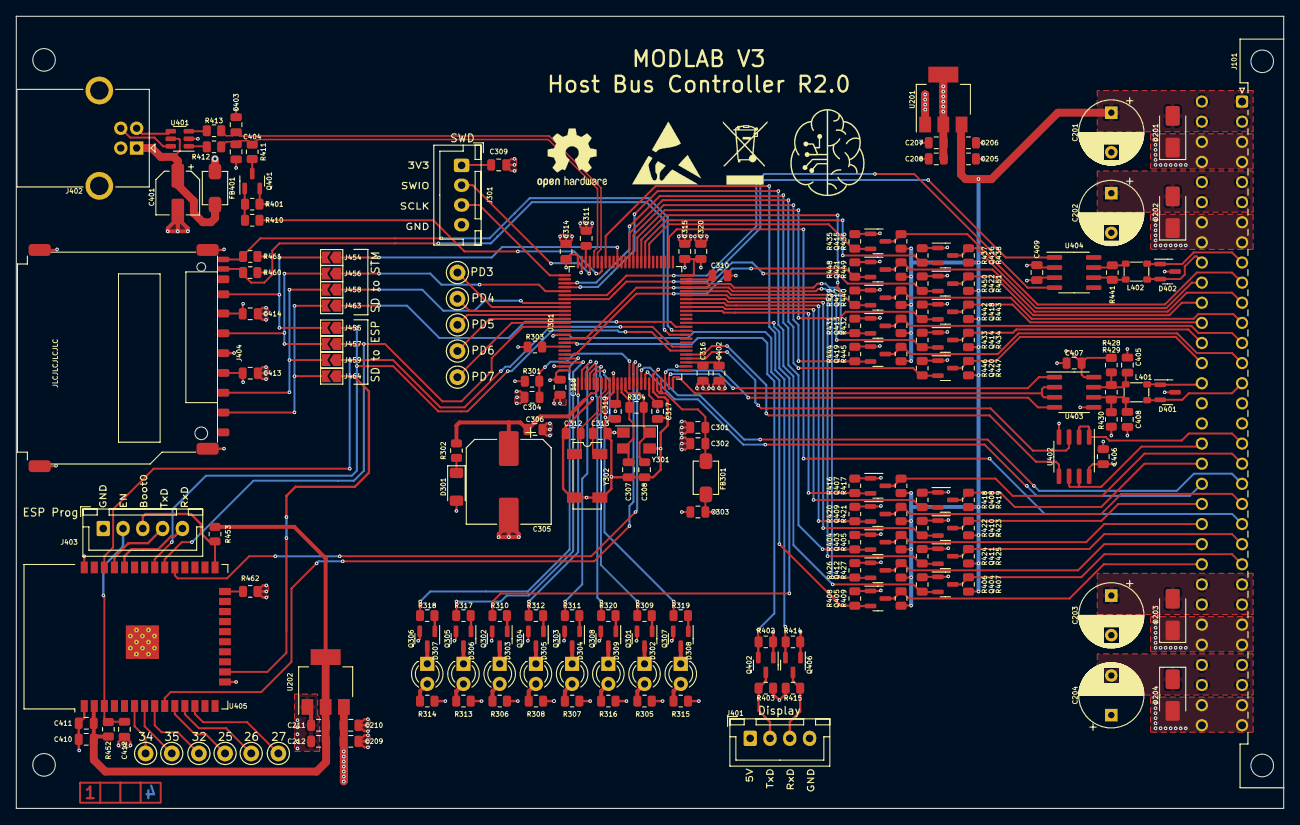
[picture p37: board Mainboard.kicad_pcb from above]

Board: 4 copper layers, 160.0 x 100.0 mm, 207 parts (0 on the bottom side), 156 nets.

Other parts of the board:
Ref**: Val**; ladder_4

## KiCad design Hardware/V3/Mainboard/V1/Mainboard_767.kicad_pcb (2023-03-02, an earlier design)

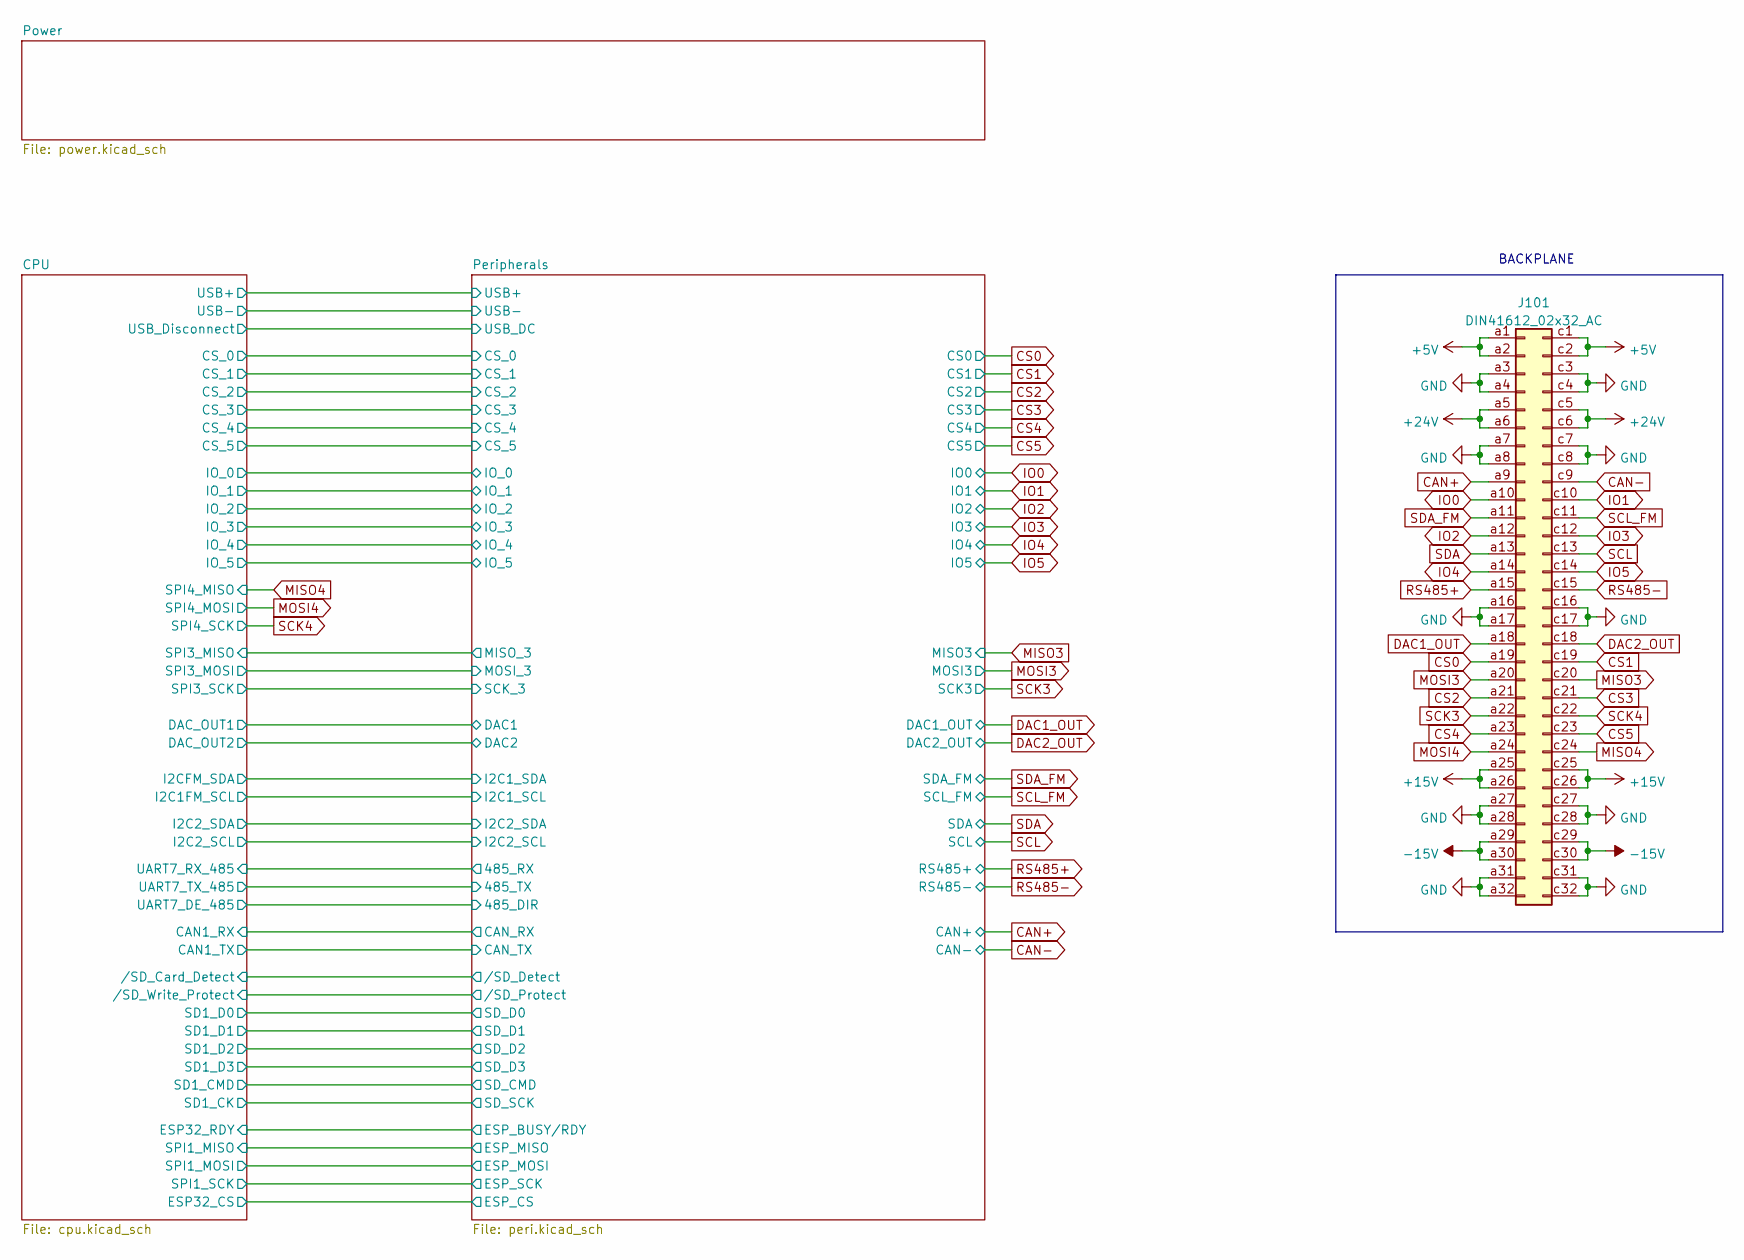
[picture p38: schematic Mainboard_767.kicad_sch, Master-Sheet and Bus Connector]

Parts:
J101: DIN41612_02x32_AC; VG64_Euro

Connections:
+5V: J101.a1, J101.a2, J101.c1, J101.c2; also elsewhere on the board
+15V: J101.a25, J101.a26, J101.c25, J101.c26; also elsewhere on the board
+24V: J101.a5, J101.a6, J101.c5, J101.c6; also elsewhere on the board
-15V: J101.a29, J101.a30, J101.c29, J101.c30; also elsewhere on the board
CAN+: J101.a9; also elsewhere on the board
CAN-: J101.c9; also elsewhere on the board
CS0: J101.a19; also elsewhere on the board
CS1: J101.c19; also elsewhere on the board
CS2: J101.a21; also elsewhere on the board
CS3: J101.c21; also elsewhere on the board
CS4: J101.a23; also elsewhere on the board
CS5: J101.c23; also elsewhere on the board
DAC1_OUT: J101.a18; also elsewhere on the board
DAC2_OUT: J101.c18; also elsewhere on the board
GND: J101.a3, J101.a4, J101.a7, J101.a8, J101.a16, J101.a17, J101.a27, J101.a28, J101.a31, J101.a32, J101.c3, J101.c4, J101.c7, J101.c8, J101.c16, J101.c17, J101.c27, J101.c28, J101.c31, J101.c32; also elsewhere on the board
IO0: J101.a10; also elsewhere on the board
IO1: J101.c10; also elsewhere on the board
IO2: J101.a12; also elsewhere on the board
IO3: J101.c12; also elsewhere on the board
IO4: J101.a14; also elsewhere on the board
IO5: J101.c14; also elsewhere on the board
MISO3: J101.c20; also elsewhere on the board
MISO4: J101.c24; also elsewhere on the board
MOSI3: J101.a20; also elsewhere on the board
MOSI4: J101.a24; also elsewhere on the board
RS485+: J101.a15; also elsewhere on the board
RS485-: J101.c15; also elsewhere on the board
SCK3: J101.a22; also elsewhere on the board
SCK4: J101.c22; also elsewhere on the board
SCL: J101.c13; also elsewhere on the board
SCL_FM: J101.c11; also elsewhere on the board
SDA: J101.a13; also elsewhere on the board
SDA_FM: J101.a11; also elsewhere on the board

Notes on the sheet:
BACKPLANE

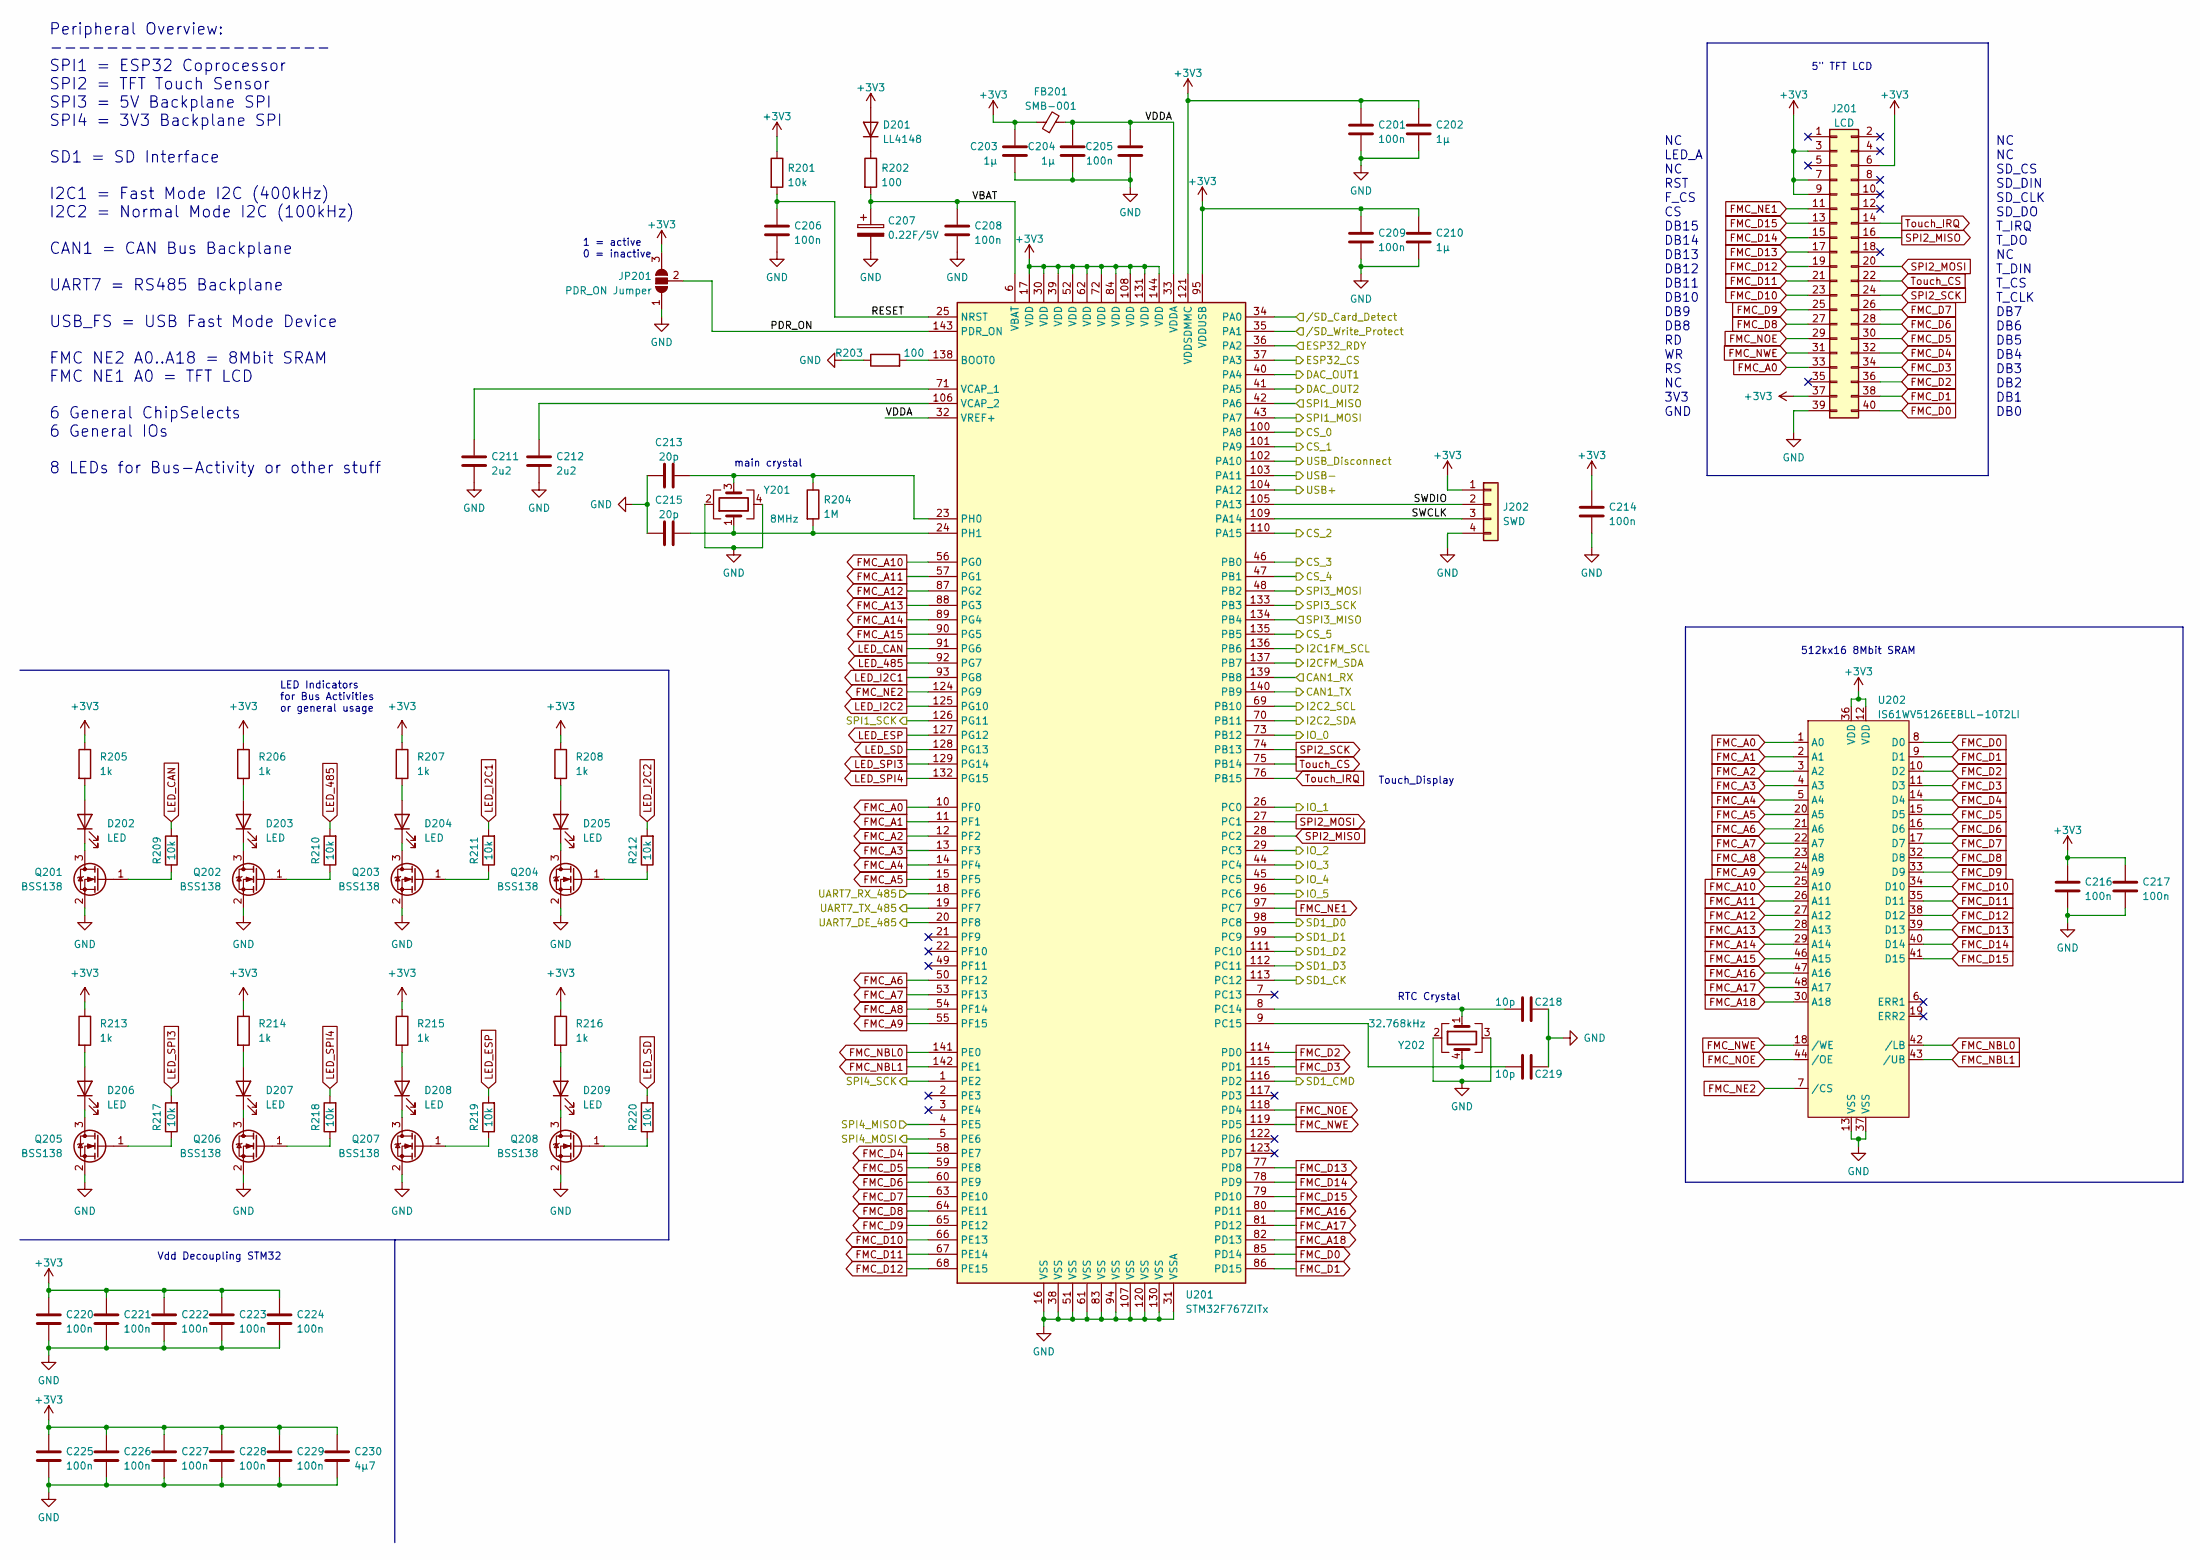
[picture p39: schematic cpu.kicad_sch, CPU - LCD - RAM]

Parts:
C201, C205, C206, C208, C209, C214, C216, C217, C220, C221, C222, C223, C224, C225, C226, C227, C228, C229: 100n; C_0805_2012Metric
C202, C203, C204, C210: 1µ; C_0805_2012Metric
C207: 0.22F/5V; CP_Elec_10x10.5
C211, C212: 2u2; C_0805_2012Metric
C213, C215: 20p; C_0805_2012Metric
C218, C219: 10p; C_0805_2012Metric
C230: 4µ7; C_0805_2012Metric
D201: LL4148; D_MiniMELF
D202, D203, D204, D205, D206, D207, D208, D209: LED; LED_D3.0mm
FB201: SMB-001
J201: LCD; PinHeader_2x20_P2.54mm_Vertical
J202: SWD; JST_XH_B4B-XH-A_1x04_P2.50mm_Vertical
JP201: PDR_ON Jumper; SolderJumper-3_P1.3mm_Open_RoundedPad1.0x1.5mm_NumberLabels
Q201, Q202, Q203, Q204, Q205, Q206, Q207, Q208: BSS138; SOT-23
R201, R209, R210, R211, R212, R217, R218, R219, R220: 10k; R_0805_2012Metric
R202, R203: 100; R_0805_2012Metric
R204: 1M; R_0805_2012Metric
R205, R206, R207, R208, R213, R214, R215, R216: 1k; R_0805_2012Metric
U201: STM32F767ZITx; LQFP-144_20x20mm_P0.5mm
U202: IS61WV5126EEBLL-10T2LI; TSOP-I-48_18.4x12mm_P0.5mm
Y201: 8MHz; Crystal_SMD_5032-4Pin_5.0x3.2mm
Y202: 32.768kHz; Crystal_SMD_SeikoEpson_MC306-4Pin_8.0x3.2mm

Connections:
+3V3: C201.1, C202.1, C203.1, C209.1, C210.1, C214.1, C216.1, C217.1, C220.1, C221.1, C222.1, C223.1, C224.1, C225.1, C226.1, C227.1, C228.1, C229.1, C230.1, D201.2 (A), FB201.1, J201.3, J201.6, J201.7, J201.9, J201.37, J202.1, JP201.3 (B), R201.1, R205.1, R206.1, R207.1, R208.1, R213.1, R214.1, R215.1, R216.1, U201.17 (VDD), U201.30 (VDD), U201.39 (VDD), U201.52 (VDD), U201.62 (VDD), U201.72 (VDD), U201.84 (VDD), U201.95 (VDDUSB), U201.108 (VDD), U201.121 (VDDSDMMC), U201.131 (VDD), U201.144 (VDD), U202.12 (VDD), U202.36 (VDD); also elsewhere on the board
/CPU/CAN1_RX: U201.139 (PB8); also elsewhere on the board
/CPU/CAN1_TX: U201.140 (PB9); also elsewhere on the board
/CPU/CS_0: U201.100 (PA8); also elsewhere on the board
/CPU/CS_1: U201.101 (PA9); also elsewhere on the board
/CPU/CS_2: U201.110 (PA15); also elsewhere on the board
/CPU/CS_3: U201.46 (PB0); also elsewhere on the board
/CPU/CS_4: U201.47 (PB1); also elsewhere on the board
/CPU/CS_5: U201.135 (PB5); also elsewhere on the board
/CPU/DAC_OUT1: U201.40 (PA4); also elsewhere on the board
/CPU/DAC_OUT2: U201.41 (PA5); also elsewhere on the board
/CPU/ESP32_CS: U201.37 (PA3); also elsewhere on the board
/CPU/ESP32_RDY: U201.36 (PA2); also elsewhere on the board
/CPU/I2C1FM_SCL: U201.136 (PB6); also elsewhere on the board
/CPU/I2C2_SCL: U201.69 (PB10); also elsewhere on the board
/CPU/I2C2_SDA: U201.70 (PB11); also elsewhere on the board
/CPU/I2CFM_SDA: U201.137 (PB7); also elsewhere on the board
/CPU/IO_0: U201.73 (PB12); also elsewhere on the board
/CPU/IO_1: U201.26 (PC0); also elsewhere on the board
/CPU/IO_2: U201.29 (PC3); also elsewhere on the board
/CPU/IO_3: U201.44 (PC4); also elsewhere on the board
/CPU/IO_4: U201.45 (PC5); also elsewhere on the board
/CPU/IO_5: U201.96 (PC6); also elsewhere on the board
/CPU/PDR_ON: JP201.2 (C), U201.143 (PDR_ON)
/CPU/RESET: C206.1, R201.2, U201.25 (NRST)
/CPU/SD1_CK: U201.113 (PC12); also elsewhere on the board
/CPU/SD1_CMD: U201.116 (PD2); also elsewhere on the board
/CPU/SD1_D0: U201.98 (PC8); also elsewhere on the board
/CPU/SD1_D1: U201.99 (PC9); also elsewhere on the board
/CPU/SD1_D2: U201.111 (PC10); also elsewhere on the board
/CPU/SD1_D3: U201.112 (PC11); also elsewhere on the board
/CPU/SPI1_MISO: U201.42 (PA6); also elsewhere on the board
/CPU/SPI1_MOSI: U201.43 (PA7); also elsewhere on the board
/CPU/SPI1_SCK: U201.126 (PG11); also elsewhere on the board
/CPU/SPI3_MISO: U201.134 (PB4); also elsewhere on the board
/CPU/SPI3_MOSI: U201.48 (PB2); also elsewhere on the board
/CPU/SPI3_SCK: U201.133 (PB3); also elsewhere on the board
/CPU/SWCLK: J202.3, U201.109 (PA14)
/CPU/SWDIO: J202.2, U201.105 (PA13)
/CPU/UART7_DE_485: U201.20 (PF8); also elsewhere on the board
/CPU/UART7_RX_485: U201.18 (PF6); also elsewhere on the board
/CPU/UART7_TX_485: U201.19 (PF7); also elsewhere on the board
/CPU/USB+: U201.104 (PA12); also elsewhere on the board
/CPU/USB-: U201.103 (PA11); also elsewhere on the board
/CPU/USB_Disconnect: U201.102 (PA10); also elsewhere on the board
/CPU/VBAT: C207.1, C208.1, R202.2, U201.6 (VBAT)
/CPU/VDDA: C204.1, C205.1, FB201.2, U201.32 (VREF+), U201.33 (VDDA)
/CPU//SD_Card_Detect: U201.34 (PA0); also elsewhere on the board
/CPU//SD_Write_Protect: U201.35 (PA1); also elsewhere on the board
FMC_A0: J201.33, U201.10 (PF0), U202.1 (A0)
FMC_A1: U201.11 (PF1), U202.2 (A1)
FMC_A2: U201.12 (PF2), U202.3 (A2)
FMC_A3: U201.13 (PF3), U202.4 (A3)
FMC_A4: U201.14 (PF4), U202.5 (A4)
FMC_A5: U201.15 (PF5), U202.20 (A5)
FMC_A6: U201.50 (PF12), U202.21 (A6)
FMC_A7: U201.53 (PF13), U202.22 (A7)
FMC_A8: U201.54 (PF14), U202.23 (A8)
FMC_A9: U201.55 (PF15), U202.24 (A9)
FMC_A10: U201.56 (PG0), U202.25 (A10)
FMC_A11: U201.57 (PG1), U202.26 (A11)
FMC_A12: U201.87 (PG2), U202.27 (A12)
FMC_A13: U201.88 (PG3), U202.28 (A13)
FMC_A14: U201.89 (PG4), U202.29 (A14)
FMC_A15: U201.90 (PG5), U202.46 (A15)
FMC_A16: U201.80 (PD11), U202.47 (A16)
FMC_A17: U201.81 (PD12), U202.48 (A17)
FMC_A18: U201.82 (PD13), U202.30 (A18)
FMC_D0: J201.40, U201.85 (PD14), U202.8 (D0)
FMC_D1: J201.38, U201.86 (PD15), U202.9 (D1)
FMC_D2: J201.36, U201.114 (PD0), U202.10 (D2)
FMC_D3: J201.34, U201.115 (PD1), U202.11 (D3)
FMC_D4: J201.32, U201.58 (PE7), U202.14 (D4)
FMC_D5: J201.30, U201.59 (PE8), U202.15 (D5)
FMC_D6: J201.28, U201.60 (PE9), U202.16 (D6)
FMC_D7: J201.26, U201.63 (PE10), U202.17 (D7)
FMC_D8: J201.27, U201.64 (PE11), U202.32 (D8)
FMC_D9: J201.25, U201.65 (PE12), U202.33 (D9)
FMC_D10: J201.23, U201.66 (PE13), U202.34 (D10)
FMC_D11: J201.21, U201.67 (PE14), U202.35 (D11)
FMC_D12: J201.19, U201.68 (PE15), U202.38 (D12)
FMC_D13: J201.17, U201.77 (PD8), U202.39 (D13)
FMC_D14: J201.15, U201.78 (PD9), U202.40 (D14)
FMC_D15: J201.13, U201.79 (PD10), U202.41 (D15)
FMC_NBL0: U201.141 (PE0), U202.42 (/LB)
FMC_NBL1: U201.142 (PE1), U202.43 (/UB)
FMC_NE1: J201.11, U201.97 (PC7)
FMC_NE2: U201.124 (PG9), U202.7 (/CS)
FMC_NOE: J201.29, U201.118 (PD4), U202.44 (/OE)
FMC_NWE: J201.31, U201.119 (PD5), U202.18 (/WE)
GND: C201.2, C202.2, C203.2, C204.2, C205.2, C206.2, C207.2, C208.2, C209.2, C210.2, C211.2, C212.2, C213.1, C214.2, C215.1, C216.2, C217.2, C218.1, C219.1, C220.2, C221.2, C222.2, C223.2, C224.2, C225.2, C226.2, C227.2, C228.2, C229.2, C230.2, J201.39, J202.4, JP201.1 (A), Q201.2 (S), Q202.2 (S), Q203.2 (S), Q204.2 (S), Q205.2 (S), Q206.2 (S), Q207.2 (S), Q208.2 (S), R203.1, U201.16 (VSS), U201.31 (VSSA), U201.38 (VSS), U201.51 (VSS), U201.61 (VSS), U201.83 (VSS), U201.94 (VSS), U201.107 (VSS), U201.120 (VSS), U201.130 (VSS), U202.13 (VSS), U202.37 (VSS), Y201.2, Y201.4, Y202.2, Y202.3; also elsewhere on the board
LED_485: R210.2, U201.92 (PG7)
LED_CAN: R209.2, U201.91 (PG6)
LED_ESP: R219.2, U201.127 (PG12)
LED_I2C1: R211.2, U201.93 (PG8)
LED_I2C2: R212.2, U201.125 (PG10)
LED_SD: R220.2, U201.128 (PG13)
LED_SPI3: R217.2, U201.129 (PG14)
LED_SPI4: R218.2, U201.132 (PG15)
MISO4: U201.4 (PE5); also elsewhere on the board
MOSI4: U201.5 (PE6); also elsewhere on the board
unnamed: C211.1, U201.71 (VCAP_1)
unnamed: C212.1, U201.106 (VCAP_2)
unnamed: C213.2, R204.1, U201.23 (PH0), Y201.3
unnamed: C215.2, R204.2, U201.24 (PH1), Y201.1
unnamed: C218.2, U201.8 (PC14), Y202.1
unnamed: C219.2, U201.9 (PC15), Y202.4
unnamed: D201.1 (K), R202.1
unnamed: D202.1 (K), Q201.3 (D)
unnamed: D202.2 (A), R205.2
unnamed: D203.1 (K), Q202.3 (D)
unnamed: D203.2 (A), R206.2
unnamed: D204.1 (K), Q203.3 (D)
unnamed: D204.2 (A), R207.2
unnamed: D205.1 (K), Q204.3 (D)
unnamed: D205.2 (A), R208.2
unnamed: D206.1 (K), Q205.3 (D)
unnamed: D206.2 (A), R213.2
unnamed: D207.1 (K), Q206.3 (D)
unnamed: D207.2 (A), R214.2
unnamed: D208.1 (K), Q207.3 (D)
unnamed: D208.2 (A), R215.2
unnamed: D209.1 (K), Q208.3 (D)
unnamed: D209.2 (A), R216.2
unnamed: Q201.1 (G), R209.1
unnamed: Q202.1 (G), R210.1
unnamed: Q203.1 (G), R211.1
unnamed: Q204.1 (G), R212.1
unnamed: Q205.1 (G), R217.1
unnamed: Q206.1 (G), R218.1
unnamed: Q207.1 (G), R219.1
unnamed: Q208.1 (G), R220.1
unnamed: R203.2, U201.138 (BOOT0)
SCK4: U201.1 (PE2); also elsewhere on the board
SPI2_MISO: J201.16, U201.28 (PC2)
SPI2_MOSI: J201.20, U201.27 (PC1)
SPI2_SCK: J201.24, U201.74 (PB13)
Touch_CS: J201.22, U201.75 (PB14)
Touch_IRQ: J201.14, U201.76 (PB15)

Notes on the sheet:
NC NC SD_CS SD_DIN SD_CLK SD_DO T_IRQ T_DO NC T_DIN T_CS T_CLK DB7 DB6 DB5 DB4 DB3 DB2 DB1 DB0
Touch_Display
Vdd Decoupling STM32
5" TFT LCD
Peripheral Overview: -------------------- SPI1 = ESP32 Coprocessor SPI2 = TFT Touch Sensor SPI3 = 5V Backplane SPI SPI4 = 3V3 Backplane SPI SD1 = SD Interface I2C1 = Fast Mode I2C (400kHz) I2C2 = Normal Mode I2C (100kHz) CAN1 = CAN Bus Backplane UART7 = RS485 Backplane USB_FS = USB Fast Mode Device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
512kx16 8Mbit SRAM
RTC Crystal
main crystal
NC LED_A NC RST F_CS CS DB15 DB14 DB13 DB12 DB11 DB10 DB9 DB8 RD WR RS NC 3V3 GND
1 = active 0 = inactive
LED Indicators for Bus Activities or general usage

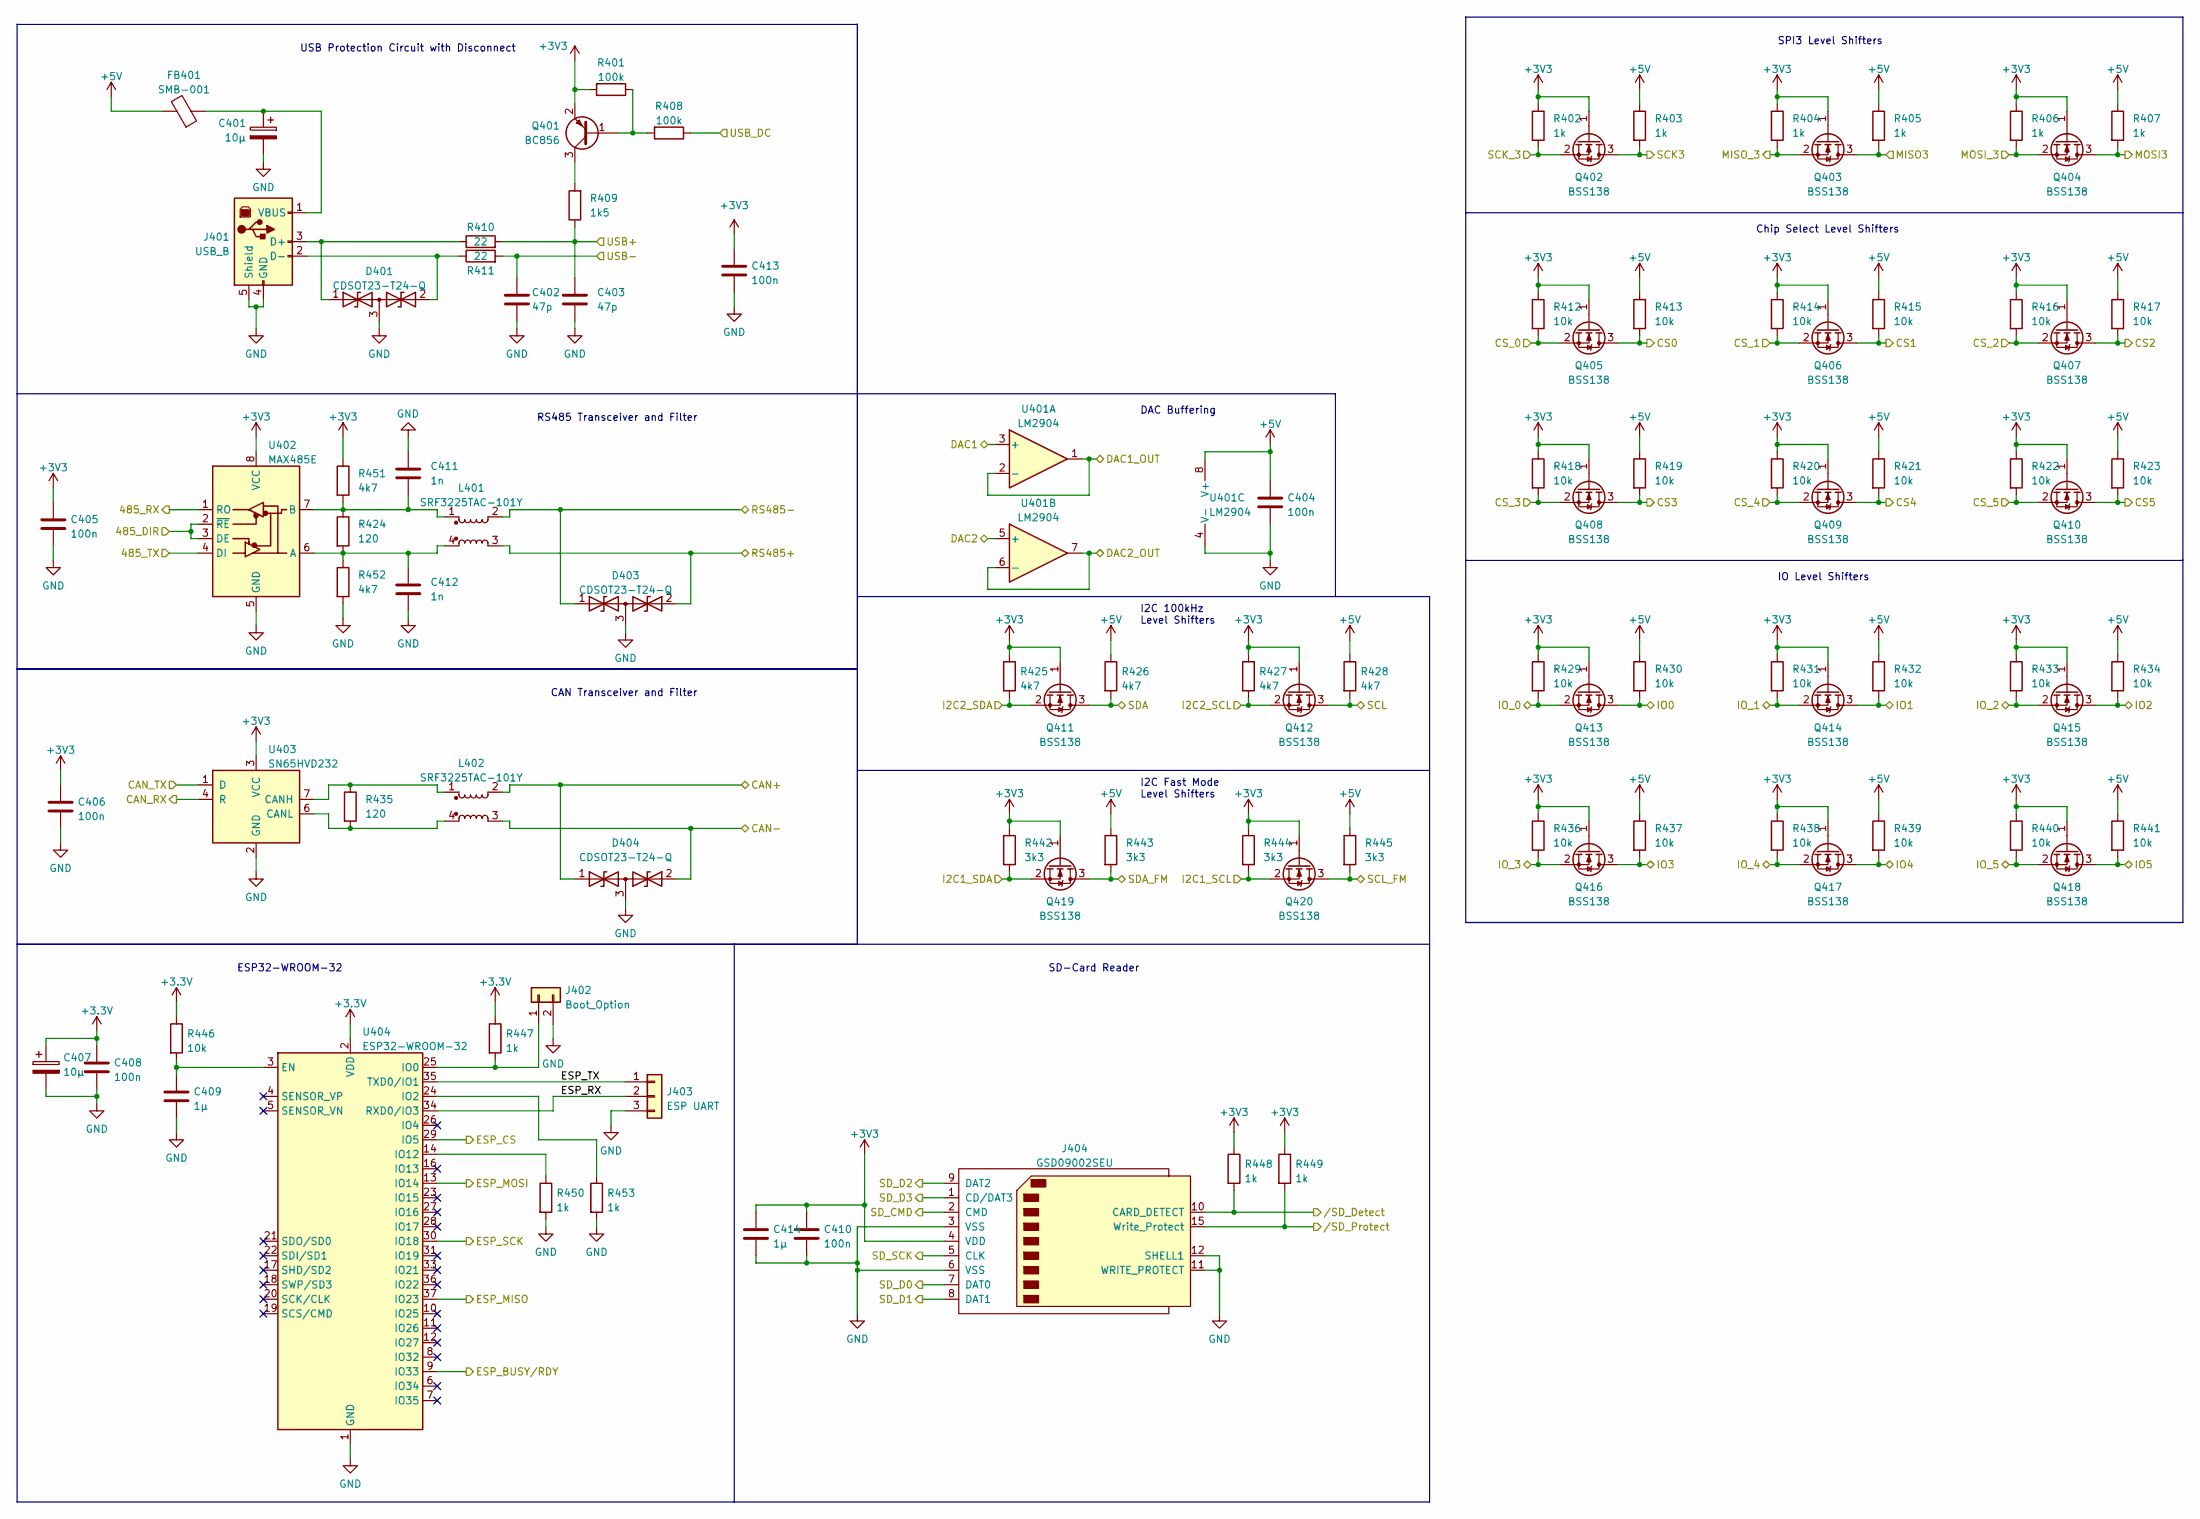
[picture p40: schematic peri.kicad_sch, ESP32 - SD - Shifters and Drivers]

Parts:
C401, C407: 10µ; CP_Elec_5x5.8
C402, C403: 47p; C_0805_2012Metric
C404, C405, C406, C408, C410, C413: 100n; C_0805_2012Metric
C409, C414: 1µ; C_0805_2012Metric
C411, C412: 1n; C_0805_2012Metric
D401, D403, D404: CDSOT23-T24-Q; SOT-23
FB401: SMB-001
J401: USB_B; USB_B_OST_USB-B1HSxx_Horizontal
J402: Boot_Option; PinSocket_1x02_P2.54mm_Vertical
J403: ESP UART; PinSocket_1x03_P2.54mm_Vertical
J404: GSD09002SEU
L401, L402: SRF3225TAC-101Y; SRF3225TAC
Q401: BC856; SOT-23
Q402, Q403, Q404, Q405, Q406, Q407, Q408, Q409, Q410, Q411, Q412, Q413, Q414, Q415, Q416, Q417, Q418, Q419, Q420: BSS138; SOT-23
R401, R408: 100k; R_0805_2012Metric
R402, R403, R404, R405, R406, R407, R447, R448, R449, R450, R453: 1k; R_0805_2012Metric
R409: 1k5; R_0805_2012Metric
R410, R411: 22; R_0805_2012Metric
R412, R413, R414, R415, R416, R417, R418, R419, R420, R421, R422, R423, R429, R430, R431, R432, R433, R434, R436, R437, R438, R439, R440, R441, R446: 10k; R_0805_2012Metric
R424, R435: 120; R_0805_2012Metric
R425, R426, R427, R428, R451, R452: 4k7; R_0805_2012Metric
R442, R443, R444, R445: 3k3; R_0805_2012Metric
U401: LM2904; SOIC-8_3.9x4.9mm_P1.27mm
U402: MAX485E; SOIC-8_3.9x4.9mm_P1.27mm
U403: SN65HVD232; SOIC-8_3.9x4.9mm_P1.27mm
U404: ESP32-WROOM-32

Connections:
+3.3V: C407.1, C408.1, R446.1, R447.1, U404.2 (VDD); also elsewhere on the board
+3V3: C405.1, C406.1, C410.1, C413.1, C414.1, J404.4 (VDD), Q401.2 (E), Q402.1 (G), Q403.1 (G), Q404.1 (G), Q405.1 (G), Q406.1 (G), Q407.1 (G), Q408.1 (G), Q409.1 (G), Q410.1 (G), Q411.1 (G), Q412.1 (G), Q413.1 (G), Q414.1 (G), Q415.1 (G), Q416.1 (G), Q417.1 (G), Q418.1 (G), Q419.1 (G), Q420.1 (G), R401.2, R402.1, R404.1, R406.1, R412.1, R414.1, R416.1, R418.1, R420.1, R422.1, R425.1, R427.1, R429.1, R431.1, R433.1, R436.1, R438.1, R440.1, R442.1, R444.1, R448.1, R449.1, R451.1, U402.8 (VCC), U403.3 (VCC); also elsewhere on the board
+5V: C404.1, FB401.2, R403.1, R405.1, R407.1, R413.1, R415.1, R417.1, R419.1, R421.1, R423.1, R426.1, R428.1, R430.1, R432.1, R434.1, R437.1, R439.1, R441.1, R443.1, R445.1, U401.8 (V+); also elsewhere on the board
/CPU/CAN1_RX: U403.4 (R); also elsewhere on the board
/CPU/CAN1_TX: U403.1 (D); also elsewhere on the board
/CPU/CS_0: Q405.2 (S), R412.2; also elsewhere on the board
/CPU/CS_1: Q406.2 (S), R414.2; also elsewhere on the board
/CPU/CS_2: Q407.2 (S), R416.2; also elsewhere on the board
/CPU/CS_3: Q408.2 (S), R418.2; also elsewhere on the board
/CPU/CS_4: Q409.2 (S), R420.2; also elsewhere on the board
/CPU/CS_5: Q410.2 (S), R422.2; also elsewhere on the board
/CPU/DAC_OUT1: U401.3 (+); also elsewhere on the board
/CPU/DAC_OUT2: U401.5 (+); also elsewhere on the board
/CPU/ESP32_CS: U404.29 (IO5); also elsewhere on the board
/CPU/ESP32_RDY: U404.9 (IO33); also elsewhere on the board
/CPU/I2C1FM_SCL: Q420.2 (S), R444.2; also elsewhere on the board
/CPU/I2C2_SCL: Q412.2 (S), R427.2; also elsewhere on the board
/CPU/I2C2_SDA: Q411.2 (S), R425.2; also elsewhere on the board
/CPU/I2CFM_SDA: Q419.2 (S), R442.2; also elsewhere on the board
/CPU/IO_0: Q413.2 (S), R429.2; also elsewhere on the board
/CPU/IO_1: Q414.2 (S), R431.2; also elsewhere on the board
/CPU/IO_2: Q415.2 (S), R433.2; also elsewhere on the board
/CPU/IO_3: Q416.2 (S), R436.2; also elsewhere on the board
/CPU/IO_4: Q417.2 (S), R438.2; also elsewhere on the board
/CPU/IO_5: Q418.2 (S), R440.2; also elsewhere on the board
/CPU/SD1_CK: J404.5 (CLK); also elsewhere on the board
/CPU/SD1_CMD: J404.2 (CMD); also elsewhere on the board
/CPU/SD1_D0: J404.7 (DAT0); also elsewhere on the board
/CPU/SD1_D1: J404.8 (DAT1); also elsewhere on the board
/CPU/SD1_D2: J404.9 (DAT2); also elsewhere on the board
/CPU/SD1_D3: J404.1 (CD/DAT3); also elsewhere on the board
/CPU/SPI1_MISO: U404.37 (IO23); also elsewhere on the board
/CPU/SPI1_MOSI: U404.13 (IO14); also elsewhere on the board
/CPU/SPI1_SCK: U404.30 (IO18); also elsewhere on the board
/CPU/SPI3_MISO: Q403.2 (S), R404.2; also elsewhere on the board
/CPU/SPI3_MOSI: Q404.2 (S), R406.2; also elsewhere on the board
/CPU/SPI3_SCK: Q402.2 (S), R402.2; also elsewhere on the board
/CPU/UART7_DE_485: U402.2 (~RE), U402.3 (DE); also elsewhere on the board
/CPU/UART7_RX_485: U402.1 (RO); also elsewhere on the board
/CPU/UART7_TX_485: U402.4 (DI); also elsewhere on the board
/CPU/USB+: C403.1, R409.1, R410.2; also elsewhere on the board
/CPU/USB-: C402.1, R411.2; also elsewhere on the board
/CPU/USB_Disconnect: R408.1; also elsewhere on the board
/CPU//SD_Card_Detect: J404.10 (CARD_DETECT), R448.2; also elsewhere on the board
/CPU//SD_Write_Protect: J404.15 (Write_Protect), R449.2; also elsewhere on the board
/Peripherals/ESP_RX: J403.2, U404.34 (RXD0/IO3)
/Peripherals/ESP_TX: J403.1, U404.35 (TXD0/IO1)
CAN+: D404.1 (A1), L402.2; also elsewhere on the board
CAN-: D404.2 (A2), L402.3; also elsewhere on the board
CS0: Q405.3 (D), R413.2; also elsewhere on the board
CS1: Q406.3 (D), R415.2; also elsewhere on the board
CS2: Q407.3 (D), R417.2; also elsewhere on the board
CS3: Q408.3 (D), R419.2; also elsewhere on the board
CS4: Q409.3 (D), R421.2; also elsewhere on the board
CS5: Q410.3 (D), R423.2; also elsewhere on the board
DAC1_OUT: U401.1, U401.2 (-); also elsewhere on the board
DAC2_OUT: U401.6 (-), U401.7; also elsewhere on the board
GND: C401.2, C402.2, C403.2, C404.2, C405.2, C406.2, C407.2, C408.2, C409.2, C410.2, C411.1, C412.2, C413.2, C414.2, D401.3 (common), D403.3 (common), D404.3 (common), J401.4 (GND), J401.5 (Shield), J402.2, J403.3, J404.3 (VSS), J404.6 (VSS), J404.11 (WRITE_PROTECT), J404.12 (SHELL1), R450.2, R452.2, R453.2, U401.4 (V-), U402.5 (GND), U403.2 (GND), U404.1 (GND), U404.15 (GND), U404.38 (GND), U404.39 (GND); also elsewhere on the board
IO0: Q413.3 (D), R430.2; also elsewhere on the board
IO1: Q414.3 (D), R432.2; also elsewhere on the board
IO2: Q415.3 (D), R434.2; also elsewhere on the board
IO3: Q416.3 (D), R437.2; also elsewhere on the board
IO4: Q417.3 (D), R439.2; also elsewhere on the board
IO5: Q418.3 (D), R441.2; also elsewhere on the board
MISO3: Q403.3 (D), R405.2; also elsewhere on the board
MOSI3: Q404.3 (D), R407.2; also elsewhere on the board
unnamed: C401.1, FB401.1, J401.1 (VBUS)
unnamed: C409.1, R446.2, U404.3 (EN)
unnamed: C411.2, L401.1, R424.1, R451.2, U402.7 (B)
unnamed: C412.1, L401.4, R424.2, R452.1, U402.6 (A)
unnamed: D401.2 (A2), J401.2 (D-), R411.1
unnamed: D401.1 (A1), J401.3 (D+), R410.1
unnamed: J402.1, R447.2, U404.25 (IO0)
unnamed: L402.1, R435.1, U403.7 (CANH)
unnamed: L402.4, R435.2, U403.6 (CANL)
unnamed: Q401.1 (B), R401.1, R408.2
unnamed: Q401.3 (C), R409.2
unnamed: R450.1, U404.14 (IO12)
unnamed: R453.1, U404.24 (IO2)
RS485+: D403.2 (A2), L401.3; also elsewhere on the board
RS485-: D403.1 (A1), L401.2; also elsewhere on the board
SCK3: Q402.3 (D), R403.2; also elsewhere on the board
SCL: Q412.3 (D), R428.2; also elsewhere on the board
SCL_FM: Q420.3 (D), R445.2; also elsewhere on the board
SDA: Q411.3 (D), R426.2; also elsewhere on the board
SDA_FM: Q419.3 (D), R443.2; also elsewhere on the board

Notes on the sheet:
SPI3 Level Shifters
RS485 Transceiver and Filter
SD-Card Reader
IO Level Shifters
DAC Buffering
USB Protection Circuit with Disconnect
Chip Select Level Shifters
ESP32-WROOM-32
I2C 100kHz Level Shifters
CAN Transceiver and Filter
I2C Fast Mode Level Shifters

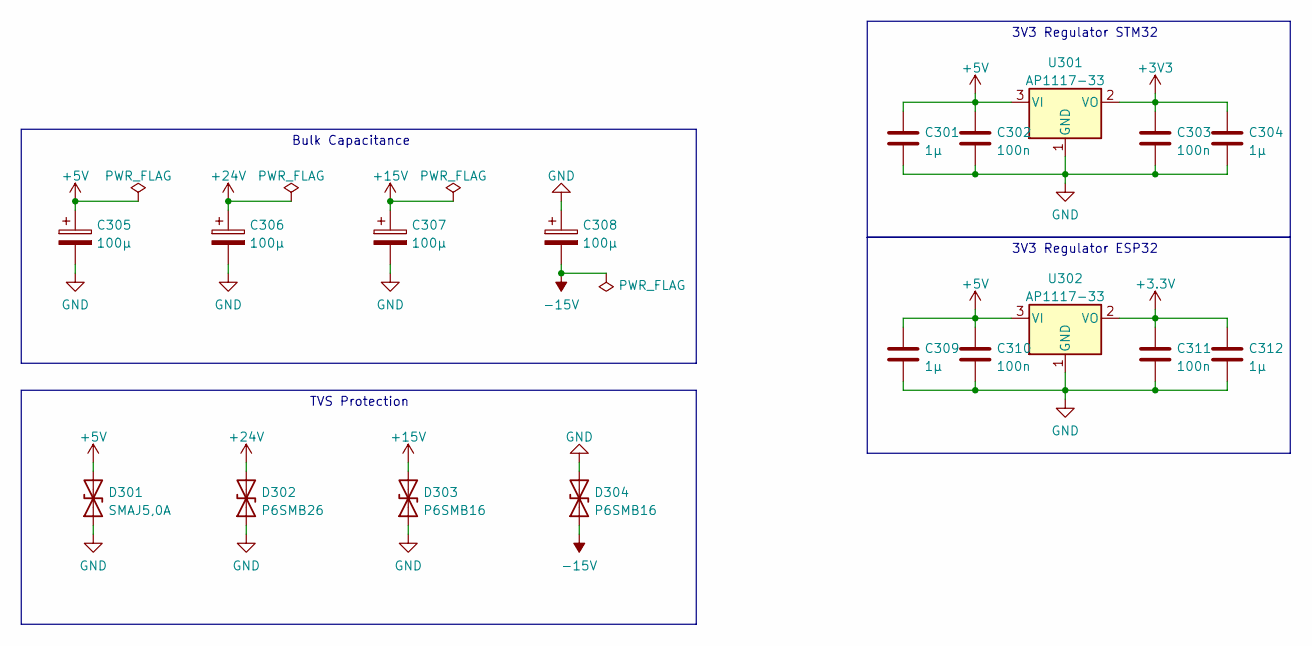
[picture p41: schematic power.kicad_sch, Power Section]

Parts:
C301, C304, C309, C312: 1µ; C_0805_2012Metric
C302, C303, C310, C311: 100n; C_0805_2012Metric
C305, C306, C307, C308: 100µ; CP_Radial_D8.0mm_P5.00mm
D301: SMAJ5,0A; D_SMA
D302: P6SMB26; D_SMA
D303, D304: P6SMB16; D_SMA
U301, U302: AP1117-33; SOT-223-3_TabPin2

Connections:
+3.3V: C311.1, C312.1, U302.2 (VO); also elsewhere on the board
+3V3: C303.1, C304.1, U301.2 (VO); also elsewhere on the board
+5V: C301.1, C302.1, C305.1, C309.1, C310.1, D301.2 (A2), U301.3 (VI), U302.3 (VI); also elsewhere on the board
+15V: C307.1, D303.2 (A2); also elsewhere on the board
+24V: C306.1, D302.2 (A2); also elsewhere on the board
-15V: C308.2, D304.1 (A1); also elsewhere on the board
GND: C301.2, C302.2, C303.2, C304.2, C305.2, C306.2, C307.2, C308.1, C309.2, C310.2, C311.2, C312.2, D301.1 (A1), D302.1 (A1), D303.1 (A1), D304.2 (A2), U301.1 (GND), U302.1 (GND); also elsewhere on the board

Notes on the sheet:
Bulk Capacitance
3V3 Regulator ESP32
3V3 Regulator STM32
TVS Protection

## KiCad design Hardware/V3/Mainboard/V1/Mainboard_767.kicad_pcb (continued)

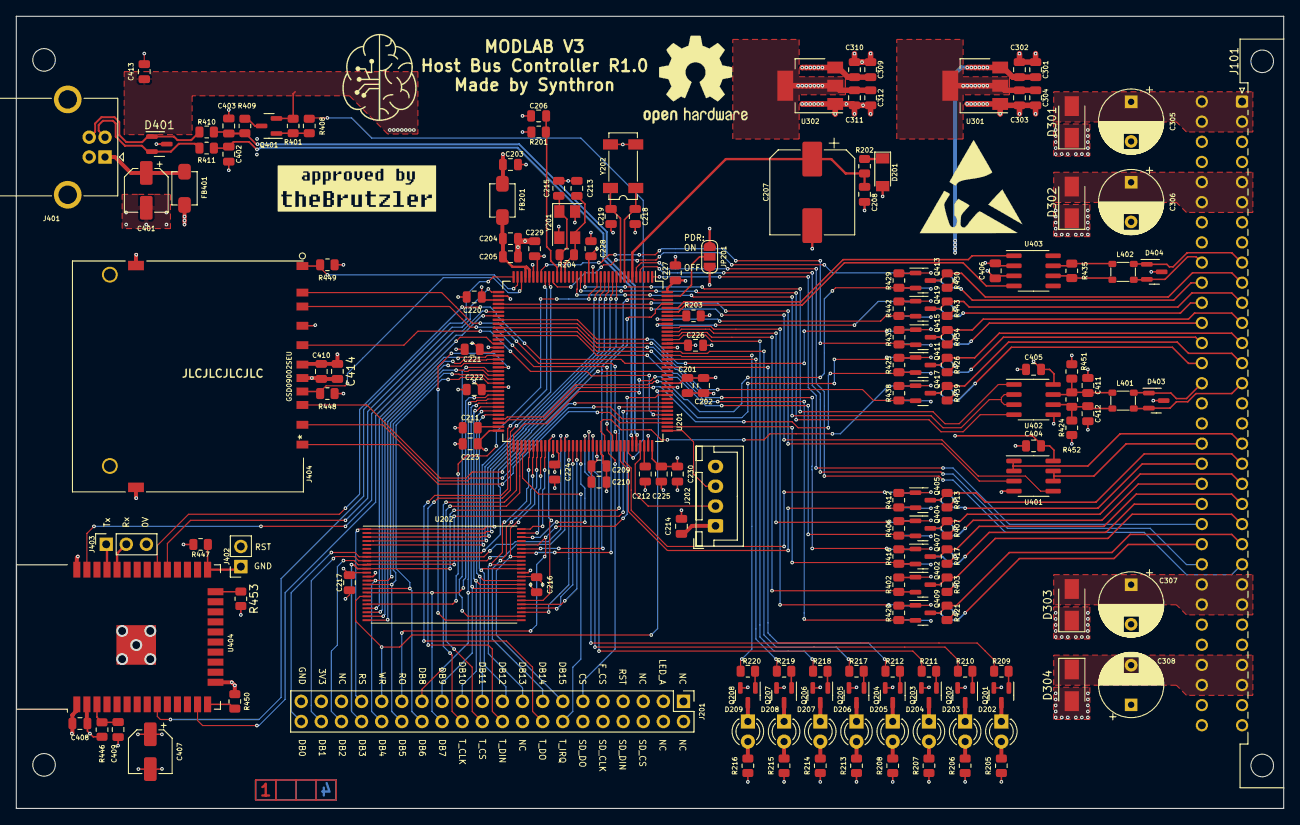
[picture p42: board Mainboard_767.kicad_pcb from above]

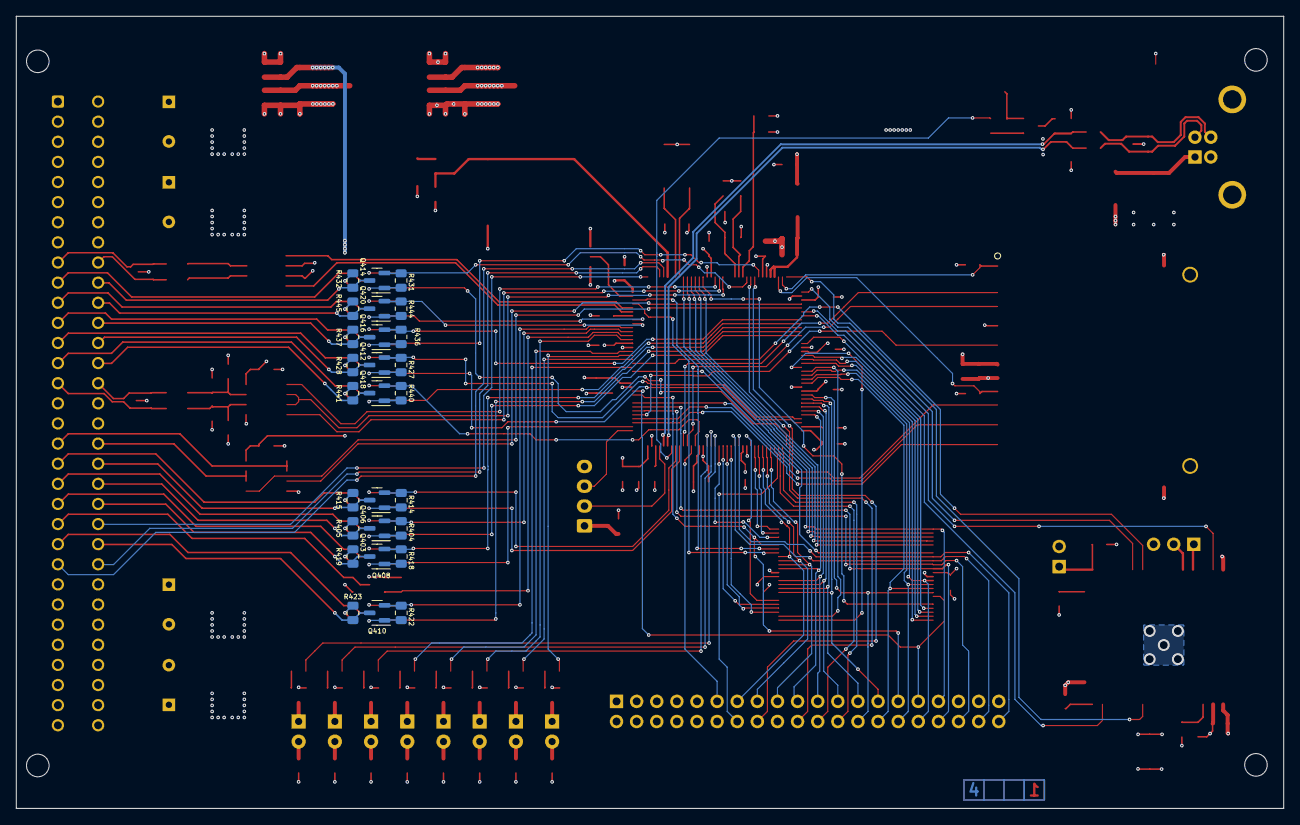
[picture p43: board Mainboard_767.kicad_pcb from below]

Board: 4 copper layers, 160.0 x 100.0 mm, 195 parts (27 on the bottom side), 184 nets.

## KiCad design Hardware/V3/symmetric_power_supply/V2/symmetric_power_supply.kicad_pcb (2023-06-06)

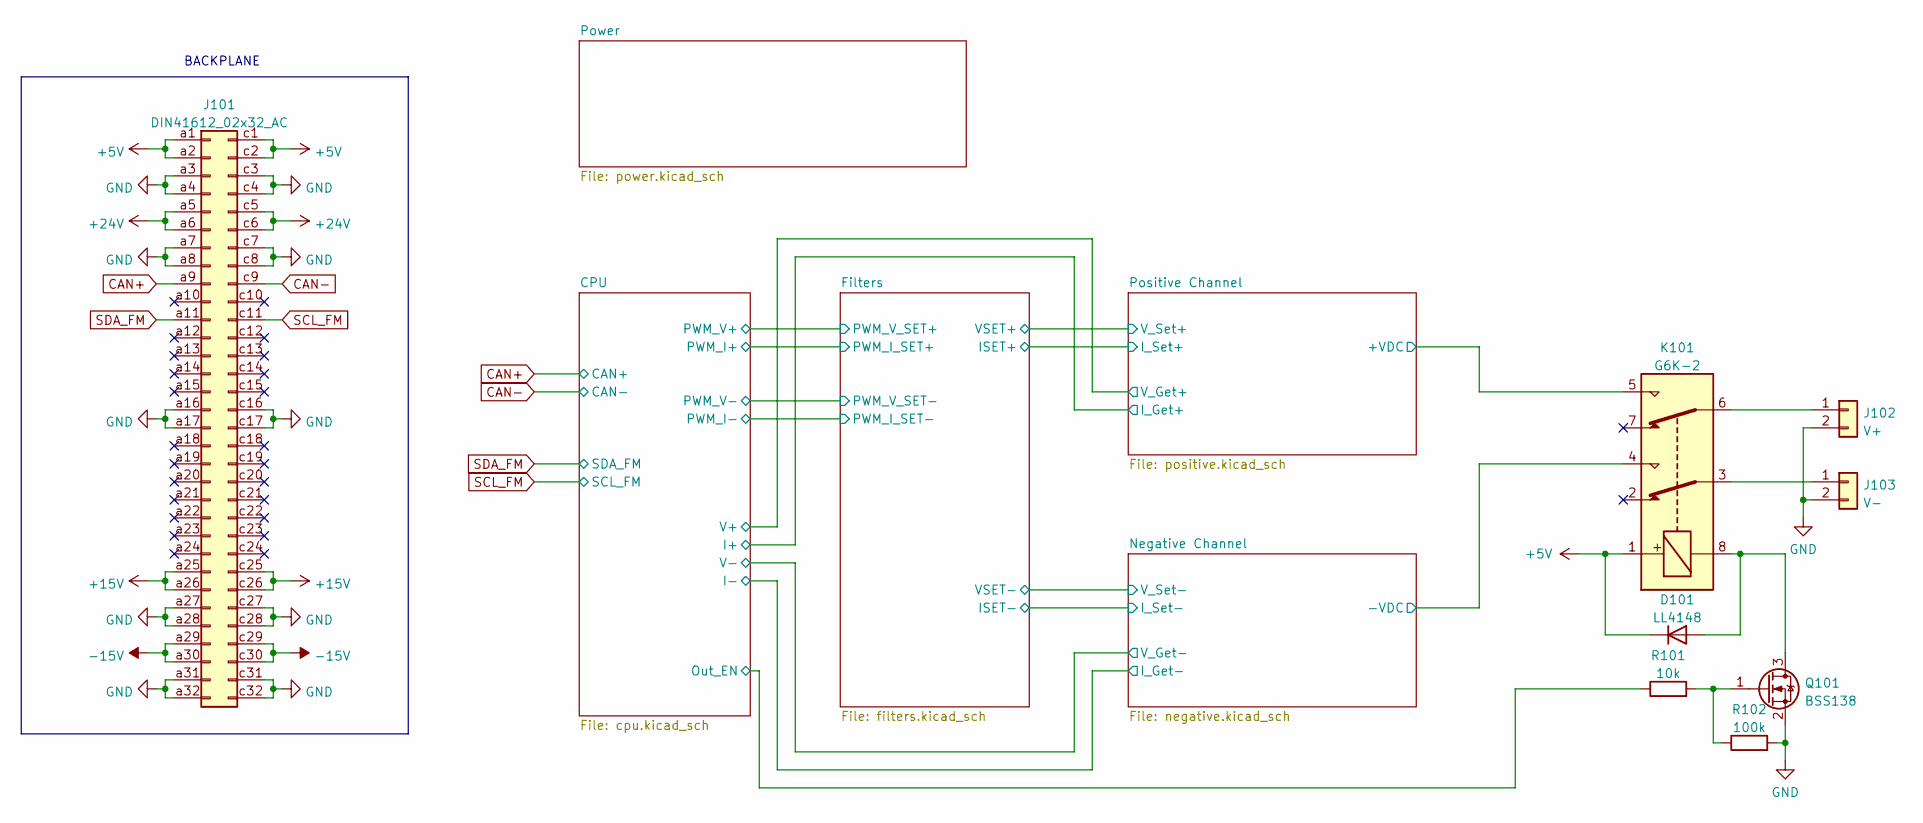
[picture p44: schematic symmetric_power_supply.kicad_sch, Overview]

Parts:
D101: LL4148; D_MiniMELF
J101: DIN41612_02x32_AC; VG64_Euro
J102: V+; PinHeader_1x02_P2.54mm_Vertical
J103: V-; PinHeader_1x02_P2.54mm_Vertical
K101: G6K-2; Relay_DPDT_Omron_G6K-2F
Q101: BSS138; SOT-23
R101: 10k; R_0805_2012Metric
R102: 100k; R_0805_2012Metric

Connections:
+5V: D101.1 (K), J101.a1, J101.a2, J101.c1, J101.c2, K101.1; also elsewhere on the board
+15V: J101.a25, J101.a26, J101.c25, J101.c26; also elsewhere on the board
+24V: J101.a5, J101.a6, J101.c5, J101.c6; also elsewhere on the board
+VDC: K101.5; also elsewhere on the board
-15V: J101.a29, J101.a30, J101.c29, J101.c30; also elsewhere on the board
-VDC: K101.4; also elsewhere on the board
/CPU/Out_EN: R101.1; also elsewhere on the board
CAN+: J101.a9; also elsewhere on the board
CAN-: J101.c9; also elsewhere on the board
GND: J101.a3, J101.a4, J101.a7, J101.a8, J101.a16, J101.a17, J101.a27, J101.a28, J101.a31, J101.a32, J101.c3, J101.c4, J101.c7, J101.c8, J101.c16, J101.c17, J101.c27, J101.c28, J101.c31, J101.c32, J102.2, J103.2, Q101.2 (S), R102.2; also elsewhere on the board
unnamed: D101.2 (A), K101.8, Q101.3 (D)
unnamed: J102.1, K101.6
unnamed: J103.1, K101.3
unnamed: Q101.1 (G), R101.2, R102.1
SCL_FM: J101.c11; also elsewhere on the board
SDA_FM: J101.a11; also elsewhere on the board

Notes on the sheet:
BACKPLANE


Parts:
C501, C502, C503, C504: 100µ; CP_Radial_D8.0mm_P5.00mm
C505, C508: 1µ; C_0805_2012Metric
C506, C507: 100n; C_0805_2012Metric
D501: SMAJ5,0A; D_SMA
D502: P6SMB26; D_SMA
D503, D504: P6SMB16; D_SMA
U501: AP1117-33; SOT-223-3_TabPin2

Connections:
+3V3: C507.1, C508.1, U501.2 (VO); also elsewhere on the board
+5V: C501.1, C505.1, C506.1, D501.2 (A2), U501.3 (VI); also elsewhere on the board
+15V: C503.1, D503.2 (A2); also elsewhere on the board
+24V: C502.1, D502.2 (A2); also elsewhere on the board
-15V: C504.2, D504.1 (A1); also elsewhere on the board
GND: C501.2, C502.2, C503.2, C504.1, C505.2, C506.2, C507.2, C508.2, D501.1 (A1), D502.1 (A1), D503.1 (A1), D504.2 (A2), U501.1 (GND); also elsewhere on the board

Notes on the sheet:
Bulk Capacitance
TVS Protection
3V3 Regulator STM32


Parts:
C401, C402, C407, C408, C409, C410, C411: 100n; C_0805_2012Metric
C403, C404: 1µ; C_0805_2012Metric
C405, C406: 20p; C_0805_2012Metric
C412: 4µ7; C_0805_2012Metric
C413, C414, C415: 1n; C_0805_2012Metric
D401: CDSOT23-T24-Q; SOT-23
FB401: SMB-001
J401: SWD; JST_XH_B4B-XH-A_1x04_P2.50mm_Vertical
J402: Address; PinHeader_2x02_P2.54mm_Vertical
L401: SRF3225TAC-101Y; SRF3225TAC
Q401, Q402: BSS138; SOT-23
R401, R408, R409: 10k; R_0805_2012Metric
R402: 100; R_0805_2012Metric
R403: 1M; R_0805_2012Metric
R404, R405, R406, R407: 4k7; R_0805_2012Metric
U401: SN65HVD232; SOIC-8_3.9x4.9mm_P1.27mm
U402: STM32F103C8Tx; LQFP-48_7x7mm_P0.5mm
Y401: 8MHz; Crystal_SMD_5032-4Pin_5.0x3.2mm

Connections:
+3V3: C404.1, C407.1, C408.1, C409.1, C410.1, C411.1, C412.1, FB401.1, J401.1, J402.1, J402.3, Q401.1 (G), Q402.1 (G), R401.2, R404.2, R406.2, U401.3 (VCC), U402.1 (VBAT), U402.24 (VDD), U402.36 (VDD), U402.48 (VDD); also elsewhere on the board
+5V: R405.2, R407.2; also elsewhere on the board
/CPU/I+: C414.1, U402.11 (PA1); also elsewhere on the board
/CPU/I-: C415.1, U402.13 (PA3); also elsewhere on the board
/CPU/Out_EN: U402.17 (PA7); also elsewhere on the board
/CPU/PWM_I+: U402.39 (PB3); also elsewhere on the board
/CPU/PWM_I-: U402.22 (PB11); also elsewhere on the board
/CPU/PWM_V+: U402.38 (PA15); also elsewhere on the board
/CPU/PWM_V-: U402.21 (PB10); also elsewhere on the board
/CPU/SWCLK: J401.3, U402.37 (PA14)
/CPU/SWDIO: J401.2, U402.34 (PA13)
/CPU/V+: C413.1, U402.10 (PA0); also elsewhere on the board
/CPU/V-: U402.12 (PA2); also elsewhere on the board
CAN+: D401.1 (A1), L401.2; also elsewhere on the board
CAN-: D401.2 (A2), L401.3; also elsewhere on the board
CAN_Rx: U401.4 (R), U402.45 (PB8)
CAN_Tx: U401.1 (D), U402.46 (PB9)
GND: C401.2, C402.2, C403.2, C404.2, C405.1, C406.1, C407.2, C408.2, C409.2, C410.2, C411.2, C412.2, C413.2, C414.2, C415.2, D401.3 (common), J401.4, R402.1, R408.2, R409.2, U401.2 (GND), U402.8 (VSSA), U402.23 (VSS), U402.35 (VSS), U402.47 (VSS), Y401.2, Y401.4; also elsewhere on the board
unnamed: C401.1, R401.1, U402.7 (NRST)
unnamed: C402.1, C403.1, FB401.2, U402.9 (VDDA)
unnamed: C405.2, R403.1, U402.5 (PD0), Y401.3
unnamed: C406.2, R403.2, U402.6 (PD1), Y401.1
unnamed: J402.2, R408.1, U402.20 (PB2)
unnamed: J402.4, R409.1, U402.40 (PB4)
unnamed: L401.1, U401.7 (CANH)
unnamed: L401.4, U401.6 (CANL)
unnamed: R402.2, U402.44 (BOOT0)
SCL: Q401.2 (S), R404.1, U402.42 (PB6)
SCL_FM: Q401.3 (D), R405.1; also elsewhere on the board
SDA: Q402.2 (S), R406.1, U402.43 (PB7)
SDA_FM: Q402.3 (D), R407.1; also elsewhere on the board

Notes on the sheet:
main crystal
cap for V- on corresponding page


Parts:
C301, C307, C308, C314: 1µ; C_0805_2012Metric
C302, C305: 100µ; CP_Elec_5x5.8
C303, C304, C306, C309, C310, C311, C312: 100n; C_0805_2012Metric
C313: 1n; C_0805_2012Metric
D301, D302, D303: D_Schottky; D_SOD-123
D304, D306, D307: 5V1; D_SOD-123
D305: CC+; LED_D3.0mm
HS301: Heatsink; SK574-50
Q301: TIP102; TO-220-3_Vertical
R301: R500; R_2512_6332Metric
R302, R305, R306, R308, R310, R311, R313, R319, R320, R321: 1k; R_0805_2012Metric
R303: 200; R_0805_2012Metric
R304, R314, R315, R323, R328: 5k1; R_0805_2012Metric
R307: 100; R_0805_2012Metric
R309: 10k; R_0805_2012Metric
R312, R322, R325: 2k; R_0805_2012Metric
R316, R324: 510; R_0805_2012Metric
R317, R326: 20k; R_0805_2012Metric
R318: 200k; R_0805_2012Metric
R327: 3k; R_0805_2012Metric
U301: LM337_TO220; TO-220-3_Vertical
U302, U303: LM2902; TSSOP-14_4.4x5mm_P0.65mm

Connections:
+15V: C309.1, C310.1, R314.1, R316.1, R324.1, U302.4 (V+), U303.4 (V+); also elsewhere on the board
-15V: C301.1, C311.2, C312.2, Q301.3 (E), R302.1, U302.11 (V-), U303.11 (V-); also elsewhere on the board
-VDC: C305.2, C306.1, D301.1 (K), D302.2 (A), R303.1, R326.1, U301.3 (VO); also elsewhere on the board
/CPU/I-: C308.1, D304.1 (K), R308.2; also elsewhere on the board
/CPU/V-: C313.1, R325.2, U303.8; also elsewhere on the board
/Filters/ISET-: U302.3 (+); also elsewhere on the board
/Filters/VSET-: U303.3 (+); also elsewhere on the board
GND: C301.2, C302.1, C303.2, C304.2, C305.1, C306.2, C307.2, C308.2, C309.2, C310.2, C311.1, C312.1, C313.2, C314.2, D304.2 (A), D305.1 (K), D306.2 (A), D307.2 (A), R305.1, R315.1, R317.1, R321.1, R328.2, U303.10 (+), U303.12 (+); also elsewhere on the board
unnamed: C307.1, Q301.1 (B), R302.2, R309.2
unnamed: C314.1, R326.2, R328.1, U303.5 (+)
unnamed: D302.1 (K), D303.1 (K), R303.2, U301.1 (ADJ)
unnamed: D303.2 (A), R319.2, U303.14
unnamed: D305.2 (A), R310.2
unnamed: D306.1 (K), R312.2, R316.2
unnamed: D307.1 (K), R323.1, R324.2
unnamed: R304.1, R306.2, U302.6 (-)
unnamed: R304.2, R308.1, R313.1, U302.7
unnamed: R305.2, R307.1, R312.1, U302.2 (-)
unnamed: R307.2, U302.1, U302.10 (+)
unnamed: R309.1, R318.2, U302.8, U302.13 (-)
unnamed: R310.1, U302.14
unnamed: R311.2, R315.2, U302.5 (+)
unnamed: R313.2, R318.1, U302.9 (-)
unnamed: R319.1, R320.2, U303.13 (-)
unnamed: R320.1, R322.2, U303.1
unnamed: R321.2, R322.1, R323.2, U303.2 (-)
unnamed: R325.1, R327.2, U303.9 (-)
unnamed: R327.1, U303.6 (-), U303.7
unnamed: R314.2, R317.2, U302.12 (+)
POST_Shunt-: C304.1, D301.2 (A), R301.2, R311.1, U301.2 (VI)
PRE_Shunt-: C302.2, C303.1, Q301.2 (C), R301.1, R306.1

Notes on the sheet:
Current Sense Amplifier
I_Set Bias
Voltage Adjustment
Current Limit LED
Voltage Readout
Current Limiter


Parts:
C201, C207, C208, C211: 1µ; C_0805_2012Metric
C202, C205: 100µ; CP_Elec_5x5.8
C203, C204, C206, C209, C210, C213, C214: 100n; C_0805_2012Metric
C212: 1n; C_0805_2012Metric
D201, D202, D203: D_Schottky; D_SOD-123
D204, D206, D207: 5V1; D_SOD-123
D205: CC+; LED_D3.0mm
HS201: Heatsink; SK574-50
Q201: TIP107; TO-220-3_Vertical
R201: R500; R_2512_6332Metric
R202, R205, R207, R209, R212, R214, R216: 1k; R_0805_2012Metric
R203: 200; R_0805_2012Metric
R204, R213, R219, R221, R226: 5k1; R_0805_2012Metric
R206, R210, R215: 2k; R_0805_2012Metric
R208, R224: 100; R_0805_2012Metric
R211: 10k; R_0805_2012Metric
R217, R223: 20k; R_0805_2012Metric
R218, R220: 510; R_0805_2012Metric
R222: 200k; R_0805_2012Metric
R225: 3k9; R_0805_2012Metric
R227: 12k; R_0805_2012Metric
U201: LM317_TO-220; TO-220-3_Vertical
U202, U203: LM2902; TSSOP-14_4.4x5mm_P0.65mm

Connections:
+15V: C201.1, C209.1, C210.1, Q201.3 (E), R202.1, R218.1, R220.1, U202.4 (V+), U203.4 (V+); also elsewhere on the board
+VDC: C205.1, C206.1, D201.2 (A), D202.1 (K), R203.1, R223.1, U201.2 (VO); also elsewhere on the board
-15V: C213.2, C214.2, R217.1, U202.11 (V-), U203.11 (V-); also elsewhere on the board
/CPU/I+: C208.1, D204.1 (K), R209.2; also elsewhere on the board
/CPU/V+: U203.8, U203.9 (-); also elsewhere on the board
/Filters/ISET+: U202.3 (+); also elsewhere on the board
/Filters/VSET+: U203.3 (+); also elsewhere on the board
GND: C201.2, C202.2, C203.2, C204.2, C205.2, C206.2, C207.2, C208.2, C209.2, C210.2, C211.2, C212.2, C213.1, C214.1, D204.2 (A), D205.1 (K), D206.2 (A), D207.2 (A), R205.1, R206.1, R219.1, R221.2, R226.2, R227.2, U203.12 (+); also elsewhere on the board
unnamed: C207.1, Q201.1 (B), R202.2, R211.2
unnamed: C211.1, R223.2, R226.1, U203.5 (+)
unnamed: C212.1, R225.2, R227.1, U203.10 (+)
unnamed: D202.2 (A), D203.2 (A), R203.2, U201.1 (ADJ)
unnamed: D203.1 (K), R210.2, U203.1
unnamed: D205.2 (A), R212.2
unnamed: D206.1 (K), R213.1, R218.2
unnamed: D207.1 (K), R215.2, R220.2
unnamed: R204.1, R207.2, U202.6 (-)
unnamed: R204.2, R209.1, U202.7, U202.10 (+)
unnamed: R205.2, R208.1, R215.1, U202.2 (-)
unnamed: R206.2, R210.1, R213.2, U203.2 (-)
unnamed: R208.2, R216.1, U202.1
unnamed: R211.1, R222.2, U202.8, U202.12 (+)
unnamed: R212.1, U202.14
unnamed: R214.2, R219.2, U202.5 (+)
unnamed: R216.2, R222.1, U202.9 (-)
unnamed: R217.2, R221.1, U202.13 (-)
unnamed: R224.1, U203.6 (-), U203.7
unnamed: R224.2, R225.1
unnamed: U203.13 (-), U203.14
POST_Shunt+: C204.1, D201.1 (K), R201.2, R207.1, U201.3 (VI)
PRE_Shunt+: C202.1, C203.1, Q201.2 (C), R201.1, R214.1

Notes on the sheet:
I_Set Bias
Voltage Readout
Current Sense Amplifier
Current Limit LED
Current Limiter
Voltage Adjustment


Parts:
C601, C602, C604, C606, C607, C608, C610, C612: 470n; C_0805_2012Metric
C603, C605, C609, C611: 5n6; C_0805_2012Metric
C613, C614: 100n; C_0805_2012Metric
R601, R602, R611, R612: 1k3; R_0805_2012Metric
R603, R604, R605, R606, R613, R614, R615, R616: 22k; R_0805_2012Metric
R607, R608, R617, R618: 1k; R_0805_2012Metric
R609, R610, R619, R620: 1k8; R_0805_2012Metric
U601: LM2902; TSSOP-14_4.4x5mm_P0.65mm

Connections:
+15V: C613.1, U601.4 (V+); also elsewhere on the board
-15V: C614.2, U601.11 (V-); also elsewhere on the board
/CPU/PWM_I+: R602.1; also elsewhere on the board
/CPU/PWM_I-: R611.1; also elsewhere on the board
/CPU/PWM_V+: R601.1; also elsewhere on the board
/CPU/PWM_V-: R612.1; also elsewhere on the board
/Filters/ISET+: C602.2, R608.1, U601.14; also elsewhere on the board
/Filters/ISET-: C607.2, R617.1, U601.7; also elsewhere on the board
/Filters/VSET+: C601.2, R607.1, U601.8; also elsewhere on the board
/Filters/VSET-: C608.2, R618.1, U601.1; also elsewhere on the board
GND: C603.2, C604.2, C605.2, C606.2, C609.2, C610.2, C611.2, C612.2, C613.2, C614.1, R609.2, R610.2, R619.2, R620.2; also elsewhere on the board
unnamed: C601.1, R603.2, R604.1
unnamed: C602.1, R605.2, R606.1
unnamed: C603.1, R601.2, R603.1
unnamed: C604.1, R604.2, U601.10 (+)
unnamed: C605.1, R602.2, R605.1
unnamed: C606.1, R606.2, U601.12 (+)
unnamed: C607.1, R613.2, R614.1
unnamed: C608.1, R615.2, R616.1
unnamed: C609.1, R611.2, R613.1
unnamed: C610.1, R614.2, U601.5 (+)
unnamed: C611.1, R612.2, R615.1
unnamed: C612.1, R616.2, U601.3 (+)
unnamed: R607.2, R609.1, U601.9 (-)
unnamed: R608.2, R610.1, U601.13 (-)
unnamed: R617.2, R619.1, U601.6 (-)
unnamed: R618.2, R620.1, U601.2 (-)


Board: 4 copper layers, 160.0 x 100.0 mm, 197 parts (0 on the bottom side), 106 nets.

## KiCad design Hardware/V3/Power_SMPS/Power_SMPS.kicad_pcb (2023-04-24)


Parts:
D101: LL4148; D_MiniMELF
J101: DIN41612_02x32_AC; VG64_Euro
J102: Conn_01x02; PinSocket_1x02_P2.54mm_Vertical
K101: ADW11; JS 05 MN KT
Q101: BSS138; SOT-23
R101: 10k; R_0805_2012Metric
R102: 100k; R_0805_2012Metric

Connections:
+5V: D101.1 (K), J101.a1, J101.a2, J101.c1, J101.c2, K101.1; also elsewhere on the board
+15V: J101.a25, J101.a26, J101.c25, J101.c26; also elsewhere on the board
+24V: J101.a5, J101.a6, J101.c5, J101.c6; also elsewhere on the board
-15V: J101.a29, J101.a30, J101.c29, J101.c30; also elsewhere on the board
/CPU/Out_EN: R101.2; also elsewhere on the board
/SMPS/VOut: K101.5; also elsewhere on the board
CAN+: J101.a9; also elsewhere on the board
CAN-: J101.c9; also elsewhere on the board
GND: J101.a3, J101.a4, J101.a7, J101.a8, J101.a16, J101.a17, J101.a27, J101.a28, J101.a31, J101.a32, J101.c3, J101.c4, J101.c7, J101.c8, J101.c16, J101.c17, J101.c27, J101.c28, J101.c31, J101.c32, J102.2, Q101.2 (S), R102.1; also elsewhere on the board
unnamed: D101.2 (A), K101.6, Q101.3 (D)
unnamed: J102.1, K101.3
unnamed: Q101.1 (G), R101.1, R102.2
SCL_FM: J101.c11; also elsewhere on the board
SDA_FM: J101.a11; also elsewhere on the board

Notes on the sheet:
BACKPLANE


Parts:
C201, C203, C204: 100n; C_0805_2012Metric
C202: 2µ2; C_0805_2012Metric
C205: 1n; C_0805_2012Metric
C206, C207: 220µ; CP_Radial_D8.0mm_P5.00mm
D201: MBR745; TO-220-2_Vertical
HS201: Heatsink; SK574-50
L201: 150µ; L_Toroid_Vertical_L17.8mm_W8.1mm_P7.62mm_Bourns_5700
Q201: BD140; TO-126-3_Vertical
Q202: TIP3055; TO-218-3_Vertical
R201: 510; R_0805_2012Metric
R202: 8k9; R_0805_2012Metric
R203, R204, R207, R215, R216: 1k; R_0805_2012Metric
R205: 51k; R_0805_2012Metric
R206, R210, R214: 100; R_0805_2012Metric
R208: 30 0,5W; R_Axial_DIN0207_L6.3mm_D2.5mm_P10.16mm_Horizontal
R209, R219: 12k; R_0805_2012Metric
R211, R217: 3k9; R_0805_2012Metric
R212, R213, R221: 10k; R_0805_2012Metric
R218: 0R100 3W+; R_Axial_Power_L20.0mm_W6.4mm_P5.08mm_Vertical
R220: 39k; R_0805_2012Metric
U201: LM2902; TSSOP-14_4.4x5mm_P0.65mm
U202: TL494; SOIC-16_4.55x10.3mm_P1.27mm

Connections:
+24V: C201.1, C203.1, Q201.1 (E), Q202.2 (C), R206.1, U201.4 (V+), U202.12 (VCC); also elsewhere on the board
-5V: C204.2, U201.11 (V-); also elsewhere on the board
/CPU/I+: U201.13 (-), U201.14; also elsewhere on the board
/CPU/ISET: U202.15 (2IN-); also elsewhere on the board
/CPU/V+: U201.8, U201.9 (-); also elsewhere on the board
/CPU/VSET: R201.1; also elsewhere on the board
/SMPS/VOut: R216.2, R218.2, R220.1; also elsewhere on the board
Feedback: R220.2, R221.1, U201.5 (+), U202.1 (1IN+)
GND: C201.2, C203.2, C204.1, C205.2, C206.2, C207.2, D201.2 (A), R203.2, R204.2, R209.1, R213.2, R219.1, R221.2, U202.7 (GND), U202.9 (E1), U202.10 (E2), U202.13 (OUTCTRL); also elsewhere on the board
I_Sense: R210.1, R212.1, U201.1, U202.16 (2IN+)
unnamed: C202.1, R202.1, U202.14 (REF)
unnamed: C202.2, R202.2, R203.1, U202.4 (DTC)
unnamed: C205.1, U202.5 (CT)
unnamed: C206.1, C207.1, L201.2, R215.2, R218.1
unnamed: D201.1 (K), L201.1, Q202.3 (E), R208.2
unnamed: Q201.2 (C), Q202.1 (B), R208.1
unnamed: Q201.3 (B), R206.2, R207.1
unnamed: R201.2, R205.1, U202.2 (1IN-)
unnamed: R204.1, U202.6 (RT)
unnamed: R205.2, U202.3 (FB)
unnamed: R207.2, U202.8 (C1), U202.11 (C2)
unnamed: R209.2, R211.2, U201.12 (+)
unnamed: R210.2, R211.1
unnamed: R212.2, R216.1, U201.2 (-)
unnamed: R213.1, R215.1, U201.3 (+)
unnamed: R214.1, U201.6 (-), U201.7
unnamed: R214.2, R217.1
unnamed: R217.2, R219.2, U201.10 (+)

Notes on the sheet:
Widerstand einbauen! 100R oda so
Current Sense Amplifier
Voltage sensing


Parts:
C301, C304, C305, C306, C307, C308, C310, C317, C318: 100n; C_0805_2012Metric
C302, C303: 20p; C_0805_2012Metric
C309: 4µ7; C_0805_2012Metric
C311, C313: 1µ; C_0805_2012Metric
C312, C314: 1n; C_0805_2012Metric
C315, C316: 5n6; C_0805_2012Metric
C319, C320, C321, C322: 470n; C_0805_2012Metric
D301: CDSOT23-T24-Q; SOT-23
FB301: SMB-001
J301: Address; PinHeader_2x02_P2.54mm_Vertical
J302: SWD; JST_XH_B4B-XH-A_1x04_P2.50mm_Vertical
L301: SRF3225TAC-101Y; SRF3225TAC
Q301, Q302: BSS138; SOT-23
R301, R302, R304: 10k; R_0805_2012Metric
R303: 1M; R_0805_2012Metric
R305: 100; R_0805_2012Metric
R306, R307, R308, R309: 4k7; R_0805_2012Metric
R310, R311: 1k3; R_0805_2012Metric
R312, R313, R314, R315: 22k; R_0805_2012Metric
R316, R318: 1k; R_0805_2012Metric
R317, R319: 1k8; R_0805_2012Metric
U301: SN65HVD232; SOIC-8_3.9x4.9mm_P1.27mm
U302: STM32F103C8Tx; LQFP-48_7x7mm_P0.5mm
U303: LM2904; SOIC-8_5.23x5.23mm_P1.27mm
Y301: 8MHz; Crystal_SMD_5032-4Pin_5.0x3.2mm

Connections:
+3V3: C301.1, C304.1, C305.1, C306.1, C308.1, C309.1, C313.1, FB301.1, J301.1, J301.3, J302.1, Q301.1 (G), Q302.1 (G), R304.2, R306.2, R307.2, U301.3 (VCC), U302.1 (VBAT), U302.24 (VDD), U302.36 (VDD), U302.48 (VDD); also elsewhere on the board
+5V: R308.2, R309.2; also elsewhere on the board
+15V: C317.1, U303.8 (V+); also elsewhere on the board
-5V: C318.2, U303.4 (V-); also elsewhere on the board
/CPU/I+: C314.1, U302.11 (PA1); also elsewhere on the board
/CPU/ISET: C322.2, R318.1, U303.1; also elsewhere on the board
/CPU/Out_EN: U302.17 (PA7); also elsewhere on the board
/CPU/SWCLK: J302.3, U302.37 (PA14)
/CPU/SWDIO: J302.2, U302.34 (PA13)
/CPU/V+: C312.1, U302.10 (PA0); also elsewhere on the board
/CPU/VSET: C321.2, R316.1, U303.7; also elsewhere on the board
CAN+: D301.1 (A1), L301.2; also elsewhere on the board
CAN-: D301.2 (A2), L301.3; also elsewhere on the board
CAN_Rx: U301.4 (R), U302.45 (PB8)
CAN_Tx: U301.1 (D), U302.46 (PB9)
GND: C301.2, C302.1, C303.1, C304.2, C305.2, C306.2, C307.2, C308.2, C309.2, C310.2, C311.2, C312.2, C313.2, C314.2, C315.2, C316.2, C317.2, C318.1, C319.2, C320.2, D301.3 (common), J302.4, R301.2, R302.2, R305.1, R317.2, R319.2, U301.2 (GND), U302.8 (VSSA), U302.23 (VSS), U302.35 (VSS), U302.47 (VSS), Y301.2, Y301.4; also elsewhere on the board
unnamed: C302.2, R303.1, U302.5 (PD0), Y301.3
unnamed: C303.2, R303.2, U302.6 (PD1), Y301.1
unnamed: C307.1, R304.1, U302.7 (NRST)
unnamed: C310.1, C311.1, FB301.2, U302.9 (VDDA)
unnamed: C315.1, R310.2, R312.1
unnamed: C316.1, R311.2, R313.1
unnamed: C319.1, R314.2, U303.5 (+)
unnamed: C320.1, R315.2, U303.3 (+)
unnamed: C321.1, R312.2, R314.1
unnamed: C322.1, R313.2, R315.1
unnamed: J301.2, R301.1, U302.40 (PB4)
unnamed: J301.4, R302.1, U302.41 (PB5)
unnamed: L301.1, U301.7 (CANH)
unnamed: L301.4, U301.6 (CANL)
unnamed: R305.2, U302.44 (BOOT0)
unnamed: R316.2, R317.1, U303.6 (-)
unnamed: R318.2, R319.1, U303.2 (-)
PWM_I_SET: R311.1, U302.38 (PA15)
PWM_V_SET: R310.1, U302.39 (PB3)
SCL: Q301.2 (S), R306.1, U302.42 (PB6)
SCL_FM: Q301.3 (D), R308.1; also elsewhere on the board
SDA: Q302.2 (S), R307.1, U302.43 (PB7)
SDA_FM: Q302.3 (D), R309.1; also elsewhere on the board

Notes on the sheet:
main crystal


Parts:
C401, C402, C403, C404: 100µ; CP_Radial_D8.0mm_P5.00mm
C405, C406, C411, C412: 1µ; C_0805_2012Metric
C407, C408, C409, C410: 100n; C_0805_2012Metric
D401: SMAJ5,0A; D_SMA
D402: P6SMB26; D_SMA
D403, D404: P6SMB16; D_SMA
U401: AP1117-33; SOT-223-3_TabPin2
U402: L79L05_SO8; SOIC-8_3.9x4.9mm_P1.27mm

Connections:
+3V3: C409.1, C411.1, U401.2 (VO); also elsewhere on the board
+5V: C401.1, C405.1, C407.1, D401.2 (A2), U401.3 (VI); also elsewhere on the board
+15V: C403.1, D403.2 (A2); also elsewhere on the board
+24V: C402.1, D402.2 (A2); also elsewhere on the board
-5V: C410.1, C412.1, U402.1 (OUT); also elsewhere on the board
-15V: C404.2, C406.1, C408.1, D404.1 (A1), U402.2 (IN), U402.3 (IN), U402.6 (IN), U402.7 (IN); also elsewhere on the board
GND: C401.2, C402.2, C403.2, C404.1, C405.2, C406.2, C407.2, C408.2, C409.2, C410.2, C411.2, C412.2, D401.1 (A1), D402.1 (A1), D403.1 (A1), D404.2 (A2), U401.1 (GND), U402.5 (GND); also elsewhere on the board

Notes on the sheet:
3V3 Regulator STM32
Bulk Capacitance
TVS Protection


Board: 2 copper layers, 160.0 x 100.0 mm, 112 parts (0 on the bottom side), 65 nets.

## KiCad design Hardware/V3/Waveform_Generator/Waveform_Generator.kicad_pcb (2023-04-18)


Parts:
J101: DIN41612_02x32_AC; VG64_Euro

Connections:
+5V: J101.a1, J101.a2, J101.c1, J101.c2; also elsewhere on the board
+15V: J101.a25, J101.a26, J101.c25, J101.c26; also elsewhere on the board
+24V: J101.a5, J101.a6, J101.c5, J101.c6; also elsewhere on the board
-15V: J101.a29, J101.a30, J101.c29, J101.c30; also elsewhere on the board
CAN+: J101.a9; also elsewhere on the board
CAN-: J101.c9; also elsewhere on the board
GND: J101.a3, J101.a4, J101.a7, J101.a8, J101.a16, J101.a17, J101.a27, J101.a28, J101.a31, J101.a32, J101.c3, J101.c4, J101.c7, J101.c8, J101.c16, J101.c17, J101.c27, J101.c28, J101.c31, J101.c32; also elsewhere on the board
SCL_FM: J101.c11; also elsewhere on the board
SDA_FM: J101.a11; also elsewhere on the board

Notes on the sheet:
BACKPLANE


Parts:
C201, C205, C210, C212, C218, C219, C223, C224: 100n; C_0805_2012Metric
C202, C203: 5n6; C_0805_2012Metric
C204: 4µ7; C_0805_2012Metric
C206, C207, C208, C209: 470n; C_0805_2012Metric
C211: 10µ Tantal; CP_EIA-3216-12_Kemet-S
C213: 22p; C_0805_2012Metric
C214, C215, C221, C222: 1µ; C_0805_2012Metric
C216, C217: 10n; C_0805_2012Metric
C220: 22µ Tantal; CP_EIA-3216-12_Kemet-S
C225, C226: 2µ2 Tantal; CP_EIA-3216-12_Kemet-S
D201: LL4148; D_MiniMELF
J201: Wave_Out; PinSocket_1x02_P2.54mm_Vertical
K201: G6K-2; Relay_DPDT_Omron_G6K-2F
Q201: BSS138; SOT-23
R201, R203: 1k3; R_0805_2012Metric
R202, R204: 3k9; R_0805_2012Metric
R205: 10; R_0805_2012Metric
R206, R207, R208, R209: 22k; R_0805_2012Metric
R210, R211: 2k; R_0805_2012Metric
R212, R213, R222: 240; R_0805_2012Metric
R214: 9k1; R_0805_2012Metric
R215: 910; R_0805_2012Metric
R216, R217, R218, R219, R223: 1k; R_0805_2012Metric
R220: 200; R_0805_2012Metric
R221: 100k; R_0805_2012Metric
U201: AD9833xRM; MSOP-10_3x3mm_P0.5mm
U202: OPA2196xD; SOIC-8_3.9x4.9mm_P1.27mm
U203: LM7171xIM; SOIC-8_3.9x4.9mm_P1.27mm
U204: VCA822; MSOP-10_3x3mm_P0.5mm
X201: 25MHz; Oscillator_SMD_EuroQuartz_XO91-4Pin_7.0x5.0mm
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

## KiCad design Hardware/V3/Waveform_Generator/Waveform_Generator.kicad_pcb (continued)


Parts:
C301, C302, C303, C304: 100µ; CP_Radial_D8.0mm_P5.00mm
C305, C308, C309, C312: 1µ; C_0805_2012Metric
C306, C307, C310, C311: 100n; C_0805_2012Metric
D301: SMAJ5,0A; D_SMA
D302: P6SMB26; D_SMA
D303, D304: P6SMB16; D_SMA
U301: AP1117-33; SOT-223-3_TabPin2
U302: L7905; TO-263-2

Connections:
+3V3: C307.1, C308.1, U301.2 (VO); also elsewhere on the board
+5V: C301.1, C305.1, C306.1, D301.2 (A2), U301.3 (VI); also elsewhere on the board
+15V: C303.1, D303.2 (A2); also elsewhere on the board
+24V: C302.1, D302.2 (A2); also elsewhere on the board
-5V: C311.1, C312.1, U302.3 (VO); also elsewhere on the board
-15V: C304.2, C309.1, C310.1, D304.1 (A1), U302.2 (VI); also elsewhere on the board
GND: C301.2, C302.2, C303.2, C304.1, C305.2, C306.2, C307.2, C308.2, C309.2, C310.2, C311.2, C312.2, D301.1 (A1), D302.1 (A1), D303.1 (A1), D304.2 (A2), U301.1 (GND), U302.1 (GND); also elsewhere on the board

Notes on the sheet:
3V3 Regulator STM32
Bulk Capacitance
TVS Protection


Board: 2 copper layers, 160.0 x 100.0 mm, 105 parts (0 on the bottom side), 59 nets.

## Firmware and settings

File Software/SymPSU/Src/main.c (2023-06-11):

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
/* Includes ------------------------------------------------------------------*/
#include "main.h"
#include "adc.h"
#include "can.h"
#include "i2c.h"
#include "tim.h"
#include "gpio.h"

/* USER CODE BEGIN Includes */
#include "modlab.h"

/* USER CODE END Includes */

/* USER CODE BEGIN PD */

#define V_POS 0
#define I_POS 1
#define V_NEG 2
#define I_NEG 3

#define PWM_MAX 0xFFFF

#define VOLTP_ZERO 0x0900
#define VOLTP_MAX 1173

#define AMPP_ZERO 0x0B50
#define AMPP_REF 0x90E0
#define AMPP_MAX 1270

#define VOLTN_ZERO 0x0A70
#define VOLTN_MAX 1174

#define AMPN_ZERO 0x0B50
#define AMPN_REF 0x90E0
#define AMPN_MAX 1270

#define ADCpv_factor 0.52
#define ADCpv_offset 0
#define ADCpc_factor 0.52
#define ADCpc_offset 0
#define ADCnv_factor 0.6
#define ADCnv_offset 0
#define ADCnc_factor 0.0308
#define ADCnc_offset 0

/* USER CODE END PD */


/* USER CODE BEGIN PV */
uint8_t address;

uint16_t setValues[4], getValues[4];
uint8_t outputState = 0;

uint32_t raw[4];

// https://controllerstech.com/can-protocol-in-stm32/
CAN_TxHeaderTypeDef TxHeader;
CAN_RxHeaderTypeDef RxHeader;
uint8_t TxData[8];
uint32_t TxMailbox;
uint8_t RxData[8];
uint8_t stat = 0;

uint8_t data1[1], data2[2];

/* USER CODE END PV */

void SystemClock_Config(void);
/**
 * @brief  The application entry point.
 * @retval int
 */
int main(void)
{
  /* MCU Configuration--------------------------------------------------------*/

  /* Reset of all peripherals, Initializes the Flash interface and the Systick. */
  HAL_Init();

  /* Configure the system clock */
  SystemClock_Config();

  /* Initialize all configured peripherals */
  MX_GPIO_Init();
  MX_ADC1_Init();
  MX_CAN_Init();
  MX_I2C1_Init();
  MX_TIM1_Init();
  MX_TIM2_Init();
  /* USER CODE BEGIN 2 */
  timer_init();

  HAL_CAN_Start(&hcan);

  // get address
  address = ADDR_SymPSU | (HAL_GPIO_ReadPin(GPIOB, GPIO_PIN_4)) | (HAL_GPIO_ReadPin(GPIOB, GPIO_PIN_2) << 1);

  // calibrate AD convertor
  while (HAL_ADCEx_Calibration_Start(&hadc1) != HAL_OK)
    ;

  HAL_TIM_PWM_Start(&htim2, TIM_CHANNEL_1); // Volt+
  HAL_TIM_PWM_Start(&htim2, TIM_CHANNEL_2); // Amp+
  HAL_TIM_PWM_Start(&htim2, TIM_CHANNEL_3); // Volt-
  HAL_TIM_PWM_Start(&htim2, TIM_CHANNEL_4); // Amp-

  CAN_Filter(address);
  HAL_CAN_ActivateNotification(&hcan, CAN_IT_RX_FIFO0_MSG_PENDING);
  __enable_irq();

  /* USER CODE END 2 */

  /* Infinite loop */
  /* USER CODE BEGIN WHILE */
  while (1)
  {
    HAL_GPIO_WritePin(Out_EN_GPIO_Port, Out_EN_Pin, outputState);
    Set_All();
    delay_us(10);
    for (uint8_t i = 0; i < 4; i++)
    {
      Read_Single(i);
    }

    /* USER CODE END WHILE */

    /* USER CODE BEGIN 3 */
  }
  /* USER CODE END 3 */
}

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
/* USER CODE BEGIN 4 */

void HAL_CAN_RxFifo0MsgPendingCallback(CAN_HandleTypeDef *hcan)
{
  if (HAL_CAN_GetRxMessage(hcan, CAN_RX_FIFO0, &RxHeader, RxData) != HAL_OK)
  {
    Error_Handler();
  }

  if (RxData[0] == CMD_PING)
  {
    send_rec(address, RxData[0], stat);
  }
  else if (RxData[0] == CMD_SET16) // set 16bit
  {
    switch (RxData[1])
    {
    case V_POS_SET:
      setValues[0] = (RxData[2] << 8) | RxData[3];
      stat = 0;
      break;
    case I_POS_SET:
      setValues[1] = (RxData[2] << 8) | RxData[3];
      stat = 0;
      break;
    case V_NEG_SET:
      setValues[2] = (RxData[2] << 8) | RxData[3];
      stat = 0;
      break;
    case I_NEG_SET:
      setValues[3] = (RxData[2] << 8) | RxData[3];
      stat = 0;
      break;
    default: // Index Mismatch
      stat = 1;
      break;
    }
    send_rec(address, RxData[0], stat);
  }
  else if (RxData[0] == CMD_GET16) // get 16bit
  {
    switch (RxData[1])
    {
    case V_POS_GET:
      stat = 0;
      send_rec16(address, RxData[0], stat, getValues[0]);
      break;
    case I_POS_GET:
      stat = 0;
      send_rec16(address, RxData[0], stat, getValues[1]);
      break;
    case V_NEG_GET:
      stat = 0;
      send_rec16(address, RxData[0], stat, getValues[2]);
      break;
    case I_NEG_GET:
      stat = 0;
      send_rec16(address, RxData[0], stat, getValues[3]);
      break;
    default: // Index Mismatch
      stat = 1;
      send_rec(address, RxData[0], stat);
      break;
    }
  }
  else if (RxData[0] == CMD_ENOUT || RxData[0] == CMD_DISOUT) // set Output
  {
    outputState = !(RxData[0] & 0x01);
    stat = 0;
    send_rec(address, RxData[0], stat);
  }
  else // Unknown Command
  {
    stat = 0x40;
    send_rec(address, RxData[0], stat);
  }
}

void CAN_Filter(uint8_t addr)
{
  CAN_FilterTypeDef canfilterconfig;

  canfilterconfig.FilterActivation = CAN_FILTER_ENABLE;
  canfilterconfig.FilterBank = 0; // which filter bank to use from the assigned ones
  canfilterconfig.FilterFIFOAssignment = CAN_FILTER_FIFO0;
  canfilterconfig.FilterIdHigh = (0x500 | addr) << 5;
  canfilterconfig.FilterIdLow = 0;
  canfilterconfig.FilterMaskIdHigh = 0x1FFF;
  canfilterconfig.FilterMaskIdLow = 0xFFFF;
  canfilterconfig.FilterMode = CAN_FILTERMODE_IDMASK;
  canfilterconfig.FilterScale = CAN_FILTERSCALE_32BIT;
  canfilterconfig.SlaveStartFilterBank = 1; // how many filters to assign to the CAN1 (master can)

  HAL_CAN_ConfigFilter(&hcan, &canfilterconfig);
}

void Read_Single(uint8_t ch)
{
  switch (ch)
  {
  case 0:
    ADC_Select_CH0();
    break;
  case 1:
    ADC_Select_CH1();
    break;
  case 2:
    ADC_Select_CH2();
    break;
  case 3:
    ADC_Select_CH3();
    break;
  }

  uint8_t samples = 5;

  for (int i = 0; i < samples; i++)
  {
    delay_us(100);
    HAL_ADC_Start(&hadc1);
    HAL_ADC_PollForConversion(&hadc1, HAL_MAX_DELAY);
    raw[ch] += HAL_ADC_GetValue(&hadc1);
  }
  switch (ch)
  {
  case 0:
    getValues[ch] = ADCpv_factor * (uint16_t)(raw[ch] / samples) + ADCpv_offset;
    break;
  case 1:
    getValues[ch] = ADCpc_factor * (uint16_t)(raw[ch] / samples) + ADCpc_offset;
    break;
  case 2:
    getValues[ch] = ADCnv_factor * (uint16_t)(raw[ch] / samples) + ADCnv_offset;
    break;
  case 3:
    getValues[ch] = ADCnc_factor * (uint16_t)(raw[ch] / samples) + ADCnc_offset;
    break;
  }

  raw[ch] = 0;
}

void Set_All(void)
{
  Set_Output(V_POS, setValues[0]);
  Set_Output(I_POS, setValues[1]);
  Set_Output(V_NEG, setValues[2]);
  Set_Output(I_NEG, setValues[3]);
}

void Set_Output(uint8_t channel, uint16_t value)
{
  uint16_t temp1;
  double multiplicator;
  switch (channel)
  {
  case V_POS:
    if (value > VOLTP_MAX)
      value = VOLTP_MAX;
    multiplicator = (double)((PWM_MAX - VOLTP_ZERO) / (double)VOLTP_MAX) + 1.0;
    temp1 = (uint16_t)((double)value * multiplicator) + VOLTP_ZERO;
    TIM2->CCR1 = temp1;
    break;
  case I_POS:
    if (value > AMPP_MAX)
      value = AMPP_MAX;
    multiplicator = (double)((AMPP_REF - AMPP_ZERO) / (double)AMPP_MAX) + 1.8;
    temp1 = (uint16_t)((double)value * multiplicator) + AMPP_ZERO;
    TIM2->CCR2 = temp1;
    break;
  case V_NEG:
    if (value > VOLTN_MAX)
      value = VOLTN_MAX;
    multiplicator = (double)(((PWM_MAX - VOLTN_ZERO) / (double)VOLTN_MAX) / 1.5) + 1.0;
    temp1 = (uint16_t)((double)value * multiplicator) + VOLTN_ZERO;
    TIM2->CCR3 = temp1;
    break;
  case I_NEG:
    if(value > AMPN_MAX)
      value = AMPN_MAX;
    multiplicator = (double)((AMPN_REF - AMPN_ZERO) / (double)AMPN_MAX) + 1.8;
    temp1 = (uint16_t)((double)value * multiplicator) + AMPN_ZERO;
    TIM2->CCR4 = temp1;
    break;
  default:
    break;
  }
}

/* USER CODE END 4 */
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


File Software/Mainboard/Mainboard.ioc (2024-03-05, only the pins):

Mcu.UserName=STM32F407VGTx
PA0-WKUP.Signal=UART4_TX
PA1.Signal=UART4_RX
PA10.GPIO_Label=USB_Disconnect
PA10.Signal=GPIO_Output
PA11.Signal=USB_OTG_FS_DM
PA12.Signal=USB_OTG_FS_DP
PA13.Signal=SYS_JTMS-SWDIO
PA14.Signal=SYS_JTCK-SWCLK
PA2.GPIO_Label=RS485_DIR
PA2.Signal=GPIO_Output
PA3.GPIO_Label=ESP_CS
PA3.Signal=GPIO_Output
PA4.Signal=COMP_DAC1_group
PA5.Signal=COMP_DAC2_group
PA6.Signal=SPI1_MISO
PA7.Signal=SPI1_MOSI
PA9.Signal=USART1_TX
PB0.GPIO_Label=SD_DETECT
PB0.Signal=GPIO_Input
PB1.GPIO_Label=SD_PROTECT
PB1.Signal=GPIO_Input
PB10.Signal=I2C2_SCL
PB11.Signal=I2C2_SDA
PB13.Signal=SPI2_SCK
PB3.Signal=SPI1_SCK
PB5.Signal=SPI3_MOSI
PB6.Signal=I2C1_SCL
PB7.Signal=USART1_RX
PB9.Signal=I2C1_SDA
PC0.GPIO_Label=ESP_RDY
PC0.Signal=GPIO_Input
PC1.GPIO_Label=ESP_CS
PC1.Signal=GPIO_Output
PC10.Signal=SPI3_SCK
PC11.Signal=SPI3_MISO
PC12.Signal=SDIO_CK
PC14-OSC32_IN.Signal=RCC_OSC32_IN
PC15-OSC32_OUT.Signal=RCC_OSC32_OUT
PC2.Signal=SPI2_MISO
PC3.Signal=SPI2_MOSI
PC8.Signal=SDIO_D0
PD0.Signal=CAN1_RX
PD1.Signal=CAN1_TX
PD10.GPIO_Label=IO_0
PD10.Signal=GPIO_Output
PD11.GPIO_Label=IO_1
PD11.Signal=GPIO_Output
PD12.GPIO_Label=IO_2
PD12.Signal=GPIO_Output
PD13.GPIO_Label=IO_3
PD13.Signal=GPIO_Output
PD14.GPIO_Label=IO_4
PD14.Signal=GPIO_Output
PD15.GPIO_Label=IO_5
PD15.Signal=GPIO_Output
PD2.Signal=SDIO_CMD
PE0.GPIO_Label=LED_USB
PE0.Signal=GPIO_Output
PE1.GPIO_Label=LED_ESP
PE1.Signal=GPIO_Output
PE10.GPIO_Label=CS0
PE10.Signal=GPIO_Output
PE11.GPIO_Label=CS1
PE11.Signal=GPIO_Output
PE12.GPIO_Label=CS2
PE12.Signal=GPIO_Output
PE13.GPIO_Label=CS3
PE13.Signal=GPIO_Output
PE14.GPIO_Label=CS4
PE14.Signal=GPIO_Output
PE15.GPIO_Label=CS5
PE15.Signal=GPIO_Output
PE2.GPIO_Label=LED_SPI
PE2.Signal=GPIO_Output
PE3.GPIO_Label=LED_I2C
PE3.Signal=GPIO_Output
PE4.GPIO_Label=LED_SD
PE4.Signal=GPIO_Output
PE5.GPIO_Label=LED_CAN
PE5.Signal=GPIO_Output
PE6.GPIO_Label=LED_TFT
PE6.Signal=GPIO_Output
PE7.GPIO_Label=LED_485
PE7.Signal=GPIO_Output
PH0-OSC_IN.Signal=RCC_OSC_IN
PH1-OSC_OUT.Signal=RCC_OSC_OUT

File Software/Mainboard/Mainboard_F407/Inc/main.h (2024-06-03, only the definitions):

#define LED_SPI_Pin GPIO_PIN_2
#define LED_SPI_GPIO_Port GPIOE
#define LED_I2C_Pin GPIO_PIN_3
#define LED_I2C_GPIO_Port GPIOE
#define LED_SD_Pin GPIO_PIN_4
#define LED_SD_GPIO_Port GPIOE
#define LED_CAN_Pin GPIO_PIN_5
#define LED_CAN_GPIO_Port GPIOE
#define LED_TFT_Pin GPIO_PIN_6
#define LED_TFT_GPIO_Port GPIOE
#define ESP_RDY_Pin GPIO_PIN_0
#define ESP_RDY_GPIO_Port GPIOC
#define ESP_CS_Pin GPIO_PIN_1
#define ESP_CS_GPIO_Port GPIOC
#define RS485_DIR_Pin GPIO_PIN_2
#define RS485_DIR_GPIO_Port GPIOA
#define ESP_CSA3_Pin GPIO_PIN_3
#define ESP_CSA3_GPIO_Port GPIOA
#define SD_DETECT_Pin GPIO_PIN_0
#define SD_DETECT_GPIO_Port GPIOB
#define SD_PROTECT_Pin GPIO_PIN_1
#define SD_PROTECT_GPIO_Port GPIOB
#define LED_485_Pin GPIO_PIN_7
#define LED_485_GPIO_Port GPIOE
#define CS0_Pin GPIO_PIN_10
#define CS0_GPIO_Port GPIOE
#define CS1_Pin GPIO_PIN_11
#define CS1_GPIO_Port GPIOE
#define CS2_Pin GPIO_PIN_12
#define CS2_GPIO_Port GPIOE
#define CS3_Pin GPIO_PIN_13
#define CS3_GPIO_Port GPIOE
#define CS4_Pin GPIO_PIN_14
#define CS4_GPIO_Port GPIOE
#define CS5_Pin GPIO_PIN_15
#define CS5_GPIO_Port GPIOE
#define IO_0_Pin GPIO_PIN_10
#define IO_0_GPIO_Port GPIOD
#define IO_1_Pin GPIO_PIN_11
#define IO_1_GPIO_Port GPIOD
#define IO_2_Pin GPIO_PIN_12
#define IO_2_GPIO_Port GPIOD
#define IO_3_Pin GPIO_PIN_13
#define IO_3_GPIO_Port GPIOD
#define IO_4_Pin GPIO_PIN_14
#define IO_4_GPIO_Port GPIOD
#define IO_5_Pin GPIO_PIN_15
#define IO_5_GPIO_Port GPIOD
#define USB_Disconnect_Pin GPIO_PIN_10
#define USB_Disconnect_GPIO_Port GPIOA
#define LED_USB_Pin GPIO_PIN_0
#define LED_USB_GPIO_Port GPIOE
#define LED_ESP_Pin GPIO_PIN_1
#define LED_ESP_GPIO_Port GPIOE

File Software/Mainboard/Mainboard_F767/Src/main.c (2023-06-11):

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
/* Includes ------------------------------------------------------------------*/
#include "main.h"
#include "can.h"
#include "dac.h"
#include "dma.h"
#include "fatfs.h"
#include "i2c.h"
#include "rtc.h"
#include "sdmmc.h"
#include "spi.h"
#include "tim.h"
#include "usart.h"
#include "usb_device.h"
#include "gpio.h"
#include "fmc.h"

/* USER CODE BEGIN Includes */
#include "usbd_cdc_if.h"
#include "tft.h"
#include "modlab.h"
#include <stdio.h>
#include "usb_mon.h"


/* USER CODE END Includes */


/* USER CODE BEGIN PV */

uint16_t counter;
uint32_t tick_loop;
uint32_t tick_loop_old;

uint8_t address = 0;



/* USER CODE END PV */

void SystemClock_Config(void);
/**
  * @brief  The application entry point.
  * @retval int
  */
int main(void)
{
  /* MCU Configuration--------------------------------------------------------*/

  /* Reset of all peripherals, Initializes the Flash interface and the Systick. */
  HAL_Init();

  /* Configure the system clock */
  SystemClock_Config();

  /* Initialize all configured peripherals */
  MX_GPIO_Init();
  MX_SDMMC1_SD_Init();
  MX_FATFS_Init();
  MX_CAN1_Init();
  MX_I2C1_Init();
  MX_I2C2_Init();
  MX_RTC_Init();
  MX_SPI1_Init();
  MX_SPI2_Init();
  MX_UART7_Init();
  MX_DAC_Init();
  MX_FMC_Init();
  MX_SPI3_Init();
  MX_SPI4_Init();
  MX_TIM1_Init();
  MX_USB_DEVICE_Init();
  MX_DMA_Init();
  MX_USART1_UART_Init();
  /* USER CODE BEGIN 2 */

  timer_init();

  LEDs_Off();
  HAL_GPIO_WritePin(USB_Disconnect_GPIO_Port, USB_Disconnect_Pin, 1);
  HAL_Delay(200);
  //HAL_GPIO_WritePin(USB_Disconnect_GPIO_Port, USB_Disconnect_Pin, 0);

  CAN_Filter();
  HAL_CAN_Start(&hcan1);
  HAL_CAN_ActivateNotification(&hcan1, CAN_IT_RX_FIFO0_MSG_PENDING);

  tft_init();
  HAL_UART_Receive_IT(&huart1, RxBuffer, 1); // Get TFT Command
  __enable_irq();


  HAL_Delay(500);
	scan_dev();

//https://controllerstech.com/can-protocol-in-stm32/

  HAL_Delay(500);
  tft_reset();
 


  tick_loop = HAL_GetTick() + 1000;
  /* USER CODE END 2 */

  /* Infinite loop */
  /* USER CODE BEGIN WHILE */
  while (1)
  {
    if((tft_cmd == CMD_PAGESET) && (setdata == 1))
    {
      HAL_Delay(10);
      enableblock = 1;
      setdata = 0;
    }
    
    switch (tft_page)
    {
      case PAGE_MAIN:
        main_page_loop();
        break;
      case PAGE_DTEST:
        diode_page_loop();
        break;
      case PAGE_FGEN:
        fgen_page_loop();
        break;
      case PAGE_SYMPSU:
        sympsu_page_loop();
        break;
      case PAGE_SMPS:
        smps_page_loop();
        break;
      case PAGE_LOAD:
        load_page_loop();
        break;
    }

    if(tick_loop < (HAL_GetTick() - 1000))
    {
      tick_loop = HAL_GetTick();
      sprintf(out_buf, "USB Test Zyklus, Tick-Time = %d\n", HAL_GetTick());
      CDC_Transmit_FS((uint8_t *)out_buf, strlen(out_buf));
    }
    
  }
  /* USER CODE END 3 */
}

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
/* USER CODE BEGIN 4 */

void HAL_UART_RxCpltCallback(UART_HandleTypeDef *huart)
{

  /**
   * TFT Interrupt Functions
  */
  tft_parse();


}



void HAL_CAN_RxFifo0MsgPendingCallback(CAN_HandleTypeDef *hcan)
{
  if (HAL_CAN_GetRxMessage(hcan, CAN_RX_FIFO0, &RxHeader, RxData) != HAL_OK)
  {
    Error_Handler();
  }
  
  can_parse();
}

void CAN_Filter (void)
{
  //no filtering, Message types decoded in interrupt
  CAN_FilterTypeDef canfilterconfig;

  canfilterconfig.FilterActivation = CAN_FILTER_ENABLE;
  canfilterconfig.FilterBank = 0; 
  canfilterconfig.FilterFIFOAssignment = CAN_FILTER_FIFO0;
  canfilterconfig.FilterIdHigh = 0x0000;
  canfilterconfig.FilterIdLow = 0;
  canfilterconfig.FilterMaskIdHigh = 0; 
  canfilterconfig.FilterMaskIdLow = 0x0000;
  canfilterconfig.FilterMode = CAN_FILTERMODE_IDMASK;
  canfilterconfig.FilterScale = CAN_FILTERSCALE_32BIT;
  canfilterconfig.SlaveStartFilterBank = 1; 

  HAL_CAN_ConfigFilter(&hcan1, &canfilterconfig);
}

void LEDs_Off(void)
{
  HAL_GPIO_WritePin(LED_CAN_GPIO_Port,  LED_CAN_Pin,  0);   //CAN
  HAL_GPIO_WritePin(LED_485_GPIO_Port,  LED_485_Pin,  0);   //485
  HAL_GPIO_WritePin(LED_I2C1_GPIO_Port, LED_I2C1_Pin, 0);   //I2C1
  HAL_GPIO_WritePin(LED_I2C2_GPIO_Port, LED_I2C2_Pin, 0);   //I2C1
  HAL_GPIO_WritePin(LED_ESP_GPIO_Port,  LED_ESP_Pin,  0);   //ESP
  HAL_GPIO_WritePin(LED_SD_GPIO_Port,   LED_SD_Pin,   0);   //SD
  HAL_GPIO_WritePin(LED_SPI3_GPIO_Port, LED_SPI3_Pin, 0);   //SPI3
  HAL_GPIO_WritePin(LED_SPI4_GPIO_Port, LED_SPI4_Pin, 0);   //SPI4
}


/* USER CODE END 4 */
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


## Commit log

2023-03-02 Removed History due to issues
    [1x.stp, 36-TE.stp, 4x.stp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]
2023-03-05 Edit Mainboard IOC for Nextion Display Implement first Nextion Display Code start tft library for nextion display
    [Mainboard-NEXTION.3mf, Mainboard.FCStd]
2023-03-06 TFT Update Implementing general TFT functions Implementing module loops Implementing more functionality slight documentation update regarding TFT
    [Mainboard-NEXTION.3mf, Mainboard.FCStd]
2023-03-13 start work on Electronic Load
    [Electronic_Load.kicad_pcb, Electronic_Load.kicad_sch, cpu.kicad_sch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]
2023-03-14 finalize electronic load; Readme Update
    [Electronic_Load.kicad_pcb]
2023-03-28 Load update
    [12-TE.stp, Load.3mf, Load.FCStd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]
2023-04-18 Code Update Implement full code for Waveform Generator Small doc update Readme Update
    [Waveform_Generator.kicad_pcb, Waveform_Generator.kicad_sch, analog.kicad_sch]
2023-04-24 SMPS Schematic and PCB Bugfix
    [Power_SMPS.kicad_pcb, Power_SMPS.kicad_sch, cpu.kicad_sch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]
2023-04-30 PCB Update
    [Power_SMPS.kicad_sch, cpu.kicad_sch, filters.kicad_sch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]
2023-06-11 GPN Update Bugfixes on Function Generator New code for SymPSU
    [Load.ioc, Software.ioc, main.c]
2024-03-05 Add V2 Mainboard
    [Mainboard.kicad_pcb, Mainboard.kicad_sch, Mainboard_767.csv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]

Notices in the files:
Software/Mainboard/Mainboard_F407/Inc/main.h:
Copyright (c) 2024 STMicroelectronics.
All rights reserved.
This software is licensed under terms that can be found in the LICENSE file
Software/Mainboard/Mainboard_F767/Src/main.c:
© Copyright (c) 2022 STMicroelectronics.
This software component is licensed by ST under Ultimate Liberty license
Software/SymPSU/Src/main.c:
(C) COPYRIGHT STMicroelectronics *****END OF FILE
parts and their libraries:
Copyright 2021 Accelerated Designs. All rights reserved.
